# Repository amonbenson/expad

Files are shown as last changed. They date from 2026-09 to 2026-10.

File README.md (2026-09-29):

# expad - Expression Adapter

A four-jack USB MIDI adapter for expression and sustain pedals, built on a Raspberry Pi Pico 2 W.
It works out what is plugged into each jack - whichever contact a pedal's wiper is on, and whether
it is a potentiometer, a switch or a two-wire rheostat - and sends every pedal's position as a MIDI
control change, ~190 times per second. A WiFi access point serves a web interface for watching the
jacks and changing the settings live.

## Hardware

The PCB is the KiCad project in [hardware/](hardware/). Each jack's tip, ring and sleeve (plus the
tip's switch contact, for plug detection) can be switched to a shared 1 kΩ pull-up to the 2.5 V
reference or a 1 kΩ pull-down, and is read back by one of two AD7718 24-bit ADCs. The four
WS2812B LEDs below the jacks glow a dim white while a plug is in but no known pedal is behind it.
A recognised pedal is announced for a second in its own color - purple for an expression pedal,
lime for a footswitch, yellow for a rheostat - after which the LED shows the value it sends, from
dark red at 0 through red, orange and yellow to white at 127. They run off a linear regulator, so
the firmware caps them at ~4% brightness.

## Supported pedals

| Pedal | Cable | Shown as | Value |
|---|---|---|---|
| Expression pedal (potentiometer), wiper on tip or ring | stereo (TRS) | Tracking | wiper position, counting up away from the sleeve |
| Sustain pedal / footswitch | mono (TS) or stereo | Switch | 100% closed, 0% open |
| Two-wire (rheostat) expression pedal | mono or stereo | Rheostat | resistance against the nearest standard value (10k, 25k, 50k ...) |
| Anything else (dual footswitches, other wirings) | | Other pedal | none |

Pedals are recognised within ~0.1 s of being plugged in, and unplugging is noticed just as fast.

- A normally-closed sustain pedal, or an expression pedal wired the other way round, needs
  **Invert**.
- A rheostat pedal on a mono cable first reads as a potentiometer at rest, until its resistance has
  changed by a fifth.
- A potentiometer pedal needs a stereo cable: with a mono one, most pedals short their ring to the
  sleeve, which leaves a resistance that rises and falls again over the travel.
- A mono cable with nothing at the other end reads as a released switch.

## Using it

1. Plug the Pico into a computer over USB. It shows up as a USB MIDI device; by default the
   first two jacks send CC 11 (Expression) and the last two CC 1 (Modulation), all on MIDI
   channel 1.
2. Join the WiFi network **Expression Adapter** (password: the one it was built with, see below).
   Phones, tablets and computers open the interface by themselves as the network's sign-in page;
   otherwise open http://192.168.4.1.
3. Per jack, set the MIDI channel and controller, **Invert**, and the **Range**: move the pedal to
   one end and press **Min**, to the other and press **Max**, so its travel covers the full MIDI
   range. **Drive** bends the response against a pedal's nonlinear track: centered is linear,
   turning it right makes the value rise early in the travel, left late (double-click resets it).
   **Wiper** only matters for pedals whose wiper is on the ring or sleeve and that rest on an
   end stop when plugged in; **Auto** handles the common wirings. The LED slider sets the
   brightness.

The topology panel on the right draws the selected jack's measured network.

## Setup

Needs Rust, Node.js (see `engines` in [web/package.json](web/package.json)) for the web interface,
and a debug probe (e.g. a Raspberry Pi Debug Probe) on the Pico's SWD pins.

```bash
rustup target add thumbv8m.main-none-eabihf
cargo install probe-rs-tools --locked
cp .env.example .env   # then set EXPAD_WIFI_PASSWORD (8-63 characters)
```

## Building and flashing

```bash
cargo run --bin expression_controller   # build, flash and show the log
cargo run --bin expression_controller --features no-wifi   # the same with the radio off
cargo build --no-default-features       # without the web interface (no Node.js needed)
```

The other programs in [src/bin/](src/bin/) test parts of the board:

| Program | What it does |
|---|---|
| `detect_pin_mapping` | checks every contact's switches and ADC input against the wiring table (unplug all jacks) |
| `capture` | holds every contact in one state and logs every ADC input, for noise measurements |
| `adc_characterization` | compares ADC filter rates and SPI settings on a pedal in jack 1 |
| `potentiometer` | reads a pedal in jack 1 and shows its position on the LEDs |
| `rainbow` | LED strip test |
| `midi_loopback` | echoes every USB MIDI message back to the host |
| `web_interface` | the web interface with made-up data |

## Development

```bash
cargo test -p expad-topology --target x86_64-pc-windows-msvc   # solver tests, on your host triple
cargo fmt
cargo clippy --all-features
cd web && npm run dev:mock   # web interface against a simulated device, no hardware needed
```

[AGENTS.md](AGENTS.md) describes the repository in detail, and
[docs/fast-tracking.md](docs/fast-tracking.md) the measurements and design behind the pedal
detection.

## General TODOs
- missing standard trait implementations for all types (Debug, Default, Clone, Copy, PartialEq, Eq, etc.)
- missing with_field builder methods for all config structs
- thiserror (nostd) or similar better error handling

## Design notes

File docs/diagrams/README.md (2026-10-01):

# Diagrams

| File | What it is |
|---|---|
| `jack-monitor-states.tex` | Source: TikZ state diagram of `JackMonitor` (topology/src/monitor.rs) and the output stage of expression_controller.rs |
| `jack-monitor-states.pdf` | Vector export for LaTeX documents |
| `jack-monitor-states.svg` | Vector export for PowerPoint and the web (text converted to outlines) |
| `jack-monitor-states.png` | 600 dpi raster fallback |
| `jack-monitor-overview.tex` | Source: the same as four stages in large type, for slides (`.pdf`, `.svg`, `.png` exports alike) |

## Tools

Everything comes with a standard TeX Live installation; the exports were made with:

- **pdflatex**: pdfTeX 3.141592653-2.6-1.40.29 (TeX Live 2026), turning the `.tex` into the PDF
- **pdftocairo** 26.09.0 (Poppler, bundled with TeX Live on Windows, `brew install poppler` on macOS), turning the PDF into the SVG and PNG
- LaTeX packages: `standalone`, TikZ/PGF 3.1.11a (libraries `arrows.meta`, `positioning`, `calc`,
  `shapes.geometric`), `helvet` (Helvetica), `mathastext`, `lmodern`, `amssymb`

## Rebuilding

From this directory, for each diagram (`jack-monitor-states` or `jack-monitor-overview`):

```bash
name=jack-monitor-states
pdflatex $name.tex
pdftocairo -svg $name.pdf $name.svg
pdftocairo -png -r 600 -singlefile $name.pdf $name
```

`pdflatex` also leaves `.aux` and `.log` files behind; delete them, or pass
`-output-directory=<somewhere else>` and copy the PDF back.

## Using the exports

- **LaTeX**: `\includegraphics[width=\linewidth]{jack-monitor-states.pdf}` (it suits a landscape
  page or the full text width).
- **PowerPoint**: *Insert > Pictures* with the SVG. It stays sharp at any size; *Convert to Shape*
  makes its parts editable, but the text stays outlines - edit the `.tex` source for wording.
- **Slides**: the overview is 32 cm wide, about a 16:9 slide, so at that width its type keeps its
  size (18 pt names, 15 pt text). To reveal it step by step, cover each part with a rectangle in
  the slide's background color: every stage is a column that owns the gap to its left with the
  arrows into it, and the two ways back run in their own strips above and below the columns.

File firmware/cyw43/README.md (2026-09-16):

# CYW43439 firmware blobs

WiFi firmware, country locale matrix (CLM), and NVRAM for the Pico 2 W's CYW43439 chip, embedded by
[src/hal/wifi/access_point.rs](../../src/hal/wifi/access_point.rs).

Copied unmodified from [embassy `cyw43-firmware`](https://github.com/embassy-rs/embassy/tree/embassy-rp-v0.10.0/cyw43-firmware)
(tag `embassy-rp-v0.10.0`), which in turn sources them from
[georgerobotics/cyw43-driver](https://github.com/georgerobotics/cyw43-driver/tree/main/firmware).

Licensed under the [Infineon Permissive Binary License](./LICENSE-permissive-binary-license-1.0.txt).

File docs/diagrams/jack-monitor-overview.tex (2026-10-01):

% Overview of one jack's JackMonitor (topology/src/monitor.rs) and the output stage of
% expression_controller.rs for slides: few words, large type. jack-monitor-states.tex has the
% details.
%
% Build (TeX Live):  pdflatex jack-monitor-overview.tex
%   SVG for PowerPoint:  pdftocairo -svg jack-monitor-overview.pdf jack-monitor-overview.svg
%   PNG fallback:        pdftocairo -png -r 600 -singlefile jack-monitor-overview.pdf jack-monitor-overview
%
% Layout for revealing one part after another: the four stages are columns, read left to right,
% and each one owns the gap to its left with the arrows into it. The two ways back run in their
% own strips, above and below the columns, from border to border. So every part can be covered
% by one rectangle. The canvas is 32 cm wide, so at the width of a 16:9 slide the type keeps its
% size in pt.

\documentclass[tikz, border=10pt]{standalone}
\usepackage[scaled]{helvet}
\renewcommand{\familydefault}{\sfdefault}
\usepackage[T1]{fontenc}
\usetikzlibrary{arrows.meta}

% The palette of jack-monitor-states.tex.
\definecolor{detect}{HTML}{0284C7}      \definecolor{detectFill}{HTML}{F0F9FF}
\definecolor{ident}{HTML}{7C3AED}       \definecolor{identFill}{HTML}{F5F3FF}
\definecolor{follow}{HTML}{059669}      \definecolor{followFill}{HTML}{ECFDF5}
\definecolor{output}{HTML}{D97706}      \definecolor{outputFill}{HTML}{FFFBEB}
\definecolor{unplug}{HTML}{E11D48}
\definecolor{ink}{HTML}{1E293B}
\definecolor{muted}{HTML}{475569}
\definecolor{wire}{HTML}{334155}

% A state's name and its description.
\newcommand{\st}[1]{{\bfseries\fontsize{18}{22}\selectfont\color{ink}#1}}

\tikzset{
  >={Stealth[length=10pt, width=8pt]},
  every node/.style={text=ink},
  group/.style={draw=#1, line width=1.6pt, rounded corners=10pt},
  groupTitle/.style={anchor=north west, font=\bfseries\fontsize{22}{26}\selectfont, text=#1},
  question/.style={anchor=north west, font=\fontsize{16}{19}\selectfont, text=muted},
  state/.style={draw=#1, fill=white, line width=1.6pt, rounded corners=5pt, align=center,
    inner xsep=6pt, inner ysep=7pt, font=\fontsize{15}{18}\selectfont, text=muted},
  trans/.style={->, line width=1.6pt, draw=wire, rounded corners=6pt},
  bus/.style={line width=1.6pt, draw=wire, rounded corners=6pt},
  corridor/.style={->, line width=1.8pt, draw=#1, dash pattern=on 9pt off 5pt, rounded corners=6pt},
  lbl/.style={font=\fontsize{15}{18}\selectfont, text=muted, align=center, inner sep=6pt},
  junction/.style={circle, fill=wire, inner sep=0pt, minimum size=8pt},
}

\begin{document}
\hyphenpenalty=10000
\exhyphenpenalty=10000
\begin{tikzpicture}

  % ---------------------------------------------------------------- plug detection
  \fill[detectFill] (0, 2.4) rectangle (6.2, 13.2);
  \draw[group=detect] (0, 2.4) rectangle (6.2, 13.2);
  \node[groupTitle=detect] at (0.3, 12.9) {Plug detection};
  \node[question] at (0.3, 12.1) {Is a plug in?};

  \node[circle, fill=ink, minimum size=11pt, inner sep=0pt] (start) at (0.5, 10.4) {};
  \node[state=detect, text width=4.0cm] (rails) at (3.74, 10.4)
    {\st{Measure rails}\\ reference levels};
  \draw[trans] (start) -- (rails);

  \node[state=detect, text width=4.0cm] (empty) at (3.74, 7.6)
    {\st{Empty}\\ tip switch polled\\ every 50\,ms};
  \draw[trans] (rails) -- (empty);

  % ---------------------------------------------------------------- identification
  \fill[identFill] (8.4, 2.4) rectangle (15.4, 13.2);
  \draw[group=ident] (8.4, 2.4) rectangle (15.4, 13.2);
  \node[groupTitle=ident] at (8.7, 12.9) {Identification};
  \node[question] at (8.7, 12.1) {What is plugged in?};

  \node[state=ident, text width=4.6cm] (solve) at (11.6, 7.6)
    {\st{Solve}\\ arm pairs driven,\\ every tap read};
  \draw[trans] (empty) -- (solve);
  \node[lbl, anchor=south] at (7.3, 7.6) {plug in};

  \node[state=ident, text width=4.6cm] (classify) at (11.6, 3.9)
    {\st{Classify}\\ which network?};
  \draw[trans] (10.9, 0 |- solve.south) -- (10.9, 0 |- classify.north);
  \draw[trans] (12.3, 0 |- classify.north) -- (12.3, 0 |- solve.south)
    node[lbl, midway, right] {unknown:\\solve again};

  % ---------------------------------------------------------------- following
  \fill[followFill] (17.6, 2.4) rectangle (23.8, 13.2);
  \draw[group=follow] (17.6, 2.4) rectangle (23.8, 13.2);
  \node[groupTitle=follow] at (17.9, 12.9) {Following};
  \node[question] at (17.9, 12.1) {Where is the pedal?};

  \node[state=follow, text width=4.9cm] (potentiometer) at (20.7, 9.9)
    {\st{Potentiometer}\\ wiper read between\\ driven track ends};
  \node[state=follow, text width=4.9cm] (element) at (20.7, 6.9)
    {\st{Switch / rheostat}\\ tip against sleeve};
  \node[state=follow, text width=4.9cm] (open) at (20.7, 3.9)
    {\st{Open plug}\\ waiting for contact};

  \node[junction] (split) at (16.5, 3.9) {};
  \draw[bus] (classify.east) -- (split);
  \draw[bus] (split) -- (16.5, 9.9);
  \draw[trans] (16.5, 9.9) -- (potentiometer.west);
  \draw[trans] (16.5, 6.9) -- (element.west);
  \draw[trans] (split) -- (open.west);

  % ---------------------------------------------------------------- output
  \fill[outputFill] (26.0, 2.4) rectangle (32.0, 13.2);
  \draw[group=output] (26.0, 2.4) rectangle (32.0, 13.2);
  \node[groupTitle=output] at (26.3, 12.9) {Output};
  \node[question] at (26.3, 12.1) {What is sent?};

  \node[state=output, text width=4.6cm] (map) at (29.0, 9.9)
    {\st{Map to value}\\ range, invert, curve};
  \draw[trans] (23.8, 9.9) -- (map.west);
  \node[lbl, anchor=south] at (24.9, 9.9) {position};

  \foreach \name/\title/\y in {midi/USB MIDI/7.6, led/LED/5.8, web/Web interface/4.0} {
    \node[state=output, text width=4.0cm, anchor=west] (\name) at (27.1, \y) {\st{\title}};
    \draw[trans] (26.65, \y) -- (\name.west);
  }
  \draw[bus] (26.65, 0 |- map.south) -- (26.65, 4.0);

  % ---------------------------------------------------------------- ways back
  \draw[corridor=ident] (22.9, 13.2) -- (22.9, 14.1) -- (14.6, 14.1) -- (14.6, 13.2);
  \node[lbl, anchor=south, text=ident] at (18.75, 14.1) {no longer matches: identify again};

  \draw[corridor=unplug] (22.9, 2.4) -- (22.9, 1.3) -- (2.9, 1.3) -- (2.9, 2.4);
  \node[lbl, anchor=north, text=unplug] at (12.9, 1.3) {plug pulled: back to plug detection};

\end{tikzpicture}
\end{document}

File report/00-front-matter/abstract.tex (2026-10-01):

% !TEX root = ../main.tex

\chapter*{Abstract}

\scaffold{
  One paragraph of about ten sentences, no citations, no abbreviation without its full form (writing guide, section 3.2). Write it last. Sentence order and content:
  \begin{enumerate}
    \item Context: expression pedals are passive potentiometers operated by foot that musicians use to change a sound parameter continuously while both hands stay on the instrument.
    \item Problem: no wiring standard exists; the wiper sits on the tip or on the ring, some pedals have two wires only, and a pedal on a mismatched input reads reversed, nonlinear or not at all.
    \item What the project presents: a four-jack interface that identifies what is plugged in electrically and sends its position as a MIDI control change over USB.
    \item Parts, as one sentence with a dash-enclosed enumeration: analog switches that pull every jack contact up or down through \qty{1}{\kilo\ohm} resistors, two 24-bit sigma-delta analog-to-digital converters (written out, since the abstract defines no abbreviations) referenced to the same \qty{2.5}{\volt} rail, and a Raspberry Pi Pico~2~W running firmware in Rust.
    \item Central method: each pedal is modelled as a three-terminal star network, whose arm resistances follow from voltages measured while one contact is driven high, one low and the third left floating.
    \item How it follows the pedal: once identified, a potentiometer is read with a single conversion of its wiper between its driven track ends; switches and two-wire rheostats are followed through the tip.
    \item Development and verification: the solver and the per-jack state machine run and are tested on the host against a simulated network; the hardware was verified with a self-test and oscilloscope measurements.
    \item Results, with numbers: about 188 position updates per second for a single pedal (2.6 for repeated full identification), recognition within 65 to \qty{95}{\milli\second} (about \qty{300}{\milli\second} when the reference levels are re-measured first), and a position noise of \num{274} parts per million, about 1/29 of a MIDI step.
    \item Concluding sentence: what the results show, i.e. that an unknown passive pedal can be identified in place with switchable pull resistors and a slow high-resolution ADC, and followed fast enough for live use.
  \end{enumerate}
}

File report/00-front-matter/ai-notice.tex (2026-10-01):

% !TEX root = ../main.tex

\chapter*{Notice on the Use of AI Tools}

\scaffold{
  One paragraph, one sentence per tool: product name, manufacturer, version, purpose, citation (writing guide, section 3.1). Name the concrete work products each tool contributed to and cite the repository \cite{benson2026expad} where they live. The facts below are taken from the Claude Code session logs of the project.

  \begin{itemize}
    \item Anthropic Claude Code \cite{anthropic2026claudecode}, versions 2.1.227 to 2.1.284, with the models Claude Opus~5.5 \cite{anthropic2026opus55}, Claude Opus~5 \cite{anthropic2026opus5} and Claude Sonnet~5 \cite{anthropic2026sonnet5}. Purposes: implementation of the firmware (drivers for the AD7718, the pull switches, the LEDs, USB MIDI and WiFi; the port of the solver from the simulator \cite{benson2026topologysim}; the jack state machine and its host tests), the web interface, parsing the KiCad netlist into the board table, the evaluation scripts for the oscilloscope data (\code{measurements/create\_plots.py}, OCR extraction of scope statistics), the TikZ state diagram, the project documentation, the measurement guide, and the scaffold of this report.
    \item Anthropic Claude (claude.ai chat): early concept research on the measurement circuit, the network identification and component selection.
  \end{itemize}

  Final sentence: all AI-generated content was reviewed and verified by the author, who takes full responsibility for the final content of this work.
}

\openquestion{AI tools in the chats and in the text}{
  The model and version used in the claude.ai chats are not recorded in the repository. Name them. State also whether an AI tool is used for grammar and spell checking of the final text, as in the reference report.
}

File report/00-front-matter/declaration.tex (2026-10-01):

% !TEX root = ../main.tex
% Fixed text of the institution; only place, date and signature change.

\chapter*{Eidesstattliche Erklärung}
\thispagestyle{empty}

\begin{german}
Hiermit versichere ich, dass ich die vorliegende Arbeit eigenständig ohne Hilfe Dritter und ausschließlich unter Verwendung der aufgeführten Quellen und Hilfsmittel angefertigt habe. Alle Stellen die den benutzten Quellen und Hilfsmitteln unverändert oder sinngemäß entnommen sind, habe ich als solche kenntlich gemacht.

Sofern generische KI-Tools verwendet wurden, habe ich Produktnamen, Hersteller, die jeweils verwendete Softwareversion und die jeweiligen Einsatzzwecke (z.\,B. sprachliche Überprüfung und Verbesserung der Texte, systematische Recherche) benannt. Ich verantworte die Auswahl, die Übernahme und sämtliche Ergebnisse des von mir verwendeten KI-generierten Outputs vollumfänglich selbst.

Die Satzung zur Sicherung guter wissenschaftlicher Praxis an der TU Berlin vom 8. März 2017 habe ich zur Kenntnis genommen.

\vspace{5mm}
Berlin, \today

\vspace{20mm}
\rule{80mm}{0.4pt}\\
(\authorname)
\end{german}

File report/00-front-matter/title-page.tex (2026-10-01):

% !TEX root = ../main.tex

\begin{titlepage}
  \centering
  

  \vspace{10mm}
  {\large\bfseries
    Technische Universität Berlin\\
    Faculty IV Electrical Engineering and Computer Science\\
    Institute of Energy and Automation Technology\\
    Chair of Sensor and Actuator Systems\par}

  \vspace{10mm}
  {\Huge\bfseries \documenttype\par}

  \vspace{10mm}
  {\LARGE\bfseries \reporttitle\par}

  \vspace{10mm}
  In the course\\
  \coursename\\
  \submissiondate

  \vspace{20mm}
  \authorname\ (\matriculationnumber)

  \vspace{20mm}
  Supervisor: \supervisor\\
  Assisted by \assistant

  \vfill
\end{titlepage}

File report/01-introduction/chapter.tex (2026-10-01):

% !TEX root = ../main.tex

\chapter{Introduction}
\label{ch:introduction}

\scaffold{
  Purpose of the chapter (writing guide, section 3.3): background, the niche of the project, motivation and the minimum of fundamentals; no figures, no results, no chapter roadmap. Five paragraphs. The reader is electronics-literate but does not know what an expression pedal is.
}

\scaffold{
  \textbf{Paragraph 1, the field.} Musicians who play an instrument with both hands, a keyboard or a guitar, change sound parameters such as volume, filter cutoff or effect intensity with their feet. An expression pedal is the continuous variant of these foot controllers, in contrast to a sustain pedal, which is a switch \cite{mission2014expression}. Expression pedals are connected to keyboards, amplifiers, effect units and MIDI controllers \cite{mission2014expression}; to control software on a computer, the pedal position has to reach the computer as MIDI data. By the end of the paragraph the reader knows what an expression pedal is used for and why it is connected to a computer at all.
}

\scaffold{
  \textbf{Paragraph 2, the underlying structure.} Inside, an expression pedal is passive: a potentiometer whose wiper is moved by the treadle, connected to a \qty{6.35}{\milli\metre} jack. The connected device supplies a voltage across the track and reads the wiper voltage back as the position \cite{mission2014expression, nonlinearlabs2026pedals}. Give the typical track resistance of \qtyrange{5}{50}{\kilo\ohm}, with some devices expecting \qty{100}{\kilo\ohm} to \qty{500}{\kilo\ohm} \cite{mission2014expression}. Introduce the terms tip, ring and sleeve here, once, because the rest of the report uses them; the term \emph{contact} denotes one of them.
}

\scaffold{
  \textbf{Paragraph 3, the difficulty.} No standard defines which contact carries the wiper \cite{mission2014expression}. Two TRS wirings dominate: the wiper on the tip (Boss/Roland, \enquote{tip-active}) and the wiper on the ring (Yamaha, \enquote{ring-active}) \cite{nonlinearlabs2026pedals}; further pedals connect only tip and sleeve, as a variable resistor (rheostat) \cite{nonlinearlabs2026pedals, mission2014expression}. A pedal on an input that expects another wiring reads reversed, with a limited range, or not at all \cite{mission2014expression}. Manufacturers mitigate this with polarity switches on the pedal \cite{maudio2026exp, nonlinearlabs2026pedals}, which the user has to know about and set. State in one sentence that the pedal itself cannot tell which convention it follows; only a measurement of its network can.
}

\scaffold{
  \textbf{Paragraph 4, \enquote{Concretely, \ldots}.} Concretely, this project builds an interface with four jacks that identifies the network behind every jack electrically, without user input, and then follows the pedal position and sends it as a MIDI control change over USB \cite{benson2026proposal}. Name the four kinds of pedal it supports: potentiometer pedals of either wiring, sustain switches and two-wire rheostats, on mono or stereo cables. Mention in half a sentence that a WiFi web interface shows the identified network and holds the per-jack settings.
}

\scaffold{
  \textbf{Paragraph 5, method and tools.} The identification applies the principle of automatic component testers, which drive the pins of an unknown part through known resistors and read their voltages with an analog-to-digital converter (ADC) \cite{frejek2011avr, kuebbeler2023transistortester}. The solver and the per-jack state machine were first developed in an interactive simulator \cite{benson2026topologysim} and are tested on the host computer against a simulated network before they run on the device \cite{benson2026expad}; the device itself was verified with a self-test and with oscilloscope measurements.
}

\openquestion{Report title}{
  The proposal is titled \enquote{Self-Configuring Interface for Expression Pedals}, all three presentations \enquote{Adapter for Expression Pedals}. Choose one title for the report and use it for the title page and the PDF metadata (\code{00-front-matter/metadata.tex}). Also add submission date, supervisor and assistant there.
}

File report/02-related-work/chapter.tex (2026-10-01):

% !TEX root = ../main.tex

\chapter{Related Work}
\label{ch:related-work}

\scaffold{
  Writing guide, section 3.4: one section per group of existing work; the group name in italics at its definition; two or more examples with manufacturer and citation; each section ends with one sentence placing the project against the group. Two to five sentences per section, no figures.
}

\section{Pinout Workarounds}
\label{sec:related-pinout-workarounds}

\scaffold{
  Two groups. \emph{Switchable pedals} carry a polarity or pinout selector that swaps tip and ring, for example the M-Audio EX-P \cite{maudio2026exp} and some Moog pedals \cite{nonlinearlabs2026pedals}. \emph{Configurable inputs} move the choice to the receiving device: the Nonlinear Labs C15 offers presets per pedal type and wiring and learns the range of a pedal by auto-ranging, which only completes after the pedal has been moved across part of its travel \cite{nonlinearlabs2026pedals}; MIDI devices with a calibration routine map the measured minimum and maximum of a pedal to the full MIDI range \cite{mission2014expression}. Closing sentence: both groups rely on the user to know or select the wiring, while this project measures it.
}

\section{Pedal-to-MIDI Interfaces}
\label{sec:related-pedal-interfaces}

\scaffold{
  Two groups. \emph{Fixed-wiring interfaces}, mostly do-it-yourself projects on a microcontroller, read one wiring and send its position as USB MIDI \cite{gaspar2026diyexpression}. \emph{Pedal-sensing interfaces} detect the type of pedal: the Audiofront MIDI Expression loads a preset for the kind of pedal that is plugged in and offers polarity-reversing inputs \cite{audiofront2026midiexpression}, and the DOREMiDi MPC-10 detects expression pedals of both polarities, sustain pedals and dual switches \cite{doremidi2026mpc10}. Neither documents how its detection works or which networks it distinguishes. Closing sentence: this project identifies the arm resistances of any three-terminal network and derives the pedal type and wiring from them, so that the classification and its limits are documented and testable.
}

\section{Automatic Component Identification}
\label{sec:related-component-identification}

\scaffold{
  The \emph{AVR transistor tester} by Frejek identifies the type and pinout of an unknown part on three test pins: every pin is connected to microcontroller port pins through a \qty{680}{\ohm} and a \qty{470}{\kilo\ohm} resistor and read by the ADC, and the firmware tries the drive combinations \cite{frejek2011avr}; Kübbeler extended it to further part types \cite{kuebbeler2023transistortester}. The underlying question, which network lies between accessible terminals, is the discrete inverse problem for resistor networks \cite{curtis1990determining, curtis2000inverse}: a three-terminal resistive network is externally equivalent to a star (wye) or triangle (delta) of three resistors \cite{kennelly1899equivalence}, and only such an equivalent, not the internal topology, can be recovered from terminal measurements \cite{borcea2012resistor}. Closing sentence: this project applies the component-tester principle to a pedal at run time, repeatedly, and adds a second mode that follows an identified pedal with a single conversion.
}

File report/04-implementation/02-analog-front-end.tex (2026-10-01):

% !TEX root = ../main.tex

\section{Analog Front End}
\label{sec:analog-front-end}

\scaffold{
  \textbf{Paragraph 1, the circuit.} Link: \cref{sec:design-history} explained why switches replaced the buffers. Walk through \cref{fig:frontend-final} for one jack, in the order the control signal passes: the 74HC595 \cite{ti2026sn74hc595} (U6) receives the drive pattern over SPI and latches it; its outputs select the switches of U15, which connect a contact to R50 (\qty{1}{\kilo\ohm}, \qty{0.1}{\percent}) and the \qty{2.5}{\volt} rail, and of U19, which connect it to R54 and ground. Each contact reaches its ADC input through R15--R18 (\qty{10}{\kilo\ohm}) with C23--C26 (\qty{10}{\nano\farad}) to ground. The four shift registers form one chain from the microcontroller to the fourth jack; their output enable is pulled high, so all switches stay open until the firmware writes the first pattern. Mention that the drive enum in the firmware makes it impossible to close the pull-up and pull-down switch of one contact at the same time.
}

\begin{figure}[htbp]
  \centering
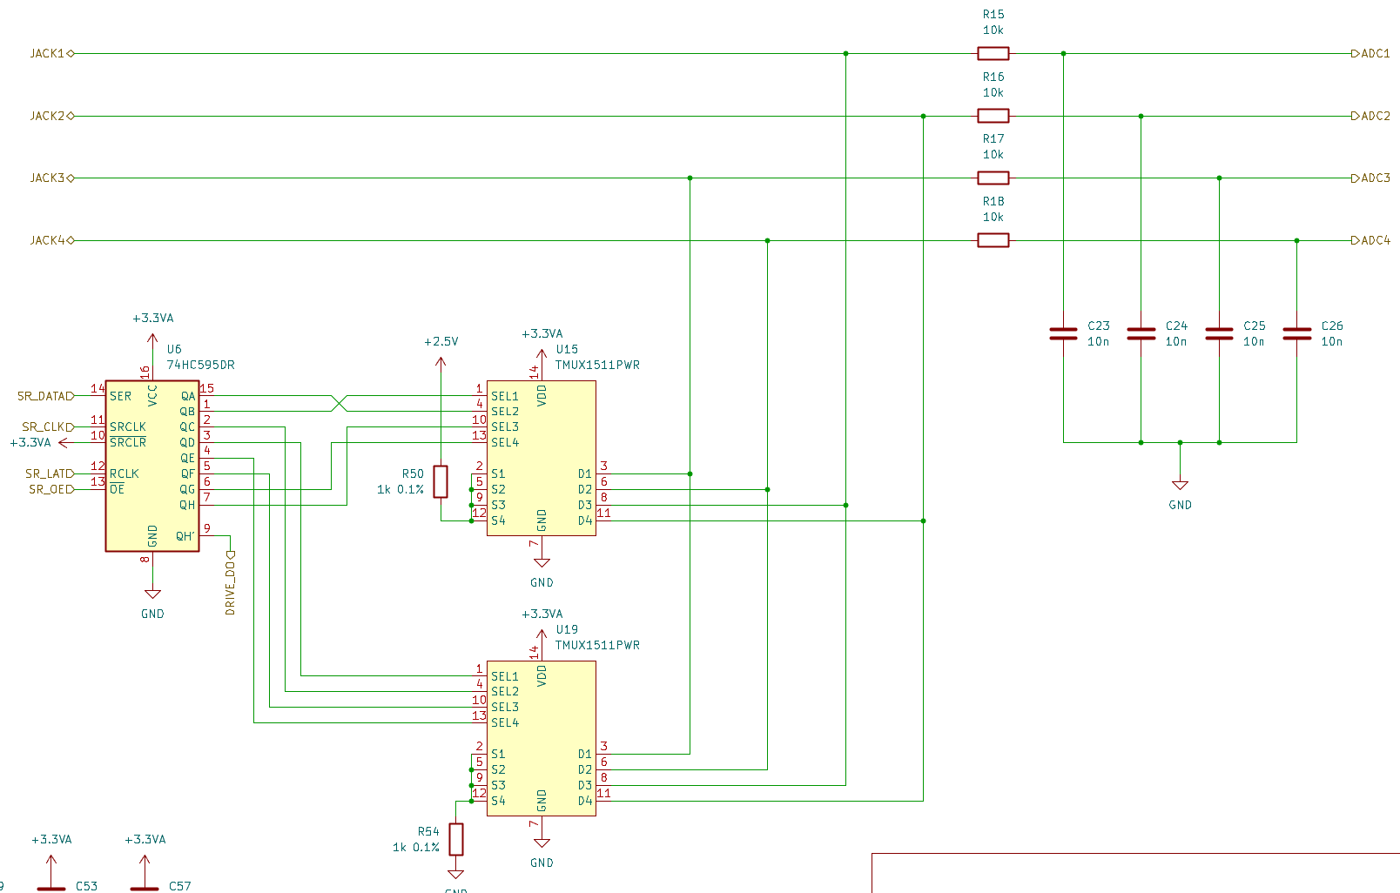
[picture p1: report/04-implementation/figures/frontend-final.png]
  
  \titledcaption{Analog Front End of One Jack}{\scaffoldinline{Name U6, U15, U19, R50, R54, R15--R18 and C23--C26 and their role; explain that JACK1--JACK4 are the four contacts of one jack (tip, ring, sleeve, tip switch, check the order against \code{src/board.rs}) and ADC1--ADC4 their ADC inputs. Source: KiCad sheet \code{hardware/AnalogQuadChannel.kicad\_sch}.}}
  \label{fig:frontend-final}
\end{figure}

\scaffold{
  \textbf{Paragraph 2, settling.} When the drive pattern changes, a floating contact charges the filter capacitor through the pedal and the filter resistor. Present \cref{eq:settling}: the firmware waits two time constants, between \qty{1}{\milli\second} and \qty{400}{\milli\second}, with $R_\mathrm{net}$ the resistance of the network through which the floating contact charges, known from the previous solve (an unknown network is assumed to be \qty{100}{\kilo\ohm}). Compute $\tau$ for a \qty{10}{\kilo\ohm} pedal (about \qty{0.2}{\milli\second}) and a \qty{500}{\kilo\ohm} pedal (about \qty{5}{\milli\second}). Refer to \cref{sec:results-settling} for the measured time constant.
}

\begin{equation}
  t_\mathrm{settle} = 2\,\tau,
  \qquad
  \tau = \bigl(R_\mathrm{net} + R_\mathrm{f}\bigr)\,C_\mathrm{f},
  \qquad
  \qty{1}{\milli\second} \leq t_\mathrm{settle} \leq \qty{400}{\milli\second}
  \label{eq:settling}
\end{equation}

\scaffold{
  \textbf{Paragraph 3, choice of the pull resistance.} The pull resistance trades position resolution against current resolution: across a pedal of resistance $R$ lies $U\,R/(R + 2R_\mathrm{p})$, across each pull resistor $U\,R_\mathrm{p}/(R + 2R_\mathrm{p})$. Present \cref{tab:pull-resistance} and draw the conclusion: the position uses the span and is fine with any value; only the total resistance of high-value pedals depends on the drop. With \qty{1}{\kilo\ohm} and \qty{0.4}{\milli\volt} noise every pedal up to about \qty{500}{\kilo\ohm} still resolves; \qty{4.7}{\kilo\ohm} would be the value to fit if accurate totals of 250 to \qty{500}{\kilo\ohm} pedals mattered (\cref{ch:conclusion}).
}

\begin{table}[htbp]
  \centering
  \titledcaption{Voltage Span and Pull Drop}{\scaffoldinline{Explain that each cell gives the voltage across the pedal and the drop across one pull resistor for a \qty{2.5}{\volt} rail; the fitted value is \qty{1}{\kilo\ohm}. Source: \code{docs/fast-tracking.md}.}}
  \label{tab:pull-resistance}
  \begin{tabular}{@{}l *{3}{c}@{}}
    \toprule
    \textbf{Pull resistance} & \textbf{\qty{10}{\kilo\ohm} pedal} & \textbf{\qty{100}{\kilo\ohm} pedal} & \textbf{\qty{500}{\kilo\ohm} pedal} \\
    \midrule
    \qty{1}{\kilo\ohm} (fitted) & \qty{2.08}{\volt} / \qty{208}{\milli\volt} & \qty{2.45}{\volt} / \qty{24}{\milli\volt} & \qty{2.49}{\volt} / \qty{5}{\milli\volt} \\
    \qty{2.2}{\kilo\ohm} & \qty{1.74}{\volt} / \qty{382}{\milli\volt} & \qty{2.40}{\volt} / \qty{53}{\milli\volt} & \qty{2.48}{\volt} / \qty{11}{\milli\volt} \\
    \qty{4.7}{\kilo\ohm} & \qty{1.29}{\volt} / \qty{606}{\milli\volt} & \qty{2.29}{\volt} / \qty{107}{\milli\volt} & \qty{2.45}{\volt} / \qty{23}{\milli\volt} \\
    \qty{10}{\kilo\ohm} & \qty{0.83}{\volt} / \qty{833}{\milli\volt} & \qty{2.08}{\volt} / \qty{208}{\milli\volt} & \qty{2.45}{\volt} / \qty{49}{\milli\volt} \\
    \bottomrule
  \end{tabular}
\end{table}

\openquestion{Choice of 1 kOhm}{
  Was \qty{1}{\kilo\ohm} chosen with the analysis of \cref{tab:pull-resistance} in mind, or was the analysis done afterwards on the finished board? The answer decides whether paragraph~3 describes a design decision or a later evaluation.
}

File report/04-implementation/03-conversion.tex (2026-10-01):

% !TEX root = ../main.tex

\section{Analog-to-Digital Conversion}
\label{sec:conversion}

\scaffold{
  \textbf{Paragraph 1, the ADCs.} Two AD7718 \cite{adi2001ad7718} read the 16 contacts (\cref{fig:adc}): U4 the two jacks on the left of the PCB, U5 the two on the right; the case order of the firmware numbers the jacks from J5 to J2 because the PCB is mounted upside down. Each ADC runs in ten-channel pseudo-differential mode against AINCOM at ground, since the second jack on each chip uses AIN9, which doubles as a reference input in the eight-channel mode. AIN6 is tied to ground and AIN10 to the \qty{2.5}{\volt} rail on both chips, which gives a self-test of the whole conversion path (\cref{sec:results-self-test}). Each chip has its own \qty{32.768}{\kilo\hertz} crystal (Y1, Y2) with \qty{18}{\pico\farad} load capacitors. Both share SPI0 at \qty{4}{\mega\hertz} with separate chip-select and ready lines.
}

\begin{figure}[htbp]
  \centering
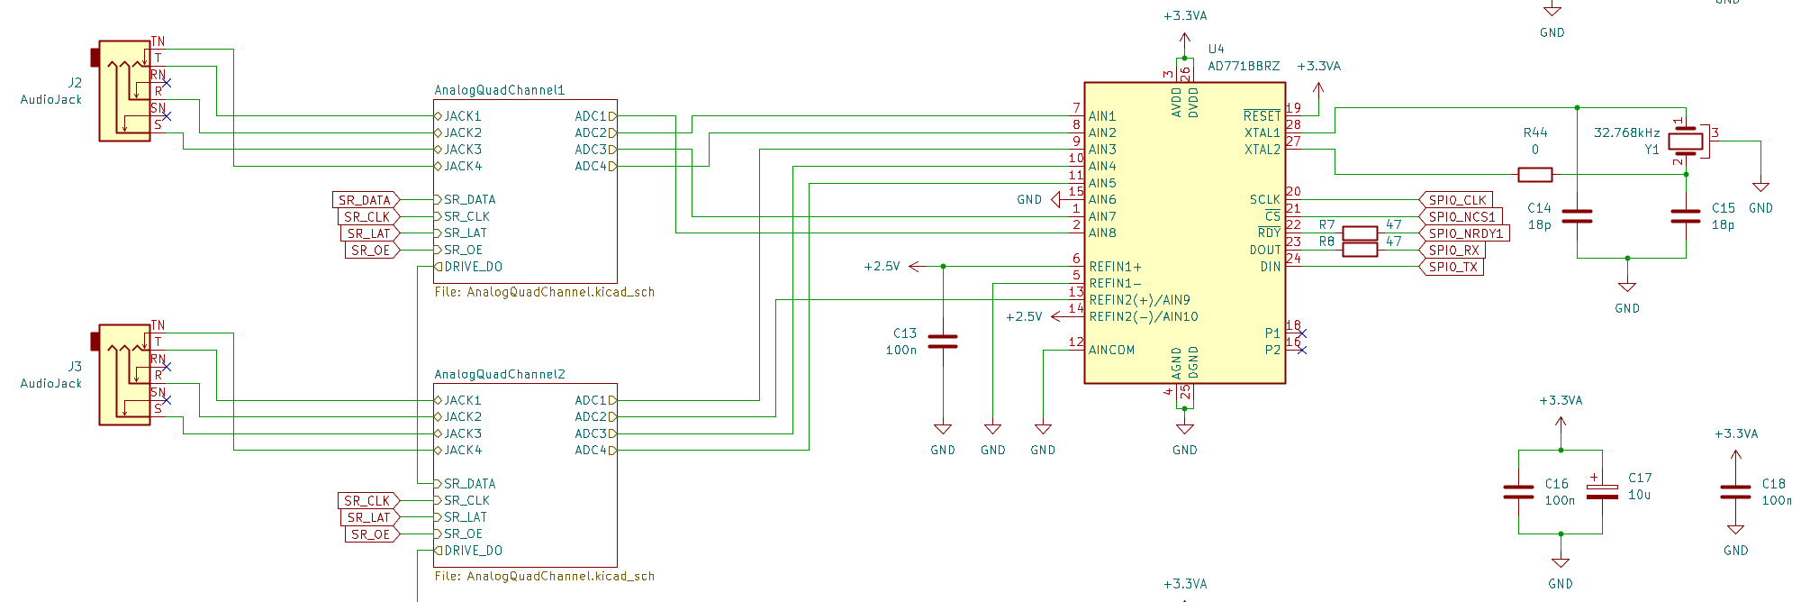
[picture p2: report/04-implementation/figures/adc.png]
  
  \titledcaption{ADCs}{\scaffoldinline{Name U4 and U5, the crystals, the reference connection to the \qty{2.5}{\volt} rail, the self-test inputs AIN6 and AIN10, and the SPI and ready signals to the microcontroller. Source: KiCad sheet \code{hardware/AnalogFrontend.kicad\_sch}; enlarge or split if the labels are not readable at text width.}}
  \label{fig:adc}
\end{figure}

\scaffold{
  \textbf{Paragraph 2, the filter and its settling.} The AD7718 is a sigma-delta ADC with a sinc\textsuperscript{3} decimation filter \cite{adi2001ad7718}. With chopping disabled, which the firmware uses for channel throughput, the output rate is programmable from \qty{16.06}{\hertz} to \qty{1365.33}{\hertz}; a channel change counts as a synchronized step and needs three conversion periods to settle \cite{adi2001ad7718}. Explain the consequence that shapes the whole firmware: every reading that changes the channel costs three conversion periods, independent of how fast the analog input settles. Mention that the datasheet requires recalibration after gain or temperature changes in this mode, and that the firmware calibrates once at start-up and measures its own rails (\cref{sec:pair-measurement}).
}

\scaffold{
  \textbf{Paragraph 3, the SPI interface.} Every SPI and shift-register line has a \qty{47}{\ohm} series resistor at its driver to slow the edges and damp reflections on the two-layer board. A chip-select guard of \qty{10}{\micro\second} before and after every transfer was found sufficient on the PCB, where the breadboard needed \qty{50}{\micro\second} and showed outlying codes otherwise; the firmware skips the control-register write when the channel does not change. Two driver bugs found on the breadboard are worth one sentence each: the ready line was polled before the chip had registered the conversion command, which corrupted the calibration, and toggling chip select too quickly made the chip lose synchronization.
}

\openquestion{Choice of 47 Ohm}{
  A design session recommended \qtyrange{22}{33}{\ohm}; the board has \qty{47}{\ohm}. Give the reason for the value.
}

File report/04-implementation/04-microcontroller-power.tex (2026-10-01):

% !TEX root = ../main.tex

\section{Microcontroller and Power Supply}
\label{sec:microcontroller-power}

\scaffold{
  \textbf{Paragraph 1, microcontroller.} The Raspberry Pi Pico~2~W module \cite{rpi2026pico2w} carries the RP2350 \cite{rpi2026rp2350} and a CYW43439 WiFi chip. Walk through \cref{fig:microcontroller}: SPI0 to the ADCs (clock GPIO18, TX GPIO19, RX GPIO16, chip selects GPIO17 and GPIO20, ready GPIO21 and GPIO22), SPI1 to the shift-register chain (clock GPIO14, data GPIO15, latch GPIO13, output enable GPIO11), and the LED data line on GPIO6 through a 74AHCT1G125 level shifter, since the WS2812B \cite{worldsemi2026ws2812b} expects a \qty{5}{\volt} logic level. The module's own \qty{3.3}{\volt} regulator is not connected to the board rail, and VBUS is unconnected.
}

\begin{figure}[htbp]
  \centering
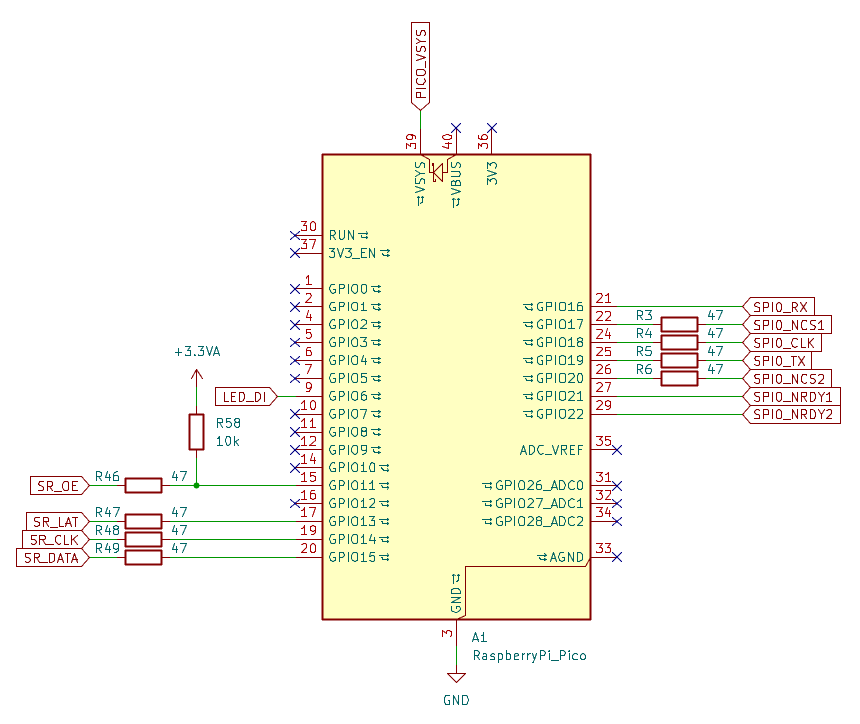
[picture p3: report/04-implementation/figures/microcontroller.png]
  
  \titledcaption{Microcontroller}{\scaffoldinline{Name the two SPI buses, the \qty{47}{\ohm} series resistors R3--R6 and R46--R49, the LED data line and the unconnected supply pins. Source: KiCad sheet \code{hardware/Microcontroller.kicad\_sch}.}}
  \label{fig:microcontroller}
\end{figure}

\scaffold{
  \textbf{Paragraph 2, power input.} Walk through the left part of \cref{fig:power-supply}: barrel jack, resettable fuse MF-MSMF050-2 against overcurrent, bidirectional TVS diode SMBJ15CA against voltage spikes, and the P-channel MOSFET DMP3099L as reverse-polarity protection, its gate pulled to ground through \qty{100}{\kilo\ohm} and clamped by a \qty{15}{\volt} Zener diode. Give the reason for each part in a subordinate clause.
}

\scaffold{
  \textbf{Paragraph 3, rails.} Three ADP7142 LDOs \cite{adi2025adp7142} supply \qty{5}{\volt} (LEDs, level shifter and the Pico's VSYS through a Schottky diode that prevents back-feeding when the Pico's USB is connected), \qty{3.3}{\volt} (ADCs, shift registers, switches) and \qty{2.5}{\volt}. The \qty{2.5}{\volt} rail is cascaded from the \qty{3.3}{\volt} rail rather than from the input, so the reference sits behind two regulators. Solder jumpers JP1--JP3 between each LDO and its rail allow the current of every rail to be measured separately. One consequence for operation: the measurement rails derive only from the barrel jack, so USB alone powers only the microcontroller.
}

\scaffold{
  \textbf{Paragraph 4, LED power budget.} The \qty{5}{\volt} LDO delivers at most \qty{200}{\milli\ampere} \cite{adi2025adp7142} and is shared by the four LEDs and the Pico; four LEDs at full white would draw about \qty{240}{\milli\ampere}. The LED driver therefore scales every frame to at most 10 of 255 per color channel, about \qty{4}{\percent}, at the lowest driver level, so that no setting can exceed it.
}

\openquestion{LED limit}{
  The final presentation states a limit of about \qty{20}{\percent} (51 of 255); the firmware was later reduced to 10 of 255. Was the reduction made for the power budget, for visual brightness, or because of the WiFi tests? State the final value in the text.
}

\begin{figure}[htbp]
  \centering
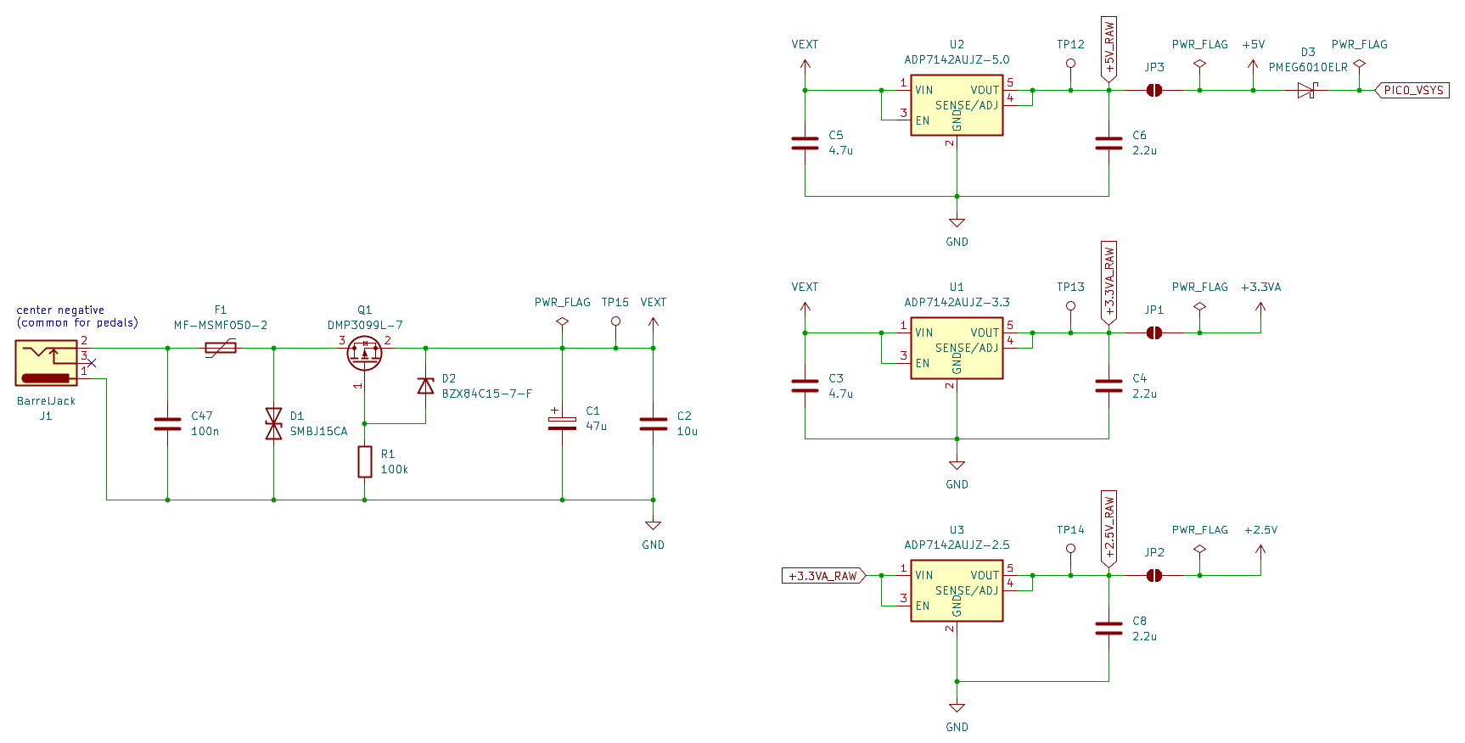
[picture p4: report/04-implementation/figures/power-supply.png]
  
  \titledcaption{Power Supply}{\scaffoldinline{Name the protection chain (F1, D1, Q1 with R1 and D2), the three LDOs U1--U3 with their output voltages, the cascade of U3 from the \qty{3.3}{\volt} rail, the solder jumpers JP1--JP3 and the Schottky diode D3. Source: KiCad sheet \code{hardware/Power.kicad\_sch}.}}
  \label{fig:power-supply}
\end{figure}

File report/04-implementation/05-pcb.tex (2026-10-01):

% !TEX root = ../main.tex

\section{PCB Layout and Assembly}
\label{sec:pcb}

\scaffold{
  \textbf{Paragraph 1, layout.} Describe \cref{fig:pcb-layout}: a two-layer board with 149 footprints, the four jacks along one edge, the jack blocks repeated four times, the power section with one copper fill per rail and the regulators between them. Ground is poured on both layers; the power input section has its own pour on the same net. 15 test points sit on the signals the measurements of \cref{ch:results} need: the shift-register lines (TP1--TP4), SPI0 with both chip selects and ready lines (TP5--TP11) and the four rails (TP12--TP15).
}

\begin{figure}[htbp]
  \centering
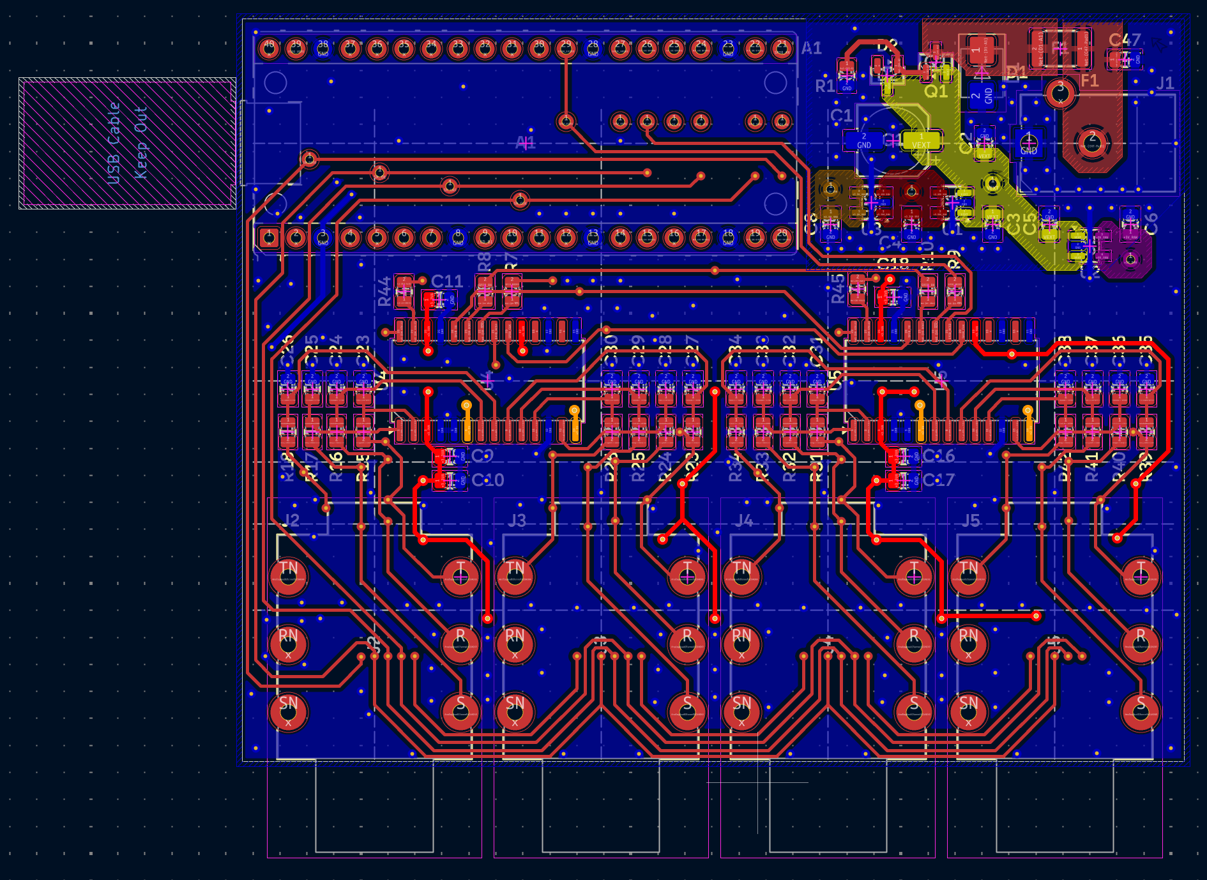
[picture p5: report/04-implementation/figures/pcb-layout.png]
  
  \titledcaption{PCB Layout}{\scaffoldinline{Name the regions (jacks, four channel blocks, ADCs, microcontroller, power section) and the two copper layers shown. Source: KiCad \code{hardware/ExpressionController.kicad\_pcb}.}}
  \label{fig:pcb-layout}
\end{figure}

\scaffold{
  \textbf{Paragraph 2, assembly.} The top side was soldered by hand in separate blocks, the power supply first, and every rail was checked before the next block was populated; the bottom side was assembled with a stencil (first use for the author). The TMUX1511 in TSSOP-14 were the most difficult parts. Show \cref{fig:assembly}. The board-level self-test passed on its first run (\cref{sec:results-self-test}).
}

\begin{figure}[htbp]
  \centering
  \begin{subfigure}[t]{0.32\linewidth}
    \centering
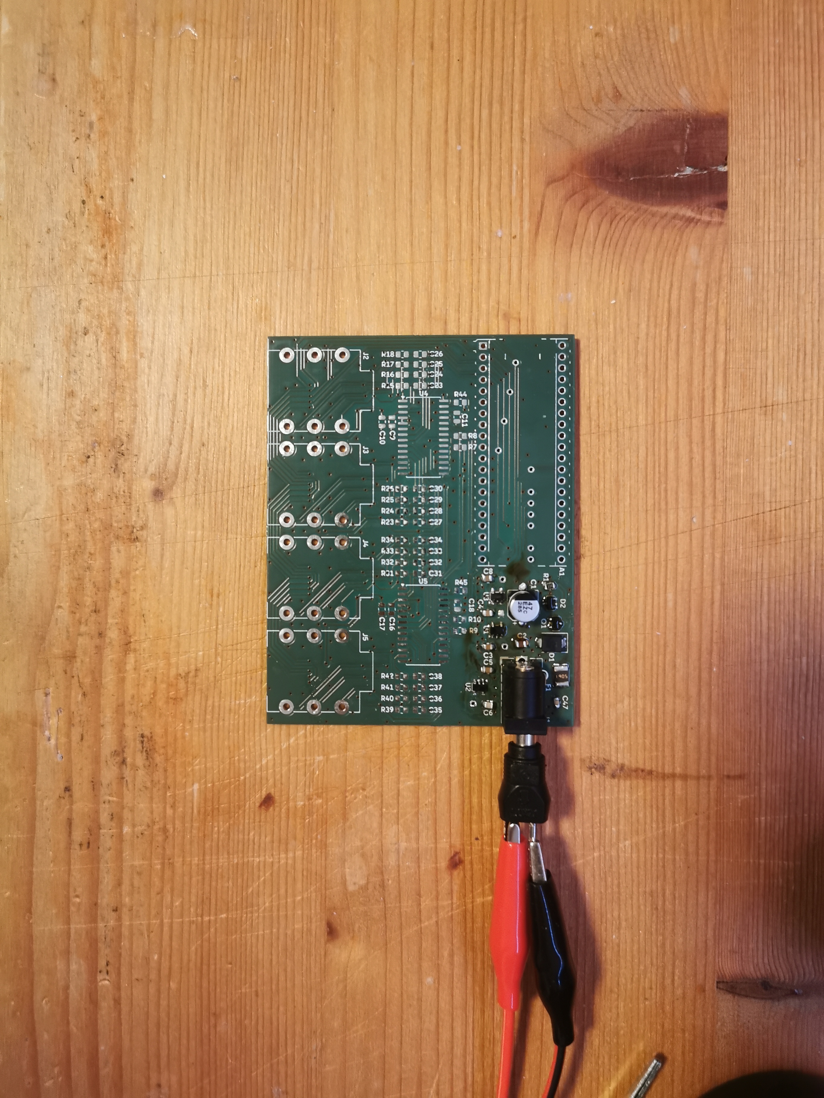
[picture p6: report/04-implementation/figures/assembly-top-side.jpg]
    
    \caption{Power Supply Populated}
    \label{fig:assembly-top-side}
  \end{subfigure}%
  \hfill%
  \begin{subfigure}[t]{0.64\linewidth}
    \centering
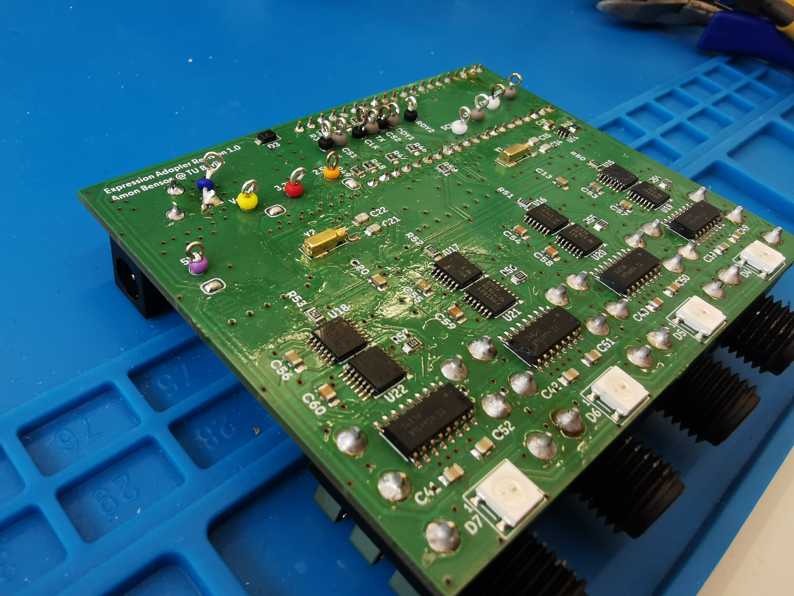
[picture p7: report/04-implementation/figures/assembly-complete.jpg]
    
    \caption{Assembled Board}
    \label{fig:assembly-complete}
  \end{subfigure}
  \titledcaption{PCB Assembly}{\scaffoldinline{(a) first assembly stage, check what is populated; (b) the assembled board with the switches, shift registers, ADCs and color-coded test points. Photos of the author; further photos in the folder \enquote{Final Images}.}}
  \label{fig:assembly}
\end{figure}

\openquestion{Board facts}{
  Give the board outline (about \qtyproduct{89 x 70}{\milli\metre} from the ground pour, not measured), the manufacturer of PCB and stencil, and the date the boards were ordered and arrived (git history: final assembly files 6~September, \enquote{after final fab order} 16~September, first firmware on the board 25~September~2026).
}

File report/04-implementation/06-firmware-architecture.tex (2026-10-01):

% !TEX root = ../main.tex

\section{Firmware Architecture}
\label{sec:firmware-architecture}

\scaffold{
  \textbf{Paragraph 1, language and framework.} The firmware is written in Rust \cite{rust2026} without the standard library and uses the asynchronous Embassy framework \cite{embassy2026} for the RP2350: drivers wait for interrupts as futures, so USB, WiFi, the LEDs and the measurement run as concurrent tasks on one core. The source is in the project repository \cite{benson2026expad}. One sentence on why this matters for the report: a stalled task cannot block the measurement, which became relevant for USB (\cref{sec:output}).
}

\scaffold{
  \textbf{Paragraph 2, two crates and their layers.} Walk through the layers: \code{board} is the only module that knows the PCB (pins, chips, which ADC channel reads which contact); the hardware abstraction layer drives chips (AD7718, shift registers and switches, LEDs, USB, WiFi) without knowing jacks; the scanner runs the measurement on the hardware; the separate library \code{expad-topology} holds the solver arithmetic of \cref{ch:measurement-principle} and the per-jack state machine and knows neither board nor chips. Present \cref{fig:firmware-overview} as the overview of the state machine's four stages and the output.
}

\begin{figure}[htbp]
  \centering
  
  \titledcaption{Firmware Overview}{\scaffoldinline{Name the four stages per jack (plug detection, identification, following, output) and the two ways back (re-identification when the pedal no longer matches, plug detection when the plug is pulled). Source: \code{docs/diagrams/jack-monitor-overview.tex}.}}
  \label{fig:firmware-overview}
\end{figure}

\scaffold{
  \textbf{Paragraph 3, development on the host.} The solver was first developed in an interactive simulator in TypeScript, shown at milestone~2 \cite{benson2026topologysim}, and then ported to Rust. Because \code{expad-topology} has no hardware dependency, it compiles for the host, where its tests drive the solver against a simulated star network and the state machine against a simulated jack in simulated time (52 tests at the final state, covering plugging, unplugging, end stops, mono and stereo plugs, switches, rheostats, resistive wipers and noise). Give the example that justified this effort: the tests ported from the simulator showed that the first port drove the pairs with high and low swapped, which half of the tests detected before the code ever ran on hardware. Every later solver fix in this report came with a test that fails without it.
}

\scaffold{
  \textbf{Paragraph 4, board-level tools.} Besides the controller firmware, the repository contains small programs that each run on the board alone, the most important being the pin-mapping self-test (\cref{sec:results-self-test}), a capture tool that holds a drive pattern and records every ADC input, and the ADC characterization of \cref{sec:update-rate}. Refer to \cref{tab:binaries} in the appendix for the full list.
}

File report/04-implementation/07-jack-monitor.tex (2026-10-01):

% !TEX root = ../main.tex

\section{Jack Monitor}
\label{sec:jack-monitor}

\scaffold{
  \textbf{Paragraph 1, interface of the monitor.} One \emph{jack monitor} per jack implements \cref{sec:plug-detection,sec:following} as a state machine. It never touches hardware: it hands out one reading at a time (the drive of each of the four contacts, the contact to read, and whether the drive change needs settling) and takes the measured voltage back, together with the time in milliseconds. This lets a scheduler interleave jacks on two ADCs and lets the host tests drive it from a model. It reports a \emph{mode} per jack: empty, identifying, tracking (a potentiometer), switch, rheostat, open (a plug with nothing conducting), or other.
}

\scaffold{
  \textbf{Paragraph 2, states.} Walk through \cref{fig:jack-monitor-states} along the main flow: rails at start-up, empty with a plug check every \qty{50}{\milli\second}, solve (rails re-measured first if older than \qty{30}{\second}), classification, then one of the following states. Then the two ways back: following a potentiometer returns to identification when a track-end check or the wiper range fails, switch, rheostat and open return to empty when the plug check fails. Name the confirm-plug state, which tells an empty jack from an open plug after a solve found no current. Do not describe every edge; the figure does.
}

\begin{figure}[htbp]
  \centering
  
  \titledcaption{Jack Monitor State Machine}{\scaffoldinline{Explain the three groups (plug detection, identification, following), the mode tag on each state, the drive symbols (red up, blue down), the two return corridors (re-identify above, unplugged below) and the output strip. Source: \code{docs/diagrams/jack-monitor-states.tex}. Consider a landscape page if the labels are too small at text width.}}
  \label{fig:jack-monitor-states}
\end{figure}

\scaffold{
  \textbf{Paragraph 3, constants.} Present \cref{tab:monitor-config} and point out that every interval and fraction was set or changed by an observation on the board; give two examples from the table with their reason (the \qty{25}{\percent} wiper limit from a pedal with resistance in its wiper lead, \cref{sec:pedal-types}; the \qty{25}{\percent} tolerance of the first track-end reading because solves of a pedal on an end stop were \qty{10}{\percent} off). The remaining reasons are in the appendix (\cref{tab:monitor-config-full}).
}

\begin{table}[htbp]
  \centering
  \titledcaption{Main Constants of the Jack Monitor}{\scaffoldinline{Explain that relative values refer to the total resistance of the network and that $\sigma$ is the noise of the checked quantity. Source: \code{MonitorConfig::new} in \code{topology/src/monitor.rs}.}}
  \label{tab:monitor-config}
  \begin{tabular}{@{}ll@{}}
    \toprule
    \textbf{Constant} & \textbf{Value} \\
    \midrule
    Plug check interval & \qty{50}{\milli\second} \\
    Track-end check interval (potentiometer) & \qty{25}{\milli\second} \\
    Ring check interval (switch, rheostat) & \qty{100}{\milli\second} \\
    Full solve of an open plug & every \qty{1}{\second} \\
    Rail refresh before a solve & after \qty{30}{\second} \\
    Readings averaged per rail & 8 \\
    Plug threshold & \num{0.75} of the rail span \\
    Largest wiper arm & \qty{25}{\percent} \\
    Largest arm at an end stop & \qty{2}{\percent} \\
    End-drop tolerance, first reading / later & \qty{25}{\percent} / \qty{3}{\percent} or $6\sigma$ \\
    Wiper range margin & $6\sigma$ + \qty{0.5}{\percent} of the span \\
    Closed switch & $\leq \qty{0.2}{\kilo\ohm}$ \\
    Readings between open and closed for a rheostat & 3 \\
    Assumed total before the first solve & \qty{100}{\kilo\ohm} \\
    \bottomrule
  \end{tabular}
\end{table}

\scaffold{
  \textbf{Paragraph 4, memory per plug.} What the monitor learns about a plug (that it is a rheostat, the total at its first end stop, the full scale) is forgotten when the plug comes out or turns out open, because a cable left in the jack may get the next pedal at its other end. The wiper of the last potentiometer is kept beyond that, for the next ambiguous end stop in the same jack. Mention the bug that motivated forgetting on an open plug: a stereo cable plugged into the jack first and into a potentiometer pedal afterwards connected tip and sleeve before the ring, was taken for a switch turning into a rheostat, and stayed one, until a ring check for stereo plugs was added.
}

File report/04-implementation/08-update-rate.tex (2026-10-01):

% !TEX root = ../main.tex

\section{Scheduling and Update Rate}
\label{sec:update-rate}

\scaffold{
  \textbf{Paragraph 1, the starting point.} The first firmware on the PCB solved every jack in turn and needed \qty{382}{\milli\second} per sweep, so a pedal was updated 2.6 times per second; the user-facing target set during development was at least \qty{50}{\hertz}. Break the time down, which is the diagnosis: every reading changed the ADC channel and therefore paid three conversion periods (\cref{sec:conversion}), \qty{9.5}{\milli\second} at the initial \qty{315}{\hertz} plus about \qty{0.7}{\milli\second} of SPI traffic; every jack took nine readings (three pairs of three contacts), the empty ones included; four jacks $\times$ nine readings $\times$ \qty{10.3}{\milli\second} plus twelve settling waits of \qty{1}{\milli\second} gives the \qty{382}{\milli\second}. At \qty{50}{\hertz}, \qty{20}{\milli\second} buy about two readings, so no full solve can fit: speed had to come from reading faster and reading less.
}

\openquestion{Update-rate target}{
  Is the \qty{50}{\hertz} target a requirement of the project or a value chosen during development? The proposal only asks for \enquote{real time without perceptible latency}.
}

\scaffold{
  \textbf{Paragraph 2, reading faster: the ADC operating point.} A characterization program measured, on a \qty{10.85}{\kilo\ohm} potentiometer pedal held still in jack~1, the time per reading and the noise at five filter rates (\cref{tab:adc-characterization}). Draw the three conclusions: the output resolution scales with the cube of the filter word, as sinc\textsuperscript{3} decimation predicts ($(13/3)^3 \approx 81$ between the fastest and the slowest word), which rules out the fastest rate; continuous conversion on one channel is 2.5 to 3 times noisier at the fast rates and was not worth a separate code path; calibration does not carry over between filter words (the ground reading moved between \qty{-2.9}{\milli\volt} and \qty{+1.75}{\milli\volt}), so the firmware uses one rate for rails, solves and following. \qty{819}{\hertz} reads 2.3 times faster than \qty{315}{\hertz} at a noise of \qty{0.39}{\milli\volt}, which is the $\sigma_V = \qty{0.5}{\milli\volt}$ of \cref{sec:tolerances}. Mains hum of 100 to \qty{140}{\micro\volt} was present at every rate but amounts to about 60 parts per million of travel.
}

\begin{table}[htbp]
  \centering
  \small
  \titledcaption{ADC Characterization}{\scaffoldinline{State the conditions: \qty{10.85}{\kilo\ohm} pedal in jack~1, tip as wiper, ring high, sleeve low, bipolar coding, calibrated at every rate; \enquote{reading} includes the channel switch; position noise refers to the full travel. One MIDI step is \num{7874} parts per million. Source: \code{docs/fast-tracking.md}, program \code{adc\_characterization}.}}
  \label{tab:adc-characterization}
  \setlength{\tabcolsep}{4pt}
  \begin{tabular}{@{}rrrrrr@{}}
    \toprule
    \textbf{Rate} & \textbf{Filter word} & \textbf{Reading} & \textbf{Noise} & \textbf{Output step} & \textbf{Position noise} \\
    \textbf{(\unit{\hertz})} & & \textbf{(\unit{\milli\second})} & \textbf{(\unit{\milli\volt})} & \textbf{(\unit{\milli\volt})} & \textbf{(ppm)} \\
    \midrule
    1365 & 3 & 2.89 & 1.93 & 3.88 & 887 \\
    1024 & 4 & 3.63 & 0.80 & 0.41 & 374 \\
    819 & 5 & 4.36 & 0.39 & 0.21 & 203 \\
    682 & 6 & 5.09 & 0.40 & 0.12 & 184 \\
    315 & 13 & 10.22 & 0.11 & 0.012 & 62 \\
    \bottomrule
  \end{tabular}
\end{table}

\scaffold{
  \textbf{Paragraph 3, a solver weakness exposed.} At \qty{819}{\hertz} the sweep dropped to \qty{156}{\milli\second}, but the position noise rose instead of staying put. Cause: the test pedal has its wiper on the tip, which is the arm shared by the first two pairs, and with a contact resistance of \qty{1.5}{\percent} the conditioning (\cref{eq:conditioning}) was 0.083, just above the old minimum of 0.05; the solver then split the track through a few millivolts across the wiper and amplified the noise about 25-fold. Raising the minimum to 0.5 forces the third pair for such pedals. Present \cref{tab:conditioning-fix} and state that the flaw had already cost accuracy at \qty{315}{\hertz}; going faster only made it visible.
}

\begin{table}[htbp]
  \centering
  \titledcaption{Effect of the Minimum Conditioning}{\scaffoldinline{State the condition: pedal held still at position 0.21; sweep of all four jacks with full solves. Source: \code{docs/fast-tracking.md}.}}
  \label{tab:conditioning-fix}
  \begin{tabularx}{\linewidth}{@{}Xrrr@{}}
    \toprule
    \textbf{Configuration} & \textbf{Position (ppm)} & \textbf{Total} & \textbf{Sweep} \\
    \midrule
    \qty{315}{\hertz}, minimum 0.05 & 2588 & \qty{0.91}{\percent} & \qty{382}{\milli\second} \\
    \qty{819}{\hertz}, minimum 0.05 & 4880 & \qty{1.75}{\percent} & \qty{156}{\milli\second} \\
    \qty{819}{\hertz}, minimum 0.5 & 274 & \qty{0.11}{\percent} & \qty{171}{\milli\second} \\
    \bottomrule
  \end{tabularx}
\end{table}

\scaffold{
  \textbf{Paragraph 4, reading less.} The second and larger step was to stop re-solving an identified pedal: the jack monitor of \cref{sec:jack-monitor} follows it with one reading per update, which is the reason the state machine exists. Empty jacks cost one plug check every \qty{50}{\milli\second} instead of nine readings per sweep.
}

\scaffold{
  \textbf{Paragraph 5, scheduling on two ADCs.} The scanner gives each ADC to whichever of its two jacks is most overdue, applies the drives of both chosen jacks in one shift-register write, starts a conversion on both chips and waits for both. A followed jack keeps its drives while the other jack on the same ADC is read, so alternating between them costs no settling of the contacts, only the ADC's own three periods. Settling waits (\cref{eq:settling}) are only inserted when a drive actually changes. Finally, the SPI clock was raised from \qty{1}{\mega\hertz} to \qty{4}{\mega\hertz} and the chip-select guard cut from \qty{50}{\micro\second} to \qty{10}{\micro\second}, which shortened a reading from \qty{4.36}{\milli\second} to \qty{4.02}{\milli\second} without additional noise or outliers; three conversion periods alone take \qty{3.66}{\milli\second}. The resulting rates are evaluated in \cref{sec:results-update-rate}.
}

\scaffold{
  \textbf{Paragraph 6, two development bugs.} One sentence each, as examples of observations on the board that changed the design: a rejected solve made the firmware forget the pedal's resistance and fall back to the longest settling time, so a moving pedal was tracked in one direction only; and the first tracking check allowed only \qty{3}{\percent} deviation, which dropped pedals replugged on an end stop. Both are now covered by host tests.
}

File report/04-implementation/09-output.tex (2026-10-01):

% !TEX root = ../main.tex

\section{Output Stage}
\label{sec:output}

\scaffold{
  \textbf{Paragraph 1, from position to value.} The monitor reports a raw position $p$ (\cref{eq:position}); the per-jack settings turn it into the sent value in three steps, presented as \cref{eq:value-range,eq:drive-curve}: the range $[p_\mathrm{min}, p_\mathrm{max}]$, which the web interface sets from the current pedal position with two buttons, is stretched to $[0, 1]$ and clamped; the result is inverted if the jack is set to invert; then the drive curve bends it. Mention why the range exists: the test pedal only reached 0.909 of its track at the end of its travel, a mechanical stop common to pedals \cite{mission2014expression}.
}

\begin{align}
  u &= \operatorname{clamp}\!\left(\frac{p - p_\mathrm{min}}{p_\mathrm{max} - p_\mathrm{min}},\, 0,\, 1\right),
  \qquad u' = \begin{cases} 1 - u & \text{if inverted} \\ u & \text{otherwise} \end{cases}
  \label{eq:value-range} \\
  y &= \frac{(1 + b)\,u'}{1 - b + 2b\,u'},
  \qquad b = 0.9\,d, \qquad d \in [-1, 1]
  \label{eq:drive-curve}
\end{align}

\scaffold{
  \textbf{Paragraph 2, the drive curve.} \Cref{eq:drive-curve} is Schlick's bias function \cite{schlick1994bias} with the parameter $a = (1 + b)/2$; show this substitution in one line. Explain its three properties that made it the choice for a single knob $d$: both ends of the travel stay in place, half travel maps to $(1 + b)/2$, so the knob reads as where the pedal's midpoint lands, and $-d$ gives the exact inverse of $+d$, so one knob can straighten a pedal with a logarithmic potentiometer as well as one with an antilogarithmic one \cite{mission2014expression}. It needs no power function, which matters on a microcontroller without a math library. Example from the development: a logarithmic potentiometer that reads \qty{10}{\percent} at half travel is linearized at $d \approx 0.89$.
}

\begin{figure}[htbp]
  \centering
  \placeholderfigure[0.6\linewidth]{
    \textbf{Content.} $y$ over $u'$ from \cref{eq:drive-curve} for $d = -1, -0.5, 0, 0.5, 1$, square plot, equal axes from 0 to 1.
    \textbf{Focus.} Mark the point at $u' = 0.5$ on each curve with its value $(1 + 0.9d)/2$, and draw the curves for $\pm d$ in the same color with solid and dashed line to show that they are mirror images.
    \textbf{How to obtain.} Add a function to \code{measurements/create\_plots.py} (matplotlib, same style as the other plots); the formula is \code{drive\_curve} in \code{src/web/interface.rs}.
  }
  \titledcaption{Drive Curve}{\scaffoldinline{Name the parameter values and the meaning of the marked midpoints and of the mirror pairs.}}
  \label{fig:drive-curve}
\end{figure}

\scaffold{
  \textbf{Paragraph 3, MIDI.} The device enumerates as a class-compliant USB MIDI device \cite{usbif1999midi}, so no driver is needed. Each jack sends its value as a 7-bit control change, by default on MIDI channel 1 with controller 11 (expression) for jacks 1 and 2 and controller 1 (modulation wheel) for jacks 3 and 4 \cite{midi2026controlchange}. A new value is sent only when the rounded value changes and the value has moved by more than 0.6 of a step since the last sent one, which suppresses toggling between two neighbouring values. If the host is not reading, a newer value replaces the one still waiting, so no queue builds up and a host that connects receives every pedal's current position.
}

\scaffold{
  \textbf{Paragraph 4, USB robustness.} Two problems surfaced on a macOS host, and both are worth a sentence because they explain design choices of the driver. The device froze completely on connection: macOS reads the manufacturer string during enumeration, which was longer than the 64-byte control buffer of the USB stack allows, and the resulting panic halted the core (Windows never asked for it). Fix: a \qty{256}{\byte} control buffer and a check of the strings at start-up. In addition, embassy-rp~0.10 reported a suspend from before the bus reset, which can stall enumeration \cite{embassy2026pr6693}, and its writes do not end when the host disconnects \cite{embassy2024issue3426}; the firmware wraps the driver to clear the stale suspend, pace event floods, and end transfers on disconnection, and runs USB in its own tasks so that it can never stall the measurement.
}

\scaffold{
  \textbf{Paragraph 5, LEDs.} Each jack has an RGB LED below it, colored from the jack's mode and sent value: off when empty, dim white for a plug that is not (yet) a known pedal, a pedal-specific color for \qty{1}{\second} once per plug-in (purple for an expression pedal, lime for a switch, yellow for a rheostat), then the value as a gradient from dark red through red, orange and yellow to white. One sentence on the purpose: the user sees without a computer that a pedal was recognized and what it sends.
}

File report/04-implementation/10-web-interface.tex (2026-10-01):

% !TEX root = ../main.tex

\section{Web Interface}
\label{sec:web-interface}

\scaffold{
  \textbf{Paragraph 1, access point and protocol.} The Pico~2~W opens a WPA2-protected WiFi access point and runs a DHCP server, a DNS server that answers every name with the device's address, and an HTTP server. Every path other than the interface itself is redirected to it, so phones and laptops open the interface as the sign-in page of the network (captive portal). The page holds a WebSocket connection: the device sends the status of every jack (mode, raw position, value, arm resistances, voltage and drive of every contact) about 30 times per second and the settings on every change; every settings message from a browser is applied and forwarded to all other open pages. Settings are not stored in flash yet, so they reset with every power cycle.
}

\scaffold{
  \textbf{Paragraph 2, the interface.} Describe \cref{fig:web-interface}: the jacks laid out as channel strips of a mixing desk, each with MIDI channel, controller, invert, range with minimum and maximum buttons, wiper setting and drive knob; and the side panel that draws the identified network of the selected jack with every pull switch, the measured contact voltages and a three-line explanation of what the jack is doing now, why, and what it waits for. State its role in the project in one sentence: it was the main debugging tool during development and made the classification visible during the demonstration.
}

\begin{figure}[htbp]
  \centering
  \placeholderfigure{
    \textbf{Content.} Screenshot of the web interface with four channel strips and the topology panel open on a jack that follows a potentiometer pedal.
    \textbf{Focus.} Crop to the strips and the panel; mark (numbered callouts) the range slider with its minimum and maximum buttons, the drive knob, the wiper setting, the drawn network with the identified wiper, and the explanation text.
    \textbf{How to obtain.} Either connect to the device (\code{npm run dev} in \code{web/}) with a pedal plugged in, or run \code{npm run dev:mock}, which simulates a potentiometer, a switch and a scripted plug-in sequence; take the screenshot in the browser at a window width of about 1600 pixels.
  }
  \titledcaption{Web Interface}{\scaffoldinline{Explain each numbered callout and which jack and pedal the screenshot shows.}}
  \label{fig:web-interface}
\end{figure}

\scaffold{
  \textbf{Paragraph 3, implementation in one sentence each.} The front end is a Vue single-page application built with Vite, Tailwind CSS and PrimeVue; the build step of the firmware compiles it into one gzipped HTML file that is embedded in the firmware image. A mock device that speaks the same protocol allows developing the interface without hardware. Do not go further into the web stack; it is not the subject of the report.
}

\openquestion{Android tablet drops}{
  WebSocket connections to one Android tablet dropped repeatedly (unacknowledged frames at the radio level) while other devices stayed connected; the captive portal was added in the hope of reducing the tablet's background scanning. Did it help? If the issue remains, mention it as a limitation in \cref{ch:discussion}.
}

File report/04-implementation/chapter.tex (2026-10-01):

% !TEX root = ../main.tex

\chapter{Implementation}
\label{ch:implementation}

\scaffold{
  \textbf{Overview paragraph} (writing guide, section 3.5). The reader knows the measurement principle from \cref{ch:measurement-principle}. Introduce the blocks of \cref{fig:block-diagram} with one sentence each, in signal-flow order: four jacks with four switched contacts each (tip, ring, sleeve, tip switch); per jack a shift register driving two analog switches that connect each contact to a shared pull-up or pull-down resistor; an RC filter per contact; two 24-bit ADCs, each reading two jacks; the Raspberry Pi Pico~2~W running the firmware; and the three outputs, USB MIDI to the host, an LED per jack and a WiFi access point serving the web interface. Then one sentence on the development method: the solver and the per-jack state machine live in a library without hardware dependencies that is tested on the host; the hardware drivers and the scheduling live in the firmware crate.
}

\begin{figure}[htbp]
  \centering
  \placeholderfigure{
    \textbf{Content.} Block diagram of the system, left to right: 4 jacks (J2--J5, contacts T, R, S, TS) $\rightarrow$ per jack: 74HC595 + 2$\times$TMUX1511 + shared \qty{1}{\kilo\ohm} pull-up to \qty{2.5}{\volt} and pull-down to GND $\rightarrow$ 16$\times$ RC filter (\qty{10}{\kilo\ohm}, \qty{10}{\nano\farad}) $\rightarrow$ 2$\times$ AD7718 (jacks 1--2 / 3--4, SPI0) $\rightarrow$ Raspberry Pi Pico~2~W (shift registers on SPI1) $\rightarrow$ USB MIDI, 4$\times$ WS2812B LED (GPIO6, level shifter), WiFi access point with web interface. Power block below: barrel jack $\rightarrow$ protection $\rightarrow$ LDOs \qty{5}{\volt}, \qty{3.3}{\volt}, \qty{2.5}{\volt} (from \qty{3.3}{\volt}); mark the \qty{2.5}{\volt} rail as both pull-up rail and ADC reference.

    \textbf{Focus.} Highlight (color) the analog measurement path of one jack; draw the other three jacks collapsed. Use the counts from \code{src/board.rs}.

    \textbf{How to obtain.} Draw in TikZ or a vector tool; style consistent with \code{docs/diagrams/}.
  }
  \titledcaption{System Block Diagram}{\scaffoldinline{One sentence per block group and the meaning of the highlighted path.}}
  \label{fig:block-diagram}
\end{figure}

\input{04-implementation/01-design-history}
\input{04-implementation/02-analog-front-end}
\input{04-implementation/03-conversion}
\input{04-implementation/04-microcontroller-power}
\input{04-implementation/05-pcb}
\input{04-implementation/06-firmware-architecture}
\input{04-implementation/07-jack-monitor}
\input{04-implementation/08-update-rate}
\input{04-implementation/09-output}
\input{04-implementation/10-web-interface}

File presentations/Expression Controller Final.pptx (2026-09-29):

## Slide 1

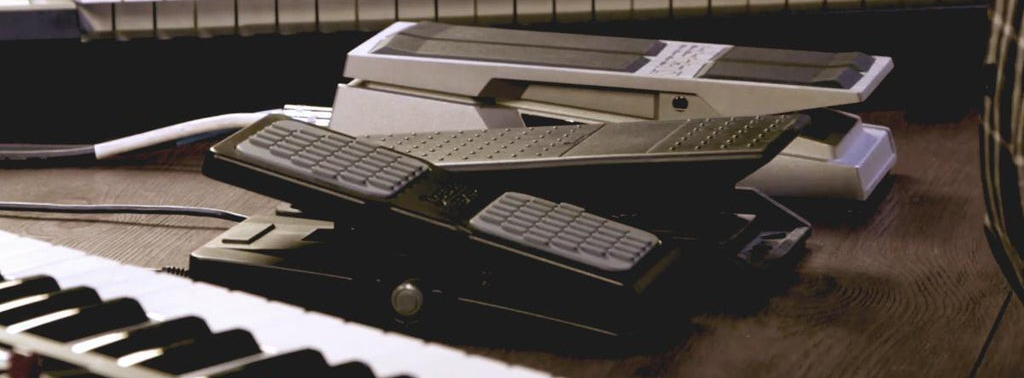
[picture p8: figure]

https://media.sweetwater.com/m/insync/2018/08/keyboardexpression.jpg

Adapter For Expression Pedals

Amon Benson | Sensor and Actuator Systems | Final Presentation | 28. September 2026

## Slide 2

- Recap

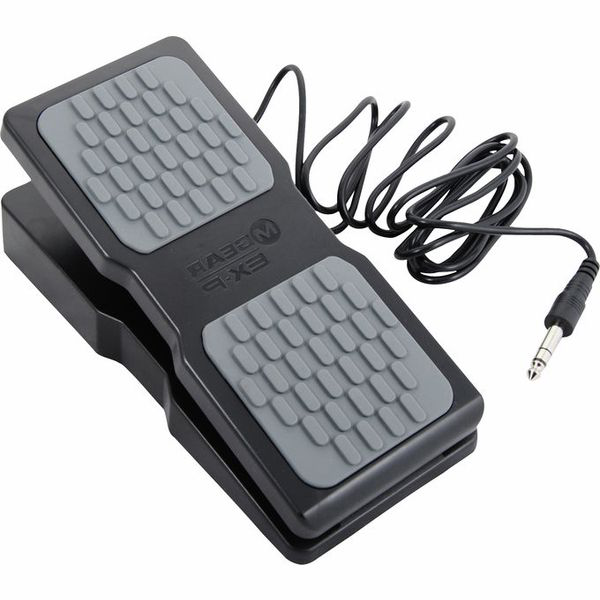
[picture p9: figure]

https://thumbs.static-thomann.de/thumb/padthumb600x600/pics/bdb/_19/195660/7223134_800.jpg

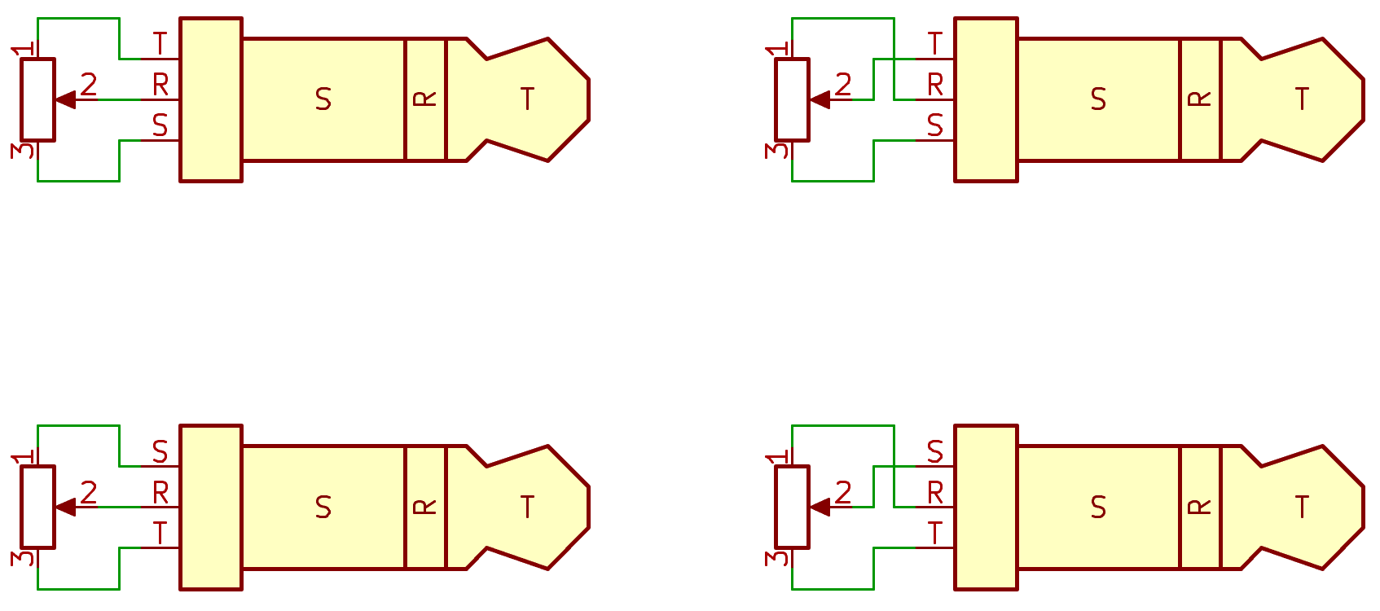
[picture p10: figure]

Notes: Expression Pedal = Potentiometer that can be controlled by a footpedal
Used mainly in live audio
Complexity comes from the fact that no standard pinout exists
Device to detect and support all possible pinouts and resistance values
→ The device needs to
detect the specific configuration of an attached pedal
continously read its position and send that to the host PC via the MIDI-USB protocol

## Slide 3

- Detection Process

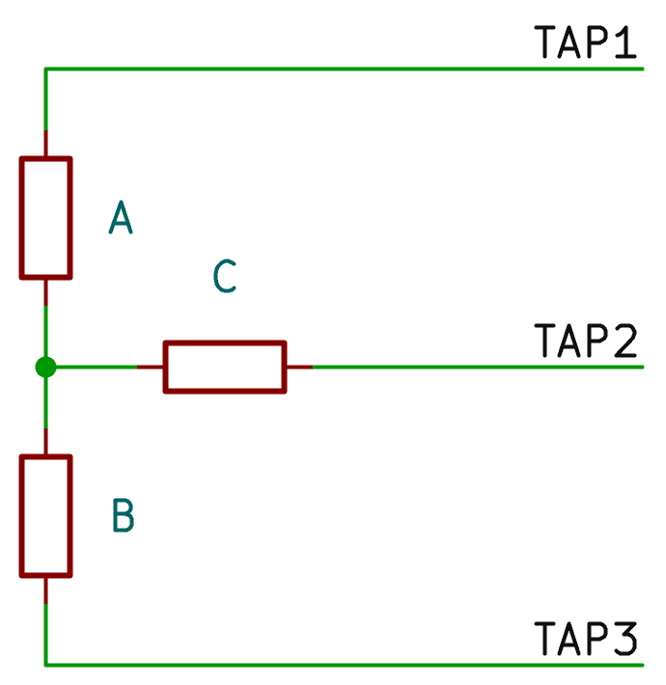
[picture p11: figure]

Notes: If this general model of 3 resistors is a potentiometer, one of the resistors must be 0 Ohm, while the others form the voltage divider
By measuring which resistor is 0 Ohm, we know which pin is the wiper

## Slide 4

- Detection Process

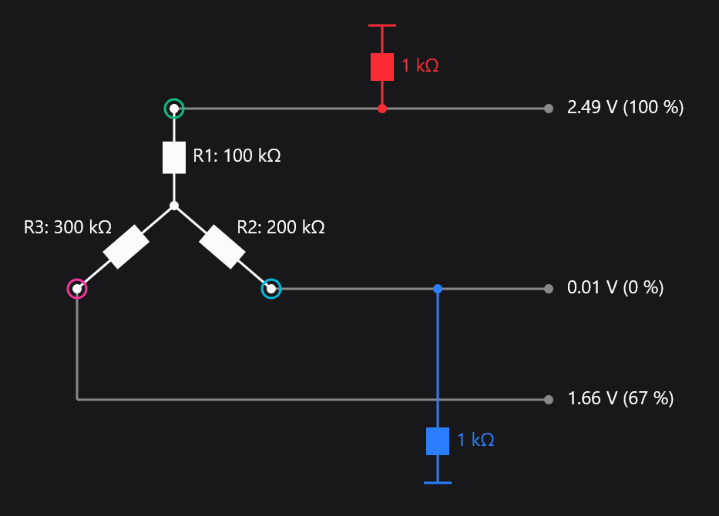
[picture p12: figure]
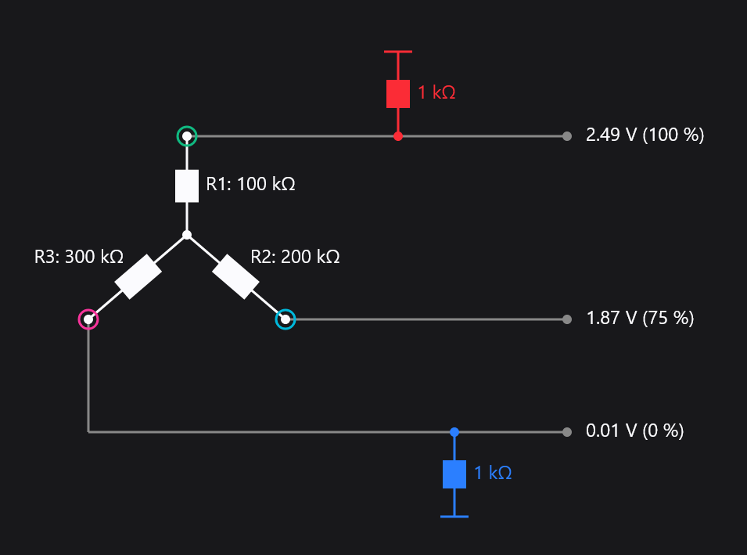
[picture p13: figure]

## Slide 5

- Detection Process

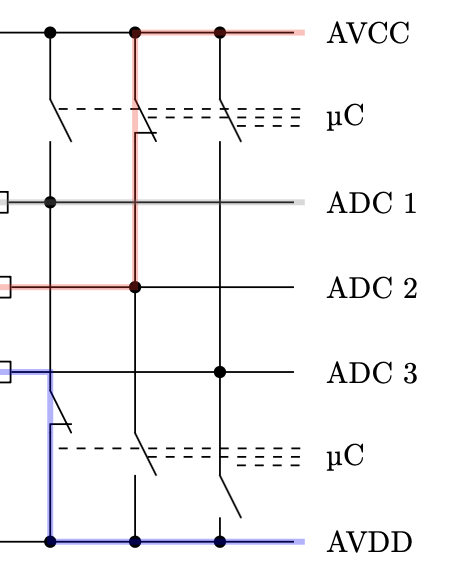
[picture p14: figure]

+3.3V

Tap 1

Tap 2

Tap 3

GND

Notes: Each Tap can be pulled High, Low, or left floating
Each Tap is connected to a separate ADC channel
Live Demo

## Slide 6

- Differences to Milestone 1 Schematics

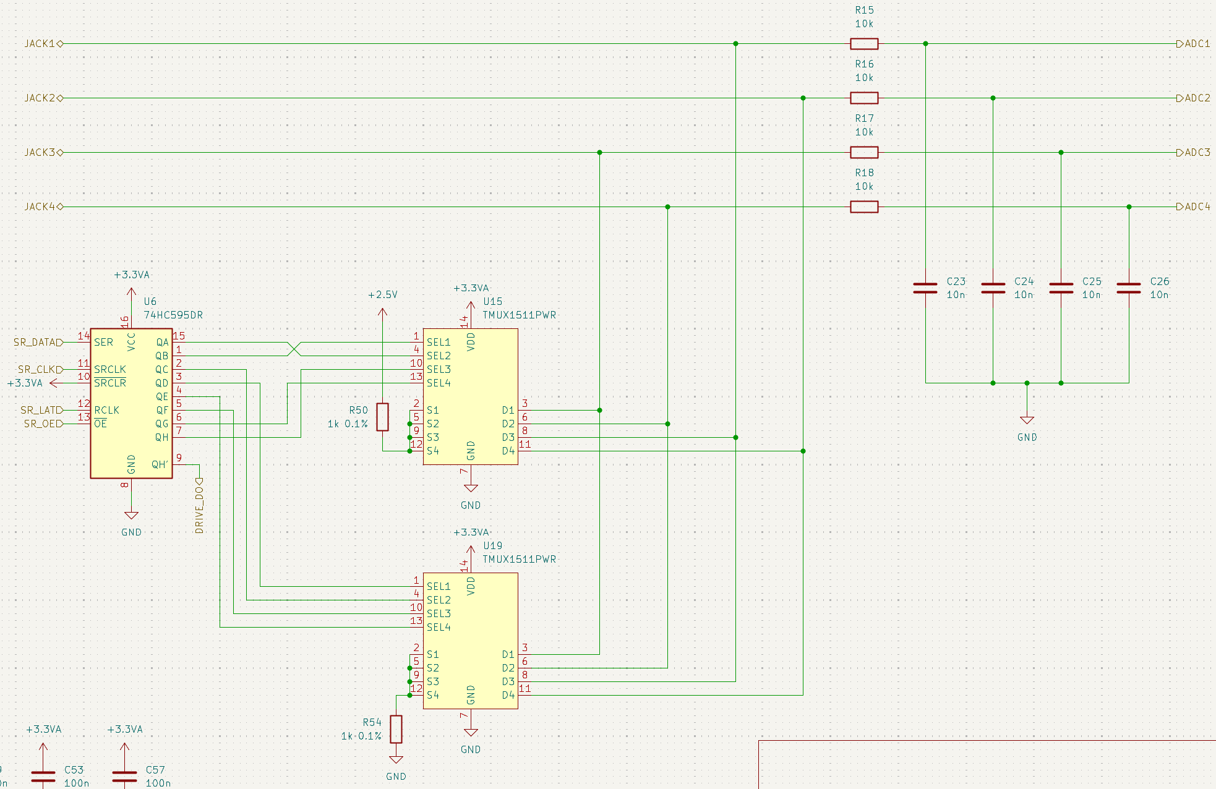
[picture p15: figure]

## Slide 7

- Sources

- [1] M. Frejek, "AVR-Transistortester," Embedded Projects Journal, no. 11, 2011. Online documentation: K.-H. Kübbeler. [Online]. Available: https://www.mikrocontroller.net/articles/AVR-Transistortester
- [2] Mission Engineering, "Understanding expression pedals." [Online]. Available: https://missionengineering.com/understanding-expression-pedals/
- [3] Analog Devices, AD7124-8: 8-Channel, Low Noise, Low Power, 24-Bit, Sigma-Delta ADC with PGA and Reference, Data Sheet, Rev. F, 2023. [Online]. Available: https://www.analog.com/media/en/technical-documentation/data-sheets/ad7124-8.pdf
- [4] Texas Instruments, ADS8688: 16-Bit, 8-Channel, Integrated Analog Front-End SAR ADC, Data Sheet. [Online]. Available: https://www.ti.com/product/ADS8688
- [5] Raspberry Pi Ltd., Raspberry Pi Pico 2 Datasheet (RP2350), 2024. [Online]. Available: https://pip-assets.raspberrypi.com/categories/1005-raspberry-pi-pico-2/documents/RP-008299-DS-2-pico-2-datasheet.pdf
- [6] Texas Instruments, SN74LVC126A: Quadruple Bus Buffer Gate With 3-State Outputs, Data Sheet. [Online]. Available: https://www.ti.com/lit/ds/symlink/sn74lvc126a.pdf
- [7] Analog Devices, ADP7142: 40 V, 200 mA, Low Noise, CMOS LDO Linear Regulator, Data Sheet, Rev. K. [Online]. Available: https://www.analog.com/media/en/technical-documentation/data-sheets/adp7142.pdf
- [8] P. Horowitz and W. Hill, The Art of Electronics, 3rd ed. Cambridge, U.K.: Cambridge University Press, 2015.
- [9] W. Kester, J. Bryant, and M. Byrne, "MT-031 Tutorial: Grounding Data Converters and Solving the Mystery of 'AGND' and 'DGND'," Analog Devices, Rev. A, 2008.

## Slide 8

- Testing and Evaluation Plan

- power supply quality
- SPI signal quality
- functional self-test
  - SPI device inquiry (ADC)
  - tristate buffer
- detection algorithm for known static networks
- accuracy and linearity
- end-to-end latency

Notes: Measure voltage and SNR on the supply rails
Measure signal integrity of the SPI bus
Self-tests: SPI device id inquiry, tristate buffer pullup/pulldown using ADC
Detection algorithm for known networks
Apply a resistor configuration and validate the detected topology
Also apply edge cases where R=0 Ohm (short or open circuit)
Sweep a precision resistor and compare the measured resistor ratio to the actual one
Measure end-to-end latency from input resistance change to the value arriving at the USB host

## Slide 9

- “AVR-Transistortester”

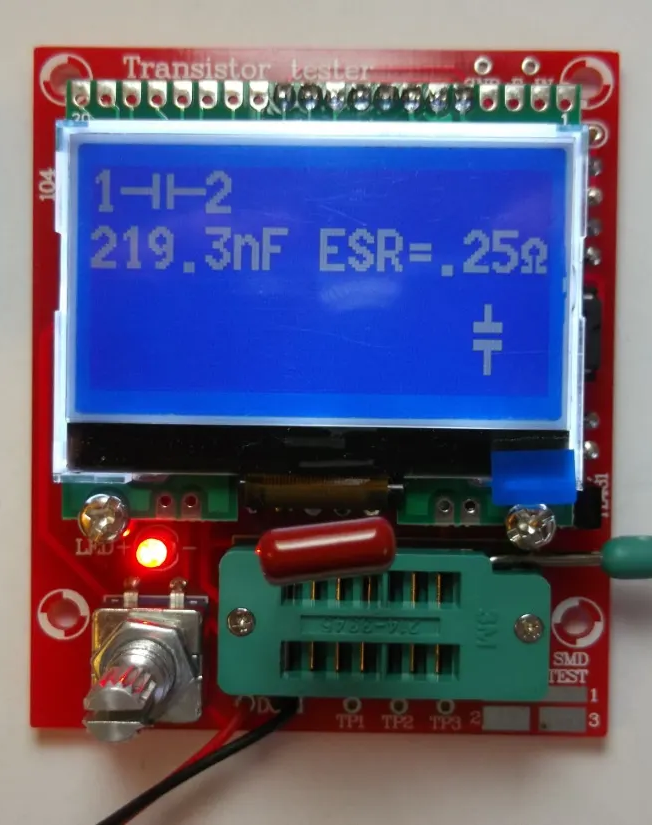
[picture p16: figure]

https://content.instructables.com/F4V/9O1Y/IFCDEPNY/F4V9O1YIFCDEPNY.jpg

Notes: Similar principle: “Transistor tester”

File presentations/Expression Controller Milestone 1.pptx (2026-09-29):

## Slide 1


https://media.sweetwater.com/m/insync/2018/08/keyboardexpression.jpg

Adapter For Expression Pedals

Amon Benson | Sensor and Actuator Systems | Milestone Meeting 1 | 28. September 2026

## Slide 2

- Motivation

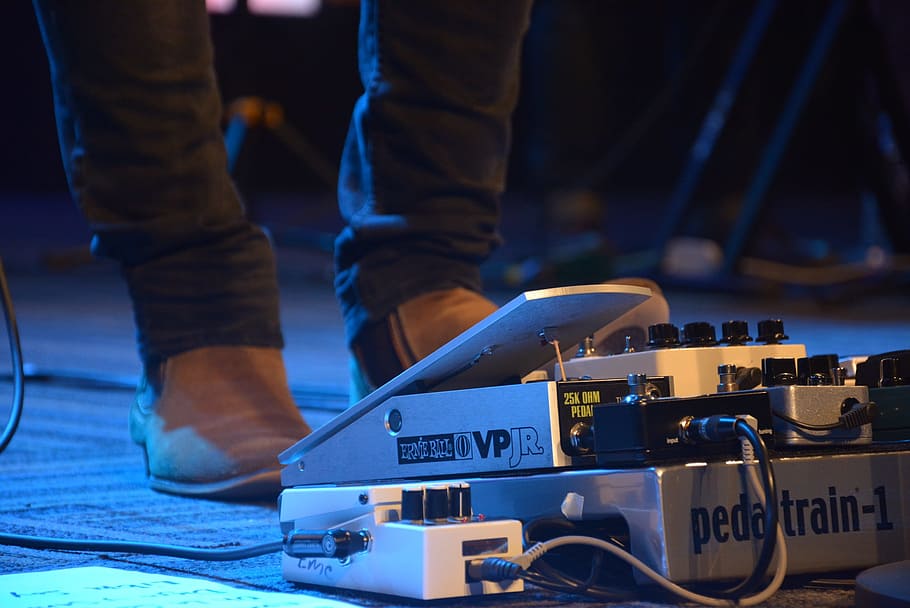
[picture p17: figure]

https://media.sweetwater.com/m/insync/2018/08/keyboardexpression.jpg

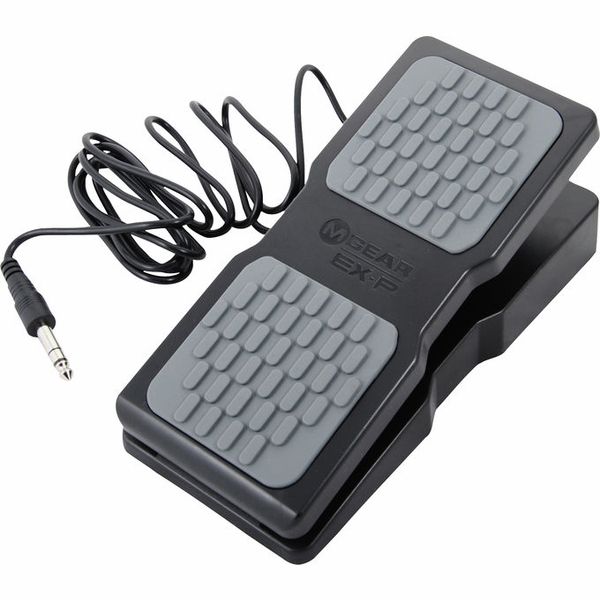
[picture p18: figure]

https://thumbs.static-thomann.de/thumb/padthumb600x600/pics/bdb/_19/195660/7223134_800.jpg

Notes: Expression (sometime Volume) Pedals are used during live performances to alter the sound of an audio signal
Example image: guitarist, can apply audio filter/modify frequence with both hands free
Compared to a switch pedal: Set a specific position and drive continuous values
Goal of this project: Create a hardware adapter to connect these pedals to a PC

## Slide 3

- Motivation


https://thumbs.static-thomann.de/thumb/padthumb600x600/pics/bdb/_19/195660/7223134_800.jpg


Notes: Simple passive device consisting of a single potentiometer
Complexity comes from the fact that no standard pinout exists
Nearly all pedals use a 6.35 mm TRS jack, two common pinouts
Some only use Tip-Ring plug
Sometimes pedals themselves have a switch to toggle between two common configuration
→ Build a device that can:
detect the specific configuration of an attached pedal
continously read its position and send that to the host PC via the MIDI-USB protocol

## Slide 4

- Detection Process

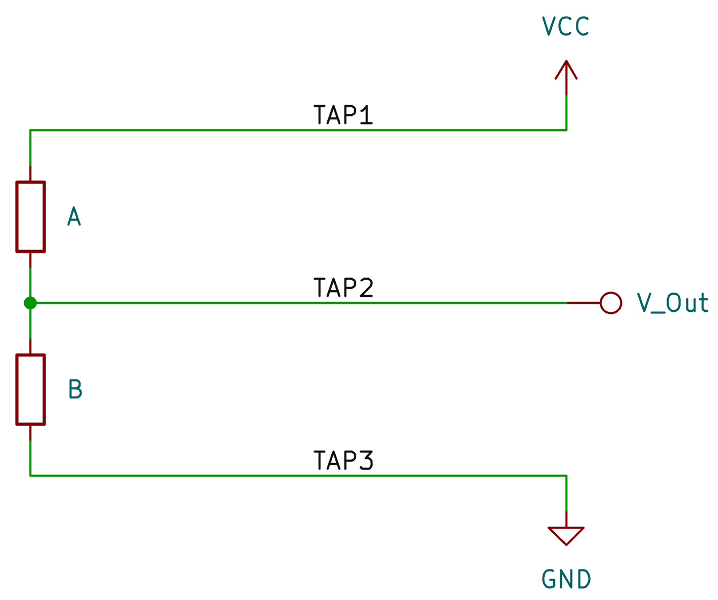
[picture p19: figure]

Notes: Model: Two resistors A and B
If we apply our positive and negative supply, we can read the voltage in the middle
→ Detect the resistor ratio and therefore the pedal position
Order of taps unknown: Test all possible permutations → Solve for the exact resistor values
To do this electrically

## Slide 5

- Detection Process

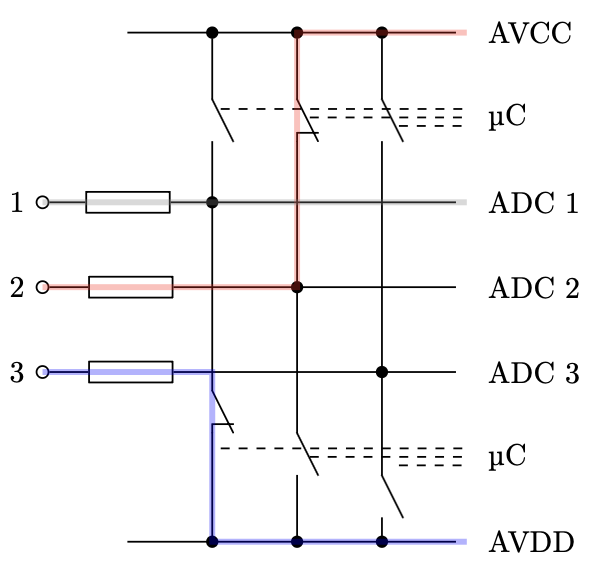
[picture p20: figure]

+3.3V

Tap 1

Tap 2

Tap 3

GND

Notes: Each Tap can be pulled High, Low, or left floating
Each Tap is connected to a separate ADC channel

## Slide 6

- Circuit Design – Analog Frontend

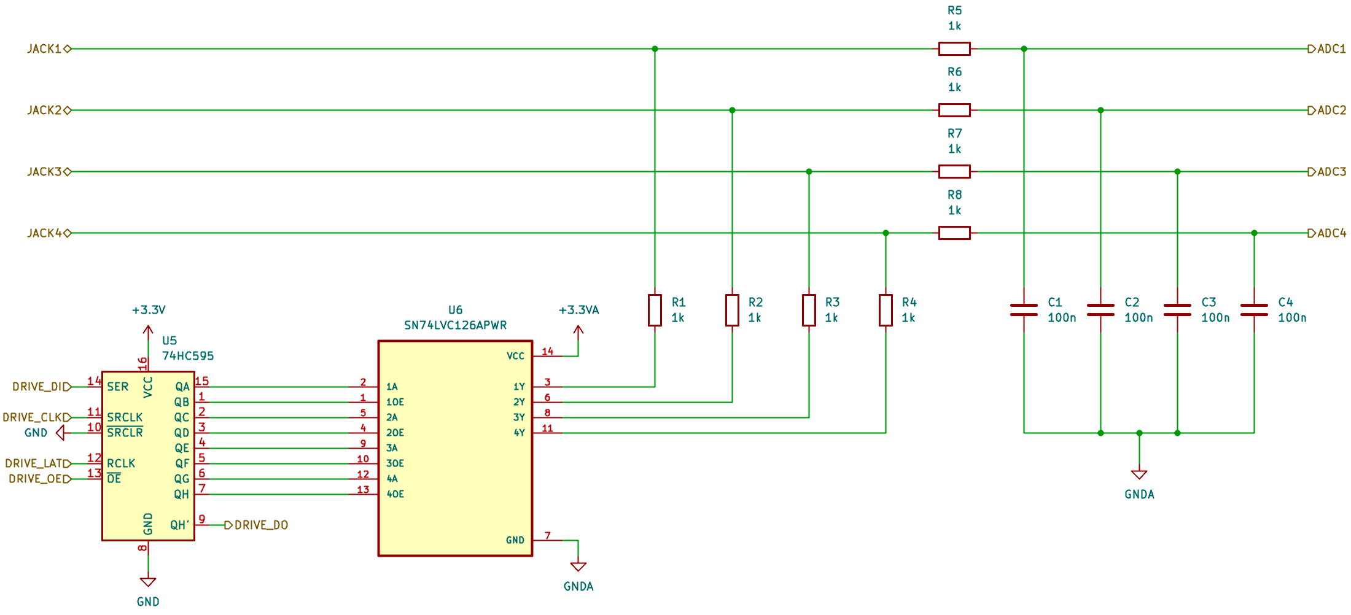
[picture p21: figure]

Tap 1

Tap 2

Tap 3

(unused)

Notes: Simple passive Anti-Aliasing-Filter: ~1.6 kHz
Pullup/down: Tristate Buffer IC (SN74)
Two control signals per output → 74HC shift register (Microcontroller GPIO expansion)

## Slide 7

- Circuit Design – ADC

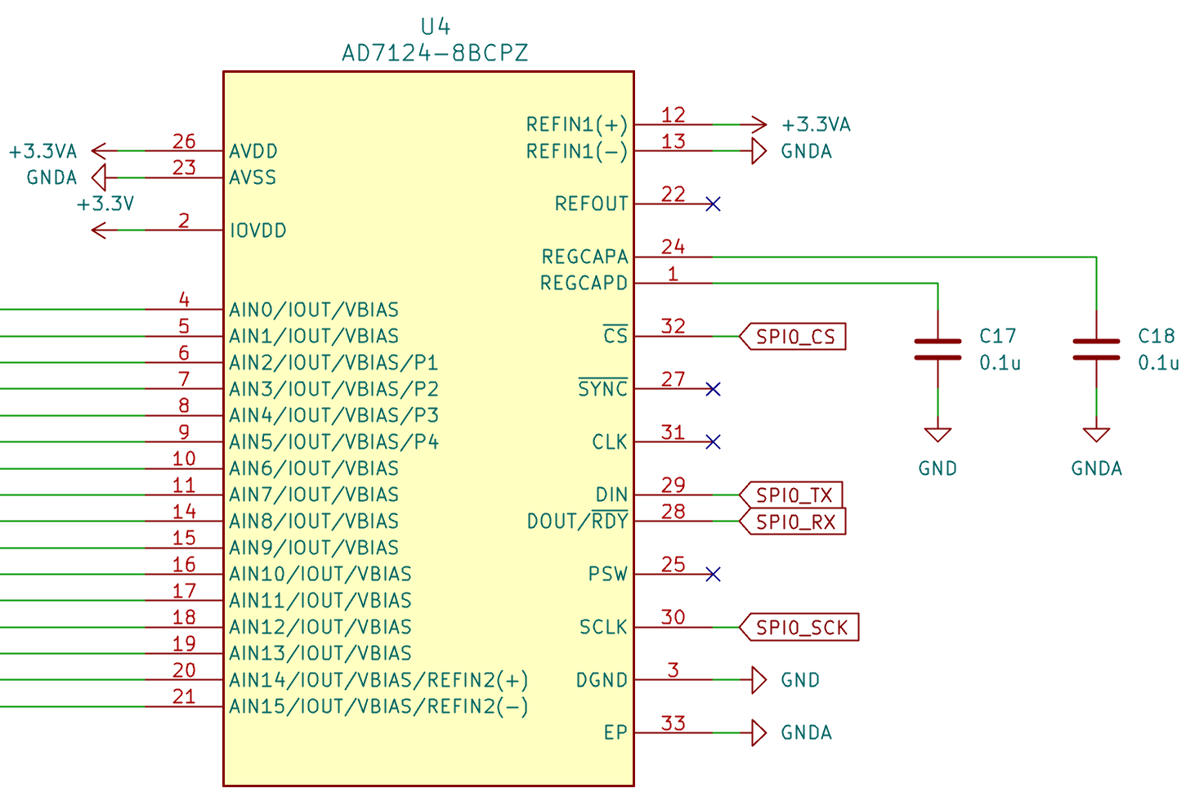
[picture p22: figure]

ADC 1.1
ADC 1.2
ADC 1.3
ADC 1.4
ADC 2.1
ADC 2.2
…

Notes: ADC: AD7124
Low speed (< 1kHz) → Sigma Delta
Works with 3.3V supply (Microcontroller logic level)
Interface via SPI
Minimal external circuitry required

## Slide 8

- Circuit Design – Microcontroller

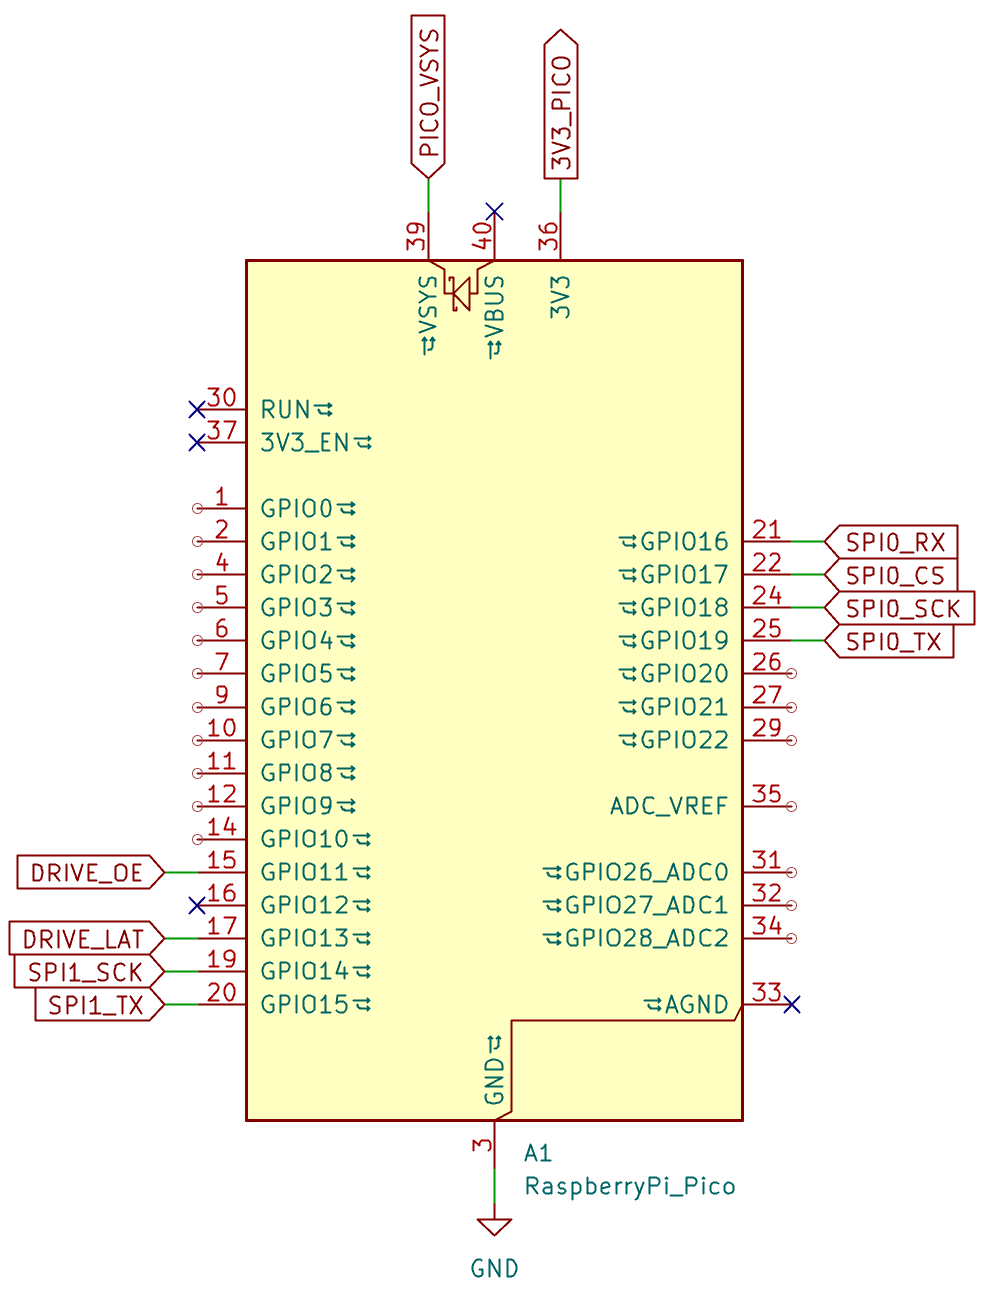
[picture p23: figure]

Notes: uC: Raspberry Pi Pico 2 Module
Bare RP2040 chip → USB, crystal, flash, etc. would all need to be added manually. Pico 2 Module is the official (well tested hardware)
STM32 (F4/G4/L4) → Faster CPU, but more external hardware required + proprietary USB stack

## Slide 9

- Circuit Design – Power Supply

Digital Supply (3.3V)

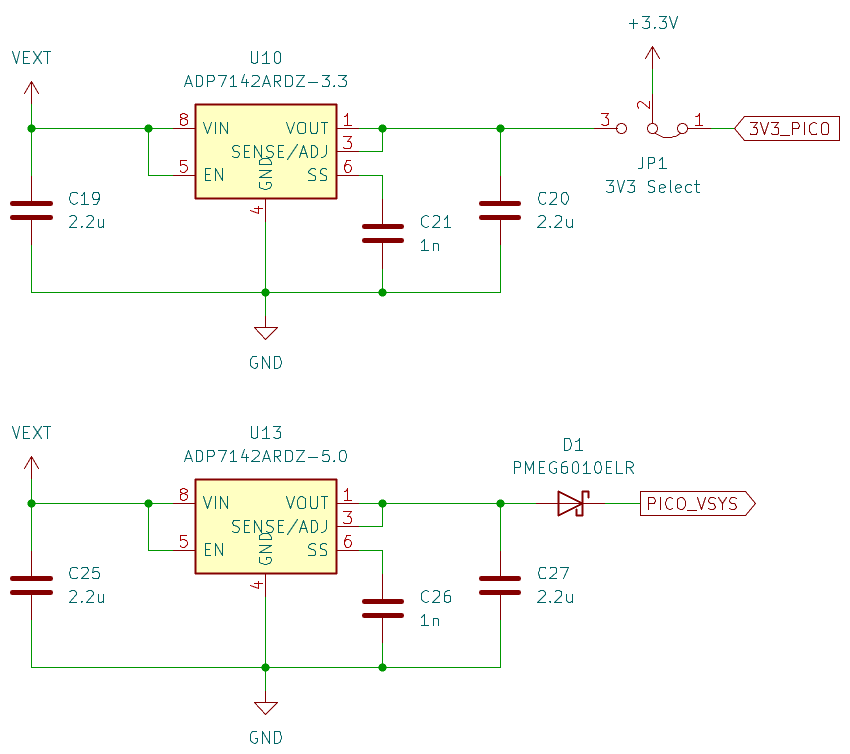
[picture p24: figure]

Analog Supply (3.3V)


Digital Supply (5V)

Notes: Digital supplies (5V and 3.3V)
3.3V can be toggled between this LDO and the Pico Module’s onboard voltage regulator
Analog supply
GND connected via single star point

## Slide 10

- Circuit Design – DC Input Protection


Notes: Reverse polarity protection circuit via an ideal diode
TVS protection diode for voltage spikes

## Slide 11

- Outlook

- Hardware
  - ~~circuit design~~
  - PCB layout and routing
  - manufacturing
- Firmware
  - ~~planning of the detection algorithm~~
  - implementation using the microcontroller toolchain
  - simulation of ADC measurements for offline (functional) testing

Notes: Hardware
Finish during the next week
Pick exact parts
Decoupling of the ADC
Hardware buttons and LEDs for indication purposes
Routing
Firmware
Start software implementation simultaneously next week
Offline simulation of the detection algorithm using ideal ADC measurements

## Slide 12

- Testing and Evaluation Plan

- power supply quality
- SPI signal quality
- functional self-test
  - SPI device inquiry (ADC)
  - tristate buffer
- detection algorithm for known static networks
- accuracy and linearity
- end-to-end latency

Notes: Measure voltage and SNR on the supply rails
Measure signal integrity of the SPI bus
Self-tests: SPI device id inquiry, tristate buffer pullup/pulldown using ADC
Detection algorithm for known networks
Apply a resistor configuration and validate the detected topology
Also apply edge cases where R=0 Ohm (short or open circuit)
Sweep a precision resistor and compare the measured resistor ratio to the actual one
Measure end-to-end latency from input resistance change to the value arriving at the USB host

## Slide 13

- Sources

- [1] M. Frejek, "AVR-Transistortester," Embedded Projects Journal, no. 11, 2011. Online documentation: K.-H. Kübbeler. [Online]. Available: https://www.mikrocontroller.net/articles/AVR-Transistortester
- [2] Mission Engineering, "Understanding expression pedals." [Online]. Available: https://missionengineering.com/understanding-expression-pedals/
- [3] Analog Devices, AD7124-8: 8-Channel, Low Noise, Low Power, 24-Bit, Sigma-Delta ADC with PGA and Reference, Data Sheet, Rev. F, 2023. [Online]. Available: https://www.analog.com/media/en/technical-documentation/data-sheets/ad7124-8.pdf
- [4] Texas Instruments, ADS8688: 16-Bit, 8-Channel, Integrated Analog Front-End SAR ADC, Data Sheet. [Online]. Available: https://www.ti.com/product/ADS8688
- [5] Raspberry Pi Ltd., Raspberry Pi Pico 2 Datasheet (RP2350), 2024. [Online]. Available: https://pip-assets.raspberrypi.com/categories/1005-raspberry-pi-pico-2/documents/RP-008299-DS-2-pico-2-datasheet.pdf
- [6] Texas Instruments, SN74LVC126A: Quadruple Bus Buffer Gate With 3-State Outputs, Data Sheet. [Online]. Available: https://www.ti.com/lit/ds/symlink/sn74lvc126a.pdf
- [7] Analog Devices, ADP7142: 40 V, 200 mA, Low Noise, CMOS LDO Linear Regulator, Data Sheet, Rev. K. [Online]. Available: https://www.analog.com/media/en/technical-documentation/data-sheets/adp7142.pdf
- [8] P. Horowitz and W. Hill, The Art of Electronics, 3rd ed. Cambridge, U.K.: Cambridge University Press, 2015.
- [9] W. Kester, J. Bryant, and M. Byrne, "MT-031 Tutorial: Grounding Data Converters and Solving the Mystery of 'AGND' and 'DGND'," Analog Devices, Rev. A, 2008.

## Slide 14

- “AVR-Transistortester”


https://content.instructables.com/F4V/9O1Y/IFCDEPNY/F4V9O1YIFCDEPNY.jpg

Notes: Similar principle: “Transistor tester”

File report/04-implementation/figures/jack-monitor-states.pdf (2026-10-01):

# Jack monitor: detection and following

One monitor per jack (topology/src/monitor.rs). T tip, R ring, S sleeve, TN tip switch; ▲ pulled up, ▼ pulled down through 1 kΩ; “read” is an ADC reading.

transition | re-identify | unplugged | position out
Plug detection | Identification | mode: identifying | Following

3-wire potentiometer
track ends driven: start ▼, end ▲; only the wiper is read

mode: tracking

2-wire: tip–sleeve element T▲ S▼, stereo R▼ too; only T read

power-up

### Measure rails

all taps ▲, then all ▼

### Empty

every 50 ms:
T▼ TN▲, read TN
no plug: TN rests on T
and the pulls halve the rail

mode: empty

no plug
TN ≤ ¾

### Confirm plug

T▼ TN▲, read TN
is a plug in at all?

TN ≤ ¾ rail:
unplugged

plug in

TN > ¾

rails
< 30 s?

### Refresh rails

all taps ▲, then all ▼

no

### Solve

pairs T▲R▼, T▲S▼, (R▲S▼)
read all three taps per pair → arm ratios and total

yes

rejected:
retry

classify
the star

solved

### Other

no known pedal,
no MIDI

mode: other

neither

solve again

no current anywhere: all arms open

### Read track ends

each end once, then
one every 25 ms
its pull drop must
stay the same

### Read wiper

position = where Vwiper lies between the two
ends’ voltages

wiper at the
star point | both read

25 ms passed

### Switch

closed (≤ 0.2 kΩ)
→ 1, open → 0
closed: pulls split the rail

mode: switch

### Rheostat

resistance from T’s pull drop, over a standard full scale

mode: rheostat

### Open

plug in, nothing conducts: T stays at the rail

mode: open

only tip and
sleeve conduct

end stop, total changed > 20 % since the pedal’s first (mono rheostat)

3 readings
in a row

between
closed, open

TN > ¾ rail: a plug, but nothing behind it; forget the pedal (it may be swapped at the cable’s end) lost track: an end’s drop vanished or shifted, or the wiper left the ends

tip or ring conducts, or 1 s passed: solve ring changed (every 100 ms): mono ring left the sleeve, stereo ring (▼) carries current re-identify: start a new solve

plug check (every 50 ms): TN ≤ ¾ rail, unplugged

Output

Every new position of a followed pedal becomes the jack’s expression value (JackSettings::value) and a MIDI control change. The LED is off while empty and dim white for an unknown plug; a recognised pedal shows its color for 1 s (purple expression, lime footswitch, yellow rheostat), then its value from dark red through orange and yellow to white.

range
stretch min..max

invert
if set

drive curve
bend −1..1

CC 0..127
with hysteresis

USB MIDI
and LED

position

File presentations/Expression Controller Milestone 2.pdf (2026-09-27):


# Adapter For Expression Pedals

## Amon Benson | Sensor and Actuator Systems | Milestone Meeting 2 | 27. September 2026

https://media.sweetwater.com/m/insync/2018/08/keyboardexpression.jpg

# Recap


Page 2 / 7 Amon Benson | Sensor and Actuator Systems | Adapter for Expression Pedals | Milestone Meeting 2 | 27. September 2026 https://thumbs.static-thomann.de/thumb/padthumb600x600/pics/bdb/_19/195660/7223134_800.jpg


Page 3 / 7 Amon Benson | Sensor and Actuator Systems | Adapter for Expression Pedals | Milestone Meeting 2 | 27. September 2026

# Detection Process


Page 4 / 7 Amon Benson | Sensor and Actuator Systems | Adapter for Expression Pedals | Milestone Meeting 2 | 27. September 2026

# Detection Process

Detection Process | +3.3V


Page 5 / 7 Amon Benson | Sensor and Actuator Systems | Adapter for Expression Pedals | Milestone Meeting 2 | 27. September 2026

# GND

## Tap 1

## Tap 2

## Tap 3

## Live Demo: https://amonbenson.github.io/topology-sim

Page 6 / 7 Amon Benson | Sensor and Actuator Systems | Adapter for Expression Pedals | Milestone Meeting 2 | 27. September 2026

## − Hardware

## − schematic design

## − build a working prototype (single channel)

## − PCB layout and routing

## − manufacturing

## − Firmware

## − simulation of ADC measurements for (functional) testing

## − implementation and refinement of the detection algorithm

## − implementation of the detection algorithm using the microcontroller toolchain

# Outlook

Page 7 / 7 Amon Benson | Sensor and Actuator Systems | Adapter for Expression Pedals | Milestone Meeting 2 | 27. September 2026
[1] M. Frejek, "AVR-Transistortester," Embedded Projects Journal, no. 11, 2011. Online documentation: K.-H. Kübbeler. [Online]. Available:

https://www.mikrocontroller.net/articles/AVR-Transistortester

[2] Mission Engineering, "Understanding expression pedals." [Online]. Available: https://missionengineering.com/understanding-expression-pedals/
[3] Analog Devices, AD7124-8: 8-Channel, Low Noise, Low Power, 24-Bit, Sigma-Delta ADC with PGA and Reference, Data Sheet, Rev. F, 2023. [Online]. Available:

https://www.analog.com/media/en/technical-documentation/data-sheets/ad7124-8.pdf

[4] Texas Instruments, ADS8688: 16-Bit, 8-Channel, Integrated Analog Front-End SAR ADC, Data Sheet. [Online]. Available: https://www.ti.com/product/ADS8688
[5] Raspberry Pi Ltd., Raspberry Pi Pico 2 Datasheet (RP2350), 2024. [Online]. Available: https://pip-assets.raspberrypi.com/categories/1005-raspberry-pi-pico-

2/documents/RP (https://pip-assets.raspberrypi.com/categories/1005-raspberry-pi-pico-2/documents/RP-008299-DS-2-pico-2-datasheet.pdf)- (https://pip-assets.raspberrypi.com/categories/1005-raspberry-pi-pico-2/documents/RP-008299-DS-2-pico-2-datasheet.pdf)008299 (https://pip-assets.raspberrypi.com/categories/1005-raspberry-pi-pico-2/documents/RP-008299-DS-2-pico-2-datasheet.pdf)- (https://pip-assets.raspberrypi.com/categories/1005-raspberry-pi-pico-2/documents/RP-008299-DS-2-pico-2-datasheet.pdf)DS (https://pip-assets.raspberrypi.com/categories/1005-raspberry-pi-pico-2/documents/RP-008299-DS-2-pico-2-datasheet.pdf)- (https://pip-assets.raspberrypi.com/categories/1005-raspberry-pi-pico-2/documents/RP-008299-DS-2-pico-2-datasheet.pdf)2 (https://pip-assets.raspberrypi.com/categories/1005-raspberry-pi-pico-2/documents/RP-008299-DS-2-pico-2-datasheet.pdf)- (https://pip-assets.raspberrypi.com/categories/1005-raspberry-pi-pico-2/documents/RP-008299-DS-2-pico-2-datasheet.pdf)pico (https://pip-assets.raspberrypi.com/categories/1005-raspberry-pi-pico-2/documents/RP-008299-DS-2-pico-2-datasheet.pdf)- (https://pip-assets.raspberrypi.com/categories/1005-raspberry-pi-pico-2/documents/RP-008299-DS-2-pico-2-datasheet.pdf)2 (https://pip-assets.raspberrypi.com/categories/1005-raspberry-pi-pico-2/documents/RP-008299-DS-2-pico-2-datasheet.pdf)- (https://pip-assets.raspberrypi.com/categories/1005-raspberry-pi-pico-2/documents/RP-008299-DS-2-pico-2-datasheet.pdf)datasheet.pdf (https://pip-assets.raspberrypi.com/categories/1005-raspberry-pi-pico-2/documents/RP-008299-DS-2-pico-2-datasheet.pdf)

[6] Texas Instruments, SN74LVC126A: Quadruple Bus Buffer Gate With 3-State Outputs, Data Sheet. [Online]. Available:

https://www.ti.com/lit/ds/symlink/sn74lvc126a.pdf

[7] Analog Devices, ADP7142: 40 V, 200 mA, Low Noise, CMOS LDO Linear Regulator, Data Sheet, Rev. K. [Online]. Available:

https://www.analog.com/media/en/technical-documentation/data-sheets/adp7142.pdf

[8] P. Horowitz and W. Hill, The Art of Electronics, 3rd ed. Cambridge, U.K.: Cambridge University Press, 2015.
[9] W. Kester, J. Bryant, and M. Byrne, "MT-031 Tutorial: Grounding Data Converters and Solving the Mystery of 'AGND' and 'DGND'," Analog Devices, Rev. A,

2008.

# Sources

Page 8 / 7 Amon Benson | Sensor and Actuator Systems | Adapter for Expression Pedals | Milestone Meeting 2 | 27. September 2026

## − power supply quality

## − SPI signal quality

## − functional self-test

## − SPI device inquiry (ADC)

## − tristate buffer

## − detection algorithm for known static networks

## − accuracy and linearity

## − end-to-end latency

# Testing and Evaluation Plan


Page 9 / 7 Amon Benson | Sensor and Actuator Systems | Adapter for Expression Pedals | Milestone Meeting 2 | 27. September 2026

# “AVR-Transistortester”

https://content.instructables.com/F4V/9O1Y/IFCDEPNY/F4V9O1YIFCDEPNY.jpg

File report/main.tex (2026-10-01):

% !TEX program = lualatex
% Report: Self-Configuring Interface for Expression Pedals. Build: latexmk (see latexmkrc).

\input{preamble}

\begin{document}

\pagenumbering{roman}
\include{00-front-matter/chapter}

\tableofcontents
\listofloqs % scaffold only: remove with the last open question

\cleardoublepage
\pagenumbering{arabic}
\include{01-introduction/chapter}
\include{02-related-work/chapter}
\include{03-measurement-principle/chapter}
\include{04-implementation/chapter}
\include{05-results/chapter}
\include{06-discussion/chapter}
\include{07-conclusion/chapter}

\appendix
\include{08-appendix/chapter}

\printbibliography[heading=bibintoc]
\listoffigures
\listoftables

\end{document}

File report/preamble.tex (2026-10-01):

% !TEX root = main.tex
% !TEX program = lualatex
%
% Preamble of the report. Build with latexmk (see latexmkrc), which runs LuaLaTeX and Biber.

% The standard class, not KOMA-Script: the caption package of TeX Live 2025 does not recognize
% the current scrreprt and then attaches no number to \label (every figure reference broke).
\documentclass[a4paper, 11pt, oneside]{report}

% --- Page layout and headings --------------------------------------------------------------
\usepackage[a4paper, top=30mm, bottom=30mm, inner=30mm, outer=25mm]{geometry}
\usepackage[skip=0.5\baselineskip plus 2pt]{parskip}
\usepackage{titlesec}
\titleformat{\chapter}[hang]{\normalfont\huge\bfseries}{\thechapter\quad}{0pt}{}
\titlespacing*{\chapter}{0pt}{0pt}{30pt}
\usepackage[nottoc]{tocbibind} % lists of figures and tables in the table of contents
\usepackage{tocbasic}           % list of open questions

% --- Language and fonts --------------------------------------------------------------------
\usepackage{polyglossia}
\setdefaultlanguage[variant=american]{english}
\setotherlanguage{german} % statutory declaration

\usepackage{amsmath}
\usepackage{fontspec}
\usepackage{unicode-math}
\setmathfont{Latin Modern Math}
\usepackage{microtype}
\usepackage{csquotes}

% --- Floats, tables, units -----------------------------------------------------------------
\usepackage{graphicx}
\usepackage[labelfont=bf, font=small]{caption}
\usepackage{subcaption}
\usepackage{booktabs}
\usepackage{tabularx}
\usepackage{longtable}
\usepackage{pdfpages}
\usepackage{siunitx}
\sisetup{
  range-units = single,
  range-phrase = { to },
  per-mode = symbol,
}
\usepackage{xcolor}
\usepackage[most]{tcolorbox}

% --- Page style ----------------------------------------------------------------------------
\usepackage{fancyhdr}
\setlength{\headheight}{15pt}
\pagestyle{fancy}
\fancyhf{}
\fancyhead[L]{\nouppercase{\leftmark}}
\fancyhead[R]{\thepage}
\renewcommand{\headrulewidth}{0.4pt}
\renewcommand{\chaptermark}[1]{\markboth{\thechapter\quad #1}{}}

% --- Bibliography --------------------------------------------------------------------------
\usepackage[backend=biber, style=ieee, sorting=nyt]{biblatex}
\addbibresource{bibliography.bib}

% --- Cross references (load last) ----------------------------------------------------------
\usepackage[hidelinks]{hyperref}
\usepackage[capitalise, noabbrev]{cleveref}

% --- Semantic commands for content ---------------------------------------------------------
% Caption in the form "Title - description", with the title alone in the list of figures.
\newcommand\titledcaption[2]{\caption[#1]{\textbf{#1}~-- #2}}

% Vectors and matrices.
\NewDocumentCommand\vecsym{m}{\symbf{#1}}
\NewDocumentCommand\matsym{m}{\symbf{#1}}

% Identifiers from the firmware (types, constants, binaries) and named signals or nets.
\NewDocumentCommand\code{m}{\texttt{#1}}
\NewDocumentCommand\net{m}{\texttt{#1}}

% --- Scaffold commands (remove together with every use once the report is written) ----------
\definecolor{scaffold}{HTML}{1F4E79}
\definecolor{openquestion}{HTML}{9C1C1C}

% What a paragraph has to convey.
\newtcolorbox{scaffoldbox}{
  breakable, enhanced,
  colback=scaffold!5, colframe=scaffold!70, boxrule=0.4pt, arc=1pt,
  left=4pt, right=4pt, top=3pt, bottom=3pt,
  fontupper=\small\sffamily\color{scaffold!90!black},
}
\NewDocumentCommand\scaffold{+m}{\begin{scaffoldbox}#1\end{scaffoldbox}}

% Scaffold text inside captions, table cells and other places where a box does not fit.
\NewDocumentCommand\scaffoldinline{m}{{\sffamily\color{scaffold}[#1]}}

% A figure that does not exist yet: what it shows and how to obtain it.
\NewDocumentCommand\placeholderfigure{O{0.9\linewidth} +m}{%
  \begin{tcolorbox}[
    width=#1, enhanced, center,
    colback=black!4, colframe=black!45, boxrule=0.4pt, sharp corners,
    borderline={0.4pt}{2pt}{black!45, dashed},
    title={Figure to be created}, coltitle=black, colbacktitle=black!12,
    fonttitle=\small\sffamily\bfseries, fontupper=\small\sffamily,
  ]#2\end{tcolorbox}%
}

% Information or a reason that is missing and has to come from the author. The first argument
% is the short form for the list of open questions.
\newcounter{openquestion}
\crefname{openquestion}{open question}{open questions}
\DeclareNewTOC[listname={List of Open Questions}]{loq}
\NewDocumentCommand\openquestion{m +m}{%
  \refstepcounter{openquestion}%
  \addcontentsline{loq}{figure}{\protect\numberline{\theopenquestion}#1}%
  \begin{tcolorbox}[
    breakable, enhanced,
    colback=openquestion!5, colframe=openquestion!75, boxrule=0.6pt, arc=1pt,
    left=4pt, right=4pt, top=3pt, bottom=3pt,
    title={Open question \theopenquestion: #1}, fonttitle=\small\sffamily\bfseries,
    fontupper=\small\sffamily,
  ]#2\end{tcolorbox}%
}

% --- Document data -------------------------------------------------------------------------
\input{00-front-matter/metadata}

\hypersetup{
  pdftitle={\reporttitle},
  pdfauthor={\authorname},
}

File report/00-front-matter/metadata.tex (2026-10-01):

% !TEX root = ../main.tex
% Document data, used by the title page, the declaration and the PDF metadata. Plain \newcommand,
% so that hyperref can expand the title and author into the PDF metadata.

\newcommand\documenttype{Report}
\newcommand\reporttitle{Self-Configuring Interface for Expression Pedals}
\newcommand\coursename{Control of Smart Sensor Systems}
\newcommand\submissiondate{\scaffoldinline{submission date}}
\newcommand\authorname{Amon Benson}
\newcommand\matriculationnumber{400233}
\newcommand\supervisor{\scaffoldinline{professor}}
\newcommand\assistant{\scaffoldinline{assistant}}

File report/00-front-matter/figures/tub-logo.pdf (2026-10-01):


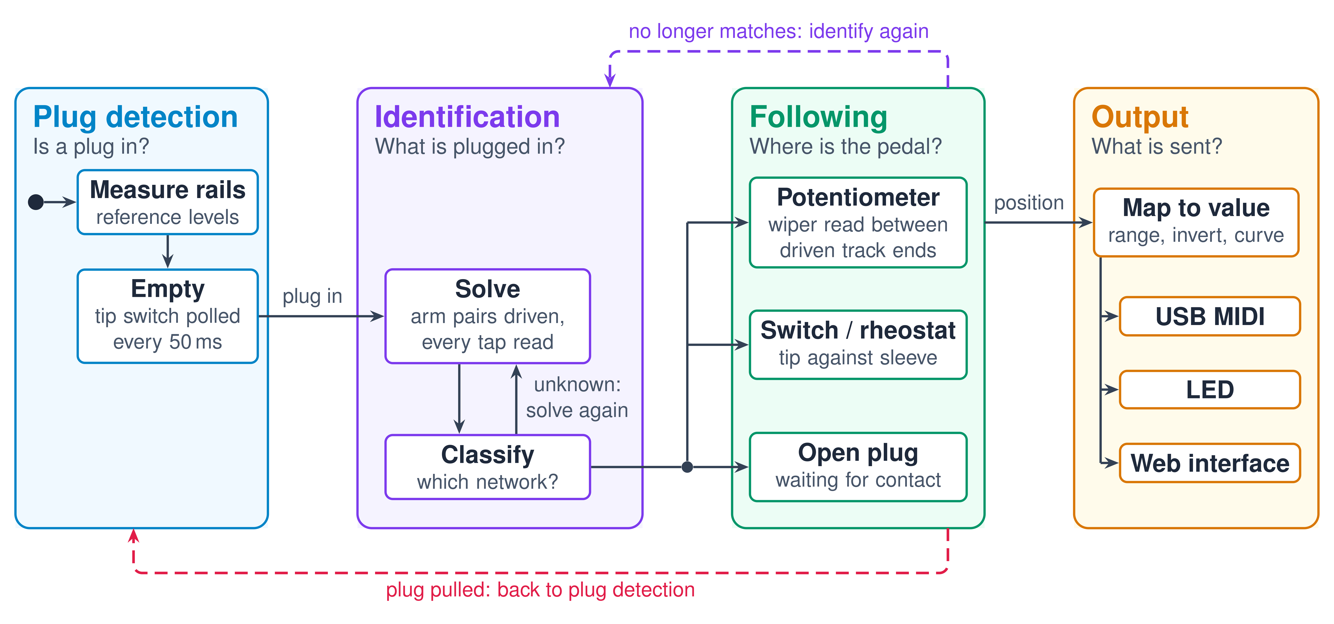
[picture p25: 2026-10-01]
docs/diagrams/jack-monitor-overview.png

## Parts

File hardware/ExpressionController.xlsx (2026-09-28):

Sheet: BOM
Reference | Qty | Value | Footprint | Datasheet | Part Source | Mouser No | Notes
A1 | 1 | RaspberryPi_Pico | Pico_2W_with_Header:Pico_2W_with_Header | https://datasheets.raspberrypi.com/pico/pico-datasheet.pdf | Uni
C1 | 1 | 47u | Capacitor_SMD:CP_Elec_6.3x5.8 |  | Mouser | 667-EEH-ZC1E470P
C2,C10,C17 | 3 | 10u | Capacitor_SMD:C_0805_2012Metric |  | Uni |  | im Uni-Sortiment?
C3,C5 | 2 | 4.7u | Capacitor_SMD:C_0805_2012Metric |  | Uni
C4,C6,C8 | 3 | 2.2u | Capacitor_SMD:C_0805_2012Metric |  | Uni
C9,C11,C13,C16,C18,C20,C39,C40,C41,C42,C47,C48,C49,C50,C51,C52,C53,C54,C55,C56,C57,C58,C59,C60 | 24 | 100n | Capacitor_SMD:C_0805_2012Metric |  | Uni
C14,C15,C21,C22 | 4 | 18p | Capacitor_SMD:C_0805_2012Metric |  | Uni
C23,C24,C25,C26,C27,C28,C29,C30,C31,C32,C33,C34,C35,C36,C37,C38 | 16 | 10n | Capacitor_SMD:C_0805_2012Metric |  | Uni
D1 | 1 | SMBJ15CA | Diode_SMD:D_SMB |  | Mouser | 947-SMBJ15CA
D2 | 1 | BZX84C15-7-F | Package_TO_SOT_SMD:SOT-23 | https://diotec.com/tl_files/diotec/files/pdf/datasheets/bzx84c2v4.pdf | Mouser | 621-BZX84C15-F
D3 | 1 | PMEG6010ELR | Diode_SMD:Nexperia_CFP3_SOD-123W | https://assets.nexperia.com/documents/data-sheet/PMEG6010ELR.pdf | Mouser | 771-PMEG6010ELRX
D4,D5,D6,D7 | 4 | WS2812B | LED_SMD:LED_WS2812B_PLCC4_5.0x5.0mm_P3.2mm | https://cdn-shop.adafruit.com/datasheets/WS2812B.pdf | Mouser | 485-1655 | ! 10er Pack
F1 | 1 | MF-MSMF050-2 | Fuse:Fuse_1812_4532Metric |  | Mouser | 652-MF-MSMF050-2
J1 | 1 | BarrelJack | Connector_BarrelJack:BarrelJack_CUI_PJ-102AH_Horizontal |  | Mouser | 490-PJ-102AH
J2,J3,J4,J5 | 4 | AudioJack | Jack_6.35mm_Neutrik_NMJ6HFD4_Horizontal:Jack_6.35mm_Neutrik_NMJ6HFD4_Horizontal |  | Mouser | 568-NMJ6HFD2-AU
Q1 | 1 | DMP3099L-7 | Package_TO_SOT_SMD:SOT-23 | https://www.diodes.com/assets/Datasheets/DMP3099L.pdf | Mouser | 621-DMP3099L-7
R1 | 1 | 100k | Resistor_SMD:R_0805_2012Metric |  | Uni
R3,R4,R5,R6,R7,R8,R9,R10,R46,R47,R48,R49 | 12 | 47 | Resistor_SMD:R_0805_2012Metric |  | Uni
R15,R16,R17,R18,R23,R24,R25,R26,R31,R32,R33,R34,R39,R40,R41,R42,R58 | 17 | 10k | Resistor_SMD:R_0805_2012Metric |  | Uni
R43 | 1 | 220 | Resistor_SMD:R_0805_2012Metric |  | Uni
R44,R45 | 2 | 0 | Resistor_SMD:R_0805_2012Metric |  | Uni
R50,R51,R52,R53,R54,R55,R56,R57 | 8 | 1k 0.1% | Resistor_SMD:R_0805_2012Metric |  | Mouser | ERA-6AEB102V
TP1,TP2,TP3,TP4,TP5,TP6,TP7,TP8,TP9,TP10,TP11,TP12,TP13,TP14,TP15 | 15 | TestPoint | TestPoint:TestPoint_THTPad_D1.5mm_Drill0.7mm |  | -
U1 | 1 | ADP7142AUJZ-3.3 | Package_TO_SOT_SMD:TSOT-23-5 | https://www.analog.com/media/en/technical-documentation/data-sheets/ADP7142.pdf | Mouser | 584-ADP7142AUJZ3.3R7
U2 | 1 | ADP7142AUJZ-5.0 | Package_TO_SOT_SMD:TSOT-23-5 | https://www.analog.com/media/en/technical-documentation/data-sheets/ADP7142.pdf | Mouser | 584-ADP7142WAUJZ-50R
U3 | 1 | ADP7142AUJZ-2.5 | Package_TO_SOT_SMD:TSOT-23-5 | https://www.analog.com/media/en/technical-documentation/data-sheets/ADP7142.pdf | Mouser | 584-ADP7142AUJZ2.5R7
U4,U5 | 2 | AD7718BRZ | Package_SO:SOIC-28W_7.5x17.9mm_P1.27mm | https://www.analog.com/media/en/technical-documentation/data-sheets/AD7708_7718.pdf | Mouser | 584-AD7718BRZ
U6,U8,U10,U12 | 4 | 74HC595DR | Package_SO:SOIC-16_3.9x9.9mm_P1.27mm | http://www.ti.com/lit/ds/symlink/sn74hc595.pdf | Mouser | 595-SN74HC595DR
U14 | 1 | 74AHCT1G125 | Package_TO_SOT_SMD:SOT-353_SC-70-5 | http://www.ti.com/lit/sg/scyt129e/scyt129e.pdf | Mouser | 595-74AHCT1G125DCKRG
U15,U16,U17,U18,U19,U20,U21,U22 | 8 | TMUX1511PWR | Package_SO:TSSOP-14_4.4x5mm_P0.65mm |  | Mouser | 595-TMUX1511PWR
Y1,Y2 | 2 | 32.768kHz | MS1V-T1K:MS1V-T1K | https://cdn-reichelt.de/documents/datenblatt/B400/MS1V-7.pdf | Mouser | 428-200120-ML02

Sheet: Power Consumption
Measured Power Consumption
Rail | 2.5V | 3.3V | 5V
Peak | 0.8 | 0.4 | 250 | (all LEDs max brightness)
Average | 0.8 | 0.4 | 30
Measured with one chip each (4 channels), 8 LEDs

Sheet: Testpoint Colors
Ref | Net
TP3 | SCLK
TP2 | LAT
TP1 | OE
TP4 | DATA
TP5 | RX
TP6 | CS1
TP7 | CLK
TP8 | TX
TP9 | CS2
TP10 | RDY1
TP11 | RDY2
TP12 | 5V
TP13 | 3.3V
TP14 | 2.5V
TP15 | VEXT
 | GND

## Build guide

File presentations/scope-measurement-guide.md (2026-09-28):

# Oscilloscope Measurement Guide

Practical companion to the measurement program in
[final-presentation-scaffold.md](final-presentation-scaffold.md). Written for someone who has
never used an oscilloscope. It covers the five measurements that need one: M4 (recognition time),
M5 (latency), M7 (rails and SPI), and M8 (tap settling).

Every board location in here was taken from `hardware/ExpressionController.kicad_pcb` and the
exported netlist, so the pin names and positions are checked rather than remembered. Coordinates
are KiCad page coordinates: use them to find a part in the PCB editor (View > Show > Cursor
coordinates), not with a ruler on the board. **Physically, find everything by its silkscreen
label** (`TP7`, `J2`, `C4`), which is what those labels are for.

---

# Part 1: Read this before you touch anything

## The one mistake that matters on this board

**A jack's sleeve contact is not ground.** On every other piece of audio equipment you have ever
seen, the sleeve of a 6.35 mm jack is ground, and clipping a scope's ground lead to it is the
normal thing to do. On this board it is wrong.

Verified from the netlist: jack 1's sleeve pad (`J2.S`) is on net
`/AnalogFrontend/AnalogQuadChannel1/JACK3`, which runs to a 10 kOhm resistor into the ADC and to
two analog switches. It is a measured, switched, high-impedance node. So are tip, ring and the tip
switch. None of the four is ground.

If you clip the scope's ground lead to a jack contact, you connect that measurement node to mains
earth through the scope. Nothing will catch fire (it goes through 1 kOhm pull resistors), but every
reading from that jack becomes meaningless and you may confuse yourself for an hour. Use a real
ground pad from the table in Part 4.

## Why the ground lead is dangerous in general

The black clip on a scope probe is not a neutral "reference". On a bench scope it is wired to the
chassis and through the mains cable to earth. Clipping it to a node that is not at ground potential
shorts that node to earth through a thin wire. On this board the nodes that would actually hurt are
`VEXT` (the barrel jack input, 12 V class), `+5V`, `+3.3VA` and `+2.5V`.

Rule: **the black clip only ever goes on GND.** If you want to look at the voltage between two
non-ground points, that is a differential measurement, and you do it with two channels both
referenced to GND plus the scope's `Ch1 - Ch2` math function. Never by moving a ground clip.

A second consequence: if you use two probes at once, both black clips are connected to each other
inside the scope. Putting one on GND and the other on a different node quietly shorts them.

## Search terms for this section

`oscilloscope probe ground lead safety`, `oscilloscope ground loop`, `differential measurement with
single-ended probes`, `floating an oscilloscope` (and why you should not).

---

# Part 2: Your scope and your probe

## The probe

A passive probe has four parts worth knowing:

- **Tip.** Usually a sprung hook that clips onto a wire or a component leg. Most probes have a
  removable hook revealing a rigid needle underneath, which is what you want for poking into a
  through-hole pad.
- **Ground lead.** A short black wire ending in a crocodile clip, coming off the probe body near
  the tip.
- **Attenuation switch.** A small slider marked `1X` and `10X`. In 10X the probe divides the
  signal by ten before it reaches the scope. This is the normal position: it raises the probe's
  input resistance to about 10 MOhm, lowers its capacitance, and preserves the probe's full
  bandwidth. **In 1X you get ten times more sensitivity but far less bandwidth (often about 6 MHz)
  and much heavier loading.** For the millivolt-level rail measurements that trade is worth it; for
  everything else use 10X.
- **Compensation trimmer.** A small screw, usually in the probe body or the BNC end, adjusted with
  a plastic tool. See Part 3.

**The scope must be told which attenuation you selected.** Many scopes do not detect it. If the
probe is on 10X and the scope thinks 1X, every voltage you read will be ten times too small, and
you will not notice because the waveform shape is right. Find the channel menu, `Probe` or
`Attenuation`, and set it to match. **Check this every time you move the slider.** More
measurements have been ruined by this than by anything else.

## The controls you will actually use

- **Vertical (Volts/div).** How many volts one vertical grid square represents. Turn it down until
  the waveform fills most of the screen; a waveform occupying one square wastes most of the scope's
  resolution.
- **Vertical position / offset.** Moves the trace up and down. Also find the "ground marker", a
  small arrow at the screen edge showing where 0 V is for that channel.
- **Coupling: DC or AC.** DC shows the real voltage. AC subtracts the average, so a 2.5 V rail with
  1 mV of ripple becomes a 1 mV wiggle around zero that you can then magnify. Use DC unless you are
  hunting for ripple.
- **Horizontal (Time/div).** How much time one horizontal square represents. Total screen width is
  usually 10 or 12 squares.
- **Trigger.** The scope needs to be told when to start drawing, or the trace smears. You set a
  **source** (which channel), a **type** (usually `Edge`), a **slope** (rising or falling) and a
  **level** (a voltage). The scope draws one screenful each time that channel crosses that voltage
  in that direction.
- **Trigger mode: Auto, Normal, Single.**
  - `Auto` draws something even when the trigger condition never happens. Good for finding a signal
    you are not sure is there. Misleading once you care about timing.
  - `Normal` draws only on a real trigger. Use this for repeating signals.
  - `Single` arms once, captures one screenful on the next trigger, then freezes. **This is the mode
    for one-off events like plugging in a pedal.** It is the single most useful mode in this guide.
- **Acquisition mode.** Usually `Normal`, `Average`, `Peak Detect`, `High Resolution`.
  - `Average` overlays many captures and averages them, reducing random noise. Only valid for a
    repeating, trigger-stable signal, and it will hide single-shot glitches.
  - `High Resolution` (or `Hi-Res`) oversamples and gives you extra effective bits at slow
    timebases. Excellent for rail ripple.
  - `Peak Detect` catches narrow spikes between samples. Use it to check you are not missing a
    glitch, not for measuring amplitudes.
- **Bandwidth limit.** A per-channel option, usually `20 MHz`. It throws away everything above
  20 MHz. On a slow board like this one, high-frequency content is almost all pickup and scope
  noise, so switching it on makes low-level measurements much cleaner and more honest.
- **Measure / Cursors.** `Measure` gives automatic readouts (peak-to-peak, RMS, rise time,
  frequency). `Cursors` gives two draggable lines with a readout of the difference between them,
  which is how you time anything the automatic measurements do not cover.

## Search terms

`oscilloscope volts per division`, `oscilloscope trigger modes auto normal single`,
`oscilloscope acquisition modes averaging high resolution`, `oscilloscope bandwidth limit`,
`10x probe attenuation`.

---

# Part 3: The setup ritual, once per session

Do this every time you sit down. It takes two minutes and it prevents most bad data.

1. **Power the scope on and let it warm up** while you do the rest.
2. **Set probe attenuation.** Slider to `10X`, and set the channel's probe setting to `10X`.
3. **Compensate the probe.** Every scope has a small metal tab or loop on the front marked
   something like `Probe Comp`, `Cal`, or `1 kHz`. It puts out a square wave.
   - Clip the probe tip to it and the ground lead to the adjacent ground tab.
   - Set the timebase and vertical so you see two or three square-wave cycles filling the screen.
   - Look at the top edge of the square wave. It should be **flat**. If it slopes up into a corner
     (overshoot) or sags (undershoot), turn the compensation trimmer with a plastic tool until it
     is flat.
   - **Why this matters:** an uncompensated probe distorts exactly the thing you are measuring in
     M8 (an RC settling curve) and M7 (edge shapes). An uncompensated probe can make a clean edge
     look like it overshoots by 20%.
   - Repeat for the second probe. Probes are not interchangeable once compensated; keep each one on
     its channel.
4. **Measure your own noise floor.** Clip the probe tip directly onto its own ground clip so the
   probe is measuring zero volts. Set AC coupling, bandwidth limit on, and the most sensitive
   Volts/div you plan to use. Read the peak-to-peak and RMS. **Write this number down.** Any ripple
   measurement you later make that is close to it is not a measurement of the board, it is a
   measurement of your scope. Saying so in the presentation is a strength, not a weakness.
5. **Check the board's ground is where you think.** With the board powered, DC coupling, put the
   probe tip on your chosen ground pad and the clip on another ground pad. It should read
   approximately 0 V. If it does not, one of them is not ground.

## Search terms

`oscilloscope probe compensation`, `probe compensation square wave overshoot`,
`oscilloscope noise floor measurement`.

---

# Part 4: Where to connect on this board

## Test points: your main probe targets

The board has 15 test points. All of them are **through-hole pads, 1.5 mm pad with a 0.7 mm hole**,
placed on the bottom side. Because they are drilled through, you can reach them from either side,
but the silkscreen labels are on the bottom, so **you will be reading the labels with the board
upside down.**

| Test point | Signal | What it is | KiCad position |
|---|---|---|---|
| TP1 | `SR_OE` | Shift register output enable (all four) | 128.78, 139.19 |
| TP2 | `SR_LAT` | Shift register latch / RCLK (all four) | 135.38, 140.46 |
| TP3 | `SR_CLK` | Shift register clock (all four) | 141.99, 141.73 |
| TP4 | `SR_DATA` | Shift register serial data into the first chip | 122.17, 137.92 |
| TP5 | `SPI0_RX` | ADC data out to the MCU (MISO), both ADCs | 166.62, 134.37 |
| TP6 | `SPI0_NCS1` | Chip select, ADC 1 (jacks 1 and 2) | 164.08, 134.37 |
| TP7 | `SPI0_CLK` | ADC SPI clock, both ADCs | 159.00, 134.37 |
| TP8 | `SPI0_TX` | MCU data out to the ADCs (MOSI), both | 156.46, 134.37 |
| TP9 | `SPI0_NCS2` | Chip select, ADC 2 (jacks 3 and 4) | 153.92, 134.37 |
| TP10 | `SPI0_NRDY1` | Conversion-ready from ADC 1 | 151.38, 134.37 |
| TP11 | `SPI0_NRDY2` | Conversion-ready from ADC 2 | 146.30, 134.37 |
| TP12 | `+5V_RAW` | 5 V regulator output, before jumper JP3 | 199.39, 147.32 |
| TP13 | `+3.3VA_RAW` | 3.3 V regulator output, before jumper JP1 | 178.82, 140.97 |
| TP14 | `+2.5V_RAW` | 2.5 V regulator output, before jumper JP2 | 171.20, 140.72 |
| TP15 | `VEXT` | Protected barrel jack input | 186.44, 140.21 |

TP5 to TP11 sit in one straight row on a 2.54 mm (0.1 inch) grid with two positions skipped, so
they look and behave like a header row. **Soldering a 0.1 inch pin header strip into TP5-TP11 is
worth the five minutes**: probe hooks grip header pins securely, and a probe tip that slips out of
a hole mid-capture while your other hand is holding a pedal is genuinely annoying.

The four rail test points sit on the regulator side of solder jumpers JP1, JP2 and JP3, so they read
each regulator's own output.

## Ground pads for the black clip

The board has 102 GND pads, but only 8 are through-hole and therefore easy to clip onto. Seven are
on the Pico's header, and one is the barrel jack's ground pin.

| Ground point | What it is | KiCad position |
|---|---|---|
| `A1` pin 3 | Pico header GND | 123.44, 145.29 |
| `A1` pin 8 | Pico header GND | 136.14, 145.29 |
| `A1` pin 13 | Pico header GND | 148.84, 145.29 |
| `A1` pin 18 | Pico header GND | 161.54, 145.29 |
| `A1` pin 23 | Pico header GND | 161.54, 127.51 |
| `A1` pin 28 | Pico header GND | 148.84, 127.51 |
| `A1` pin 38 | Pico header GND | 123.44, 127.51 |
| `J1` pin 1 | Barrel jack ground, biggest pad on the board | 189.83, 136.40 |

**Which one to use: always the nearest.** The ground lead is a wire loop, and a big loop picks up
interference and rings. Nearest ground for each probe point, computed from the layout:

| Probing | Nearest through-hole GND | Distance |
|---|---|---|
| TP1 `SR_OE` | `A1` pin 3 | 8.1 mm |
| TP2 `SR_LAT` | `A1` pin 8 | 4.9 mm |
| TP3 `SR_CLK` | `A1` pin 8 | 6.8 mm |
| TP4 `SR_DATA` | `A1` pin 3 | 7.5 mm |
| TP5 `SPI0_RX` | `A1` pin 23 | 8.5 mm |
| TP6 `NCS1` | `A1` pin 23 | 7.3 mm |
| TP7 `SPI0_CLK` | `A1` pin 23 | 7.3 mm |
| TP8 `SPI0_TX` | `A1` pin 23 | 8.5 mm |
| TP9 `NCS2` | `A1` pin 28 | 8.5 mm |
| TP10 `NRDY1` | `A1` pin 28 | 7.3 mm |
| TP11 `NRDY2` | `A1` pin 28 | 7.3 mm |

For the rails, do not use a through-hole ground at all: probe straight across the regulator's own
output capacitor, which is the shortest loop available (see M7a).

## Jack contacts, for the settling and timing measurements

Jack 1 is `J2`. Its pins are **through-hole, 3.4 mm pads with 1.5 mm holes** on the front side, so
they are the easiest things on the whole board to probe. Tip, ring and sleeve sit in a straight
vertical line 6.35 mm apart.

| Pad | Contact | KiCad position | Nearest GND |
|---|---|---|---|
| `J2.T` | Tip | 136.40, 177.22 | `U6` pin 8, 3.7 mm (SMD) |
| `J2.R` | Ring | 136.40, 183.56 | `U6` pin 8, 6.8 mm (SMD) |
| `J2.S` | Sleeve | 136.40, 189.91 | `C39` pad 2, 7.5 mm (SMD) |
| `J2.TN` | Tip switch | 120.17, 177.22 | `R54` pad 2, 5.3 mm (SMD) |

`J2.RN` and `J2.SN` are unconnected pads; ignore them.

There is no through-hole ground near the jacks. The nearest grounds are SMD pads, which are awkward
to clip to. Two options:

- **Best:** solder a 30 to 50 mm wire from any GND pad near the jack (`U6` pin 8 is the ground pin
  of jack 1's shift register) into a loop you can clip onto, and leave it there for the session.
- **Acceptable:** use `A1` pin 8 on the Pico header, about 32 mm away. The loop is larger, but the
  signals you are watching at the jack are slow (millisecond-scale RC curves and drive pattern
  changes), so a bit of extra loop inductance costs you nothing. **Do not** use this long ground for
  the SPI edge measurement, where it would matter.

## Search terms

`oscilloscope probe ground lead length inductance`, `probe ground spring`, `PCB test point probing`.

---

# M7a: Power supply rails

**What you are measuring.** How much the four rails wobble, at idle and while the LEDs and WiFi are
active. This closes item 1 of the milestone-1 evaluation plan.

**Name of this measurement:** *power supply ripple and noise measurement*. In power supply
datasheets the specified quantity is often called **PARD** (periodic and random deviation), and the
LDO's own spec sheet calls the frequency-dependent version **PSRR** (power supply rejection ratio)
and its self-noise **output noise spectral density**. Searching any of those gets you good material.

## Connections

One probe. For each rail in turn, probe **across the regulator's own output capacitor**, which means
tip on the capacitor's rail pad and the ground clip (or better, a bare wire) on the capacitor's
ground pad, 1.9 mm away. This is the smallest possible loop and therefore the honest measurement.

| Rail | Capacitor | Rail pad | GND pad | Equivalent test point |
|---|---|---|---|---|
| `VEXT` (input) | `C5` | pad 1 at 191.77, 144.97 | pad 2 at 191.77, 143.07 | TP15 |
| `+3.3VA` | `C4` | pad 1 at 178.82, 143.07 | pad 2 at 178.82, 144.97 | TP13 |
| `+2.5V` | `C8` | pad 1 at 171.20, 143.07 | pad 2 at 171.20, 144.97 | TP14 |
| `+5V` | `C6` | pad 1 at 199.39, 144.97 | pad 2 at 199.39, 143.07 | TP12 |

These are 0805 parts, so the pads are about 1 x 1.45 mm. If that is too fiddly, fall back to the
test point with the nearest ground (TP13 to `U3` pin 2 is only 2.9 mm; TP14 to `C8` pad 2 is 4.2 mm;
TP12 to `C6` pad 2 is 4.3 mm; TP15 to `U1` pin 2 is 3.2 mm) and say in the presentation that you
measured at the test point rather than across the cap.

Also worth measuring, because they are what the ADC actually sees: `C13` (138.94, 160.85 rail /
138.94, 162.75 GND) and `C20` (181.61, 160.85 / 181.61, 162.75) are the 2.5 V decoupling caps right
next to the two ADCs, after the jumper.

## Scope settings

Written for the Rigol MSO5104 with a PVP2350 probe. Menu names are given by function; if a label
differs slightly on your firmware, the function is what to look for.

### The DC value comes first, and not from the scope

Read each rail's DC voltage with a **multimeter**, not the scope. An 8-bit scope's DC gain accuracy
is a few percent, so a scope reading of "2.493 V" really means somewhere in 2.42 to 2.57 V. The
multimeter number is the one to put on a slide.

The board cannot check this itself: `AIN10` is tied to the same +2.5 V that is the ADC reference, so
it reads full scale by construction whatever the rail is actually doing.

### Three settings decide whether this measurement works at all

1. **Probe ratio 1X**, if your probe has a 1X position on its slider. Set the channel's probe ratio
   to 1X to match.
   In 10X the probe divides by ten before the scope, so the scope's own input noise appears **ten
   times larger** referred to the probe tip, and the most sensitive setting you can reach at the tip
   is 10 x 500 uV/div = 5 mV/div. You cannot resolve LDO ripple through that. 1X costs bandwidth
   (roughly 35 MHz), which does not matter for ripple.
   *If the probe is 10X only:* you are stuck with a floor of a few mV RMS. Say so explicitly in the
   presentation and report the rails as "at or below the measurement floor", which is a legitimate
   result. Steps 2 and 3 still help.
2. **Bandwidth limit 20 MHz.** Channel menu > `BW Limit` > `20M`. Noise grows with the square root of
   bandwidth, so going from 100 MHz to 20 MHz is about a 2.2x improvement.
3. **Acquisition mode `High Res`.** `Acquire` > `Mode` > `High Res`. This oversamples and averages
   adjacent samples, buying extra effective bits. Large effect at the slow timebases used here.
   Set `Acquire` > `Mem Depth` to a fixed high value (10M) rather than `Auto`, so there is plenty of
   oversampling for High Res to work with.

After all three, re-measure the floor. It should land well under 1 mV RMS. If it does not, something
else is wrong; do not proceed to the rails.

### AC coupling is what makes "RMS" mean "ripple"

Channel menu > `Coupling` > `AC`.

This matters more than it sounds. `Vrms` on the scope is the RMS of whatever is on screen,
**including DC**. On a DC-coupled 2.5 V rail, `Vrms` reads about 2.5 V and tells you nothing. AC
coupling removes the DC in the analog front end before the ADC, so `Vrms` becomes the ripple RMS,
and it also lets you turn the vertical scale right down into the ripple without the trace flying off
screen.

### Adding the measurements

`Measure` > add from the `Vertical` category:

- **`Vpp`** (peak to peak)
- **`Vrms`** (with AC coupling on, this is the ripple RMS)

Then turn **`Statistic` on**. The scope then shows `Cur`, `Avg`, `Max`, `Min`, `Dev` and `Count` for
each measurement, accumulated over many acquisitions.

**Report the `Avg` column for `Vrms`, and the `Max` column for `Vpp`.** Press `Reset Stat` at the
start of each condition, then wait.

The `Cur` column jitters from acquisition to acquisition, because each acquisition is a finite
sample of random noise. That is expected and is exactly what the statistics are there to absorb:
`Cur` is never the number you report.

How long to wait is not a fixed time, it is a question of how many acquisitions went in. Watch two
columns:

- **`Count`** is the real progress indicator. Deep memory makes acquisitions slow, often only a
  couple per second at 10 ms/div with 10M points, so a wall-clock minute may only be a hundred
  acquisitions.
- **`Dev`** is the spread between acquisitions. The uncertainty on `Avg` falls as `Dev` divided by
  the square root of `Count`.

**Stop when `Avg` has stopped moving in the digit you intend to report**, and write down `Count`
next to the result. `Count` matters most for `Vpp`: peak to peak is a maximum over everything seen,
so it keeps creeping up the longer you watch, and a `Vpp` quoted without its acquisition count is
not comparable to anyone else's.

Why both statistics matter:

- **`Vrms` is the reproducible number.** It is stable, it converges as more acquisitions accumulate,
  and it is what regulator datasheets quote. This is your headline figure.
- **`Vpp` is the worst-case number, and it is not reproducible.** Peak to peak is max minus min over
  the record, so on a noisy trace it grows with record length and with the number of acquisitions.
  Two people measuring the same rail get different `Vpp`. Quote it as a worst case, alongside the
  record length and acquisition count, never on its own.

### Timebase: take two captures per rail

- **10 ms/div** (100 ms of screen) with `High Res`. This is the low-frequency ripple capture: 50 Hz
  and 100 Hz mains content, and the roughly 100 ms WiFi beacon period. `High Res` is right here.
- **1 us/div** with `Acquire` > `Mode` > `Normal` and the 20 MHz limit still on. This is the
  broadband capture. Use `Normal`, not `High Res`: High Res is a filter, so it would under-report
  fast noise.

Report which acquisition mode produced which number. All three regulators are linear (ADP7142), so
there is no switching converter of the board's own, but the **Pico module has its own onboard buck**
on VSYS and the WS2812B LEDs draw in bursts, so high-frequency content can still appear.

Trigger: `Auto` mode is fine, since you are looking at noise rather than a specific event. For the
10 ms/div capture you can trigger on the channel itself near 0 V to stabilise a repeating component.

### The in-situ noise floor: the control test that decides everything

The bench noise floor from Part 3 is measured with the probe on its own clip, away from the board.
That is not the floor that applies at the measurement.

**Do this at the board, with the board powered and WiFi running:** touch the probe tip to the **same
ground pad its ground clip is attached to**, without changing anything else, and record `Vpp` and
`Vrms`.

The probe is now measuring zero volts through the real loop in the real electromagnetic environment.
Whatever it reads is pickup, not rail ripple.

- If the in-situ floor is close to what you measured on a rail, **you measured the loop, not the
  board.** Shrink the loop: probe across the regulator's output capacitor (1.9 mm between the rail
  pad and the ground pad) instead of test-point-to-header-pin, or fit a ground spring.
- If the in-situ floor is small and the rails are not, the rail figures are real.

**Run this once per condition** (idle, LEDs on, WiFi active), because pickup changes with what the
board is doing. It is the single most informative measurement in M7a: without it, a rail number is
just a number with no error bar.

A cross-check that costs nothing: the four rails sit in a cascade, `VEXT` into U1 (3.3 V) into U3
(2.5 V), and `VEXT` into U2 (5 V). Every LDO has substantial power supply rejection, so a
disturbance on `VEXT` cannot reach the 3.3 V rail at full amplitude, and certainly not the 2.5 V
rail behind two regulators. **If all four rails report the same ripple, the measurement is dominated
by something common to all four, which means pickup.** Real rail ripple must shrink as you move down
the cascade.

## Conditions to capture

Repeat the set for each state, because this is the comparison that makes the slide interesting:

- Board powered, Pico removed: the quiet baseline, just the regulators and the two ADCs.
- Idle: firmware running, no pedal plugged in.
- All four LEDs on at full allowed brightness. Worth a supply-current reading too, since the 200 mA
  rating of the 5 V regulator is the actual design constraint.
- WiFi access point up with a browser connected and the interface streaming.
- A pedal plugged in and being swept.

For each condition record six numbers per rail: `Vrms` average and `Vpp` maximum for the rail, and
the same two for the in-situ floor, plus the acquisition mode and timebase. A rail figure without
its floor is not reportable.

Note that supply current below about 10 mA will read as `0.00 A` on the DP932E, which is its display
resolution, not a measurement of zero. Expect a few mA with the Pico removed (two AD7718s plus the
regulators' quiescent current); use a multimeter in series if the exact figure matters.

## What to look out for

- **Attenuation mismatch.** If the rail reads 0.25 V instead of 2.5 V, the scope thinks the probe is
  1X. Fix the channel setting.
- **You are probably measuring your scope.** This is not a failure: it means you can honestly state
  "rail noise is at or below X, which is our measurement floor". Compare every rail figure against
  the in-situ floor for the same condition.
- **A rail reading below your floor proves contamination.** If a rail measures smaller than the
  floor alone, the "measurement" is entirely noise, since a real signal on top of noise cannot come
  out smaller than the noise by itself. Treat that as a settings problem, not a quiet rail.
- **Subtracting the floor.** Noise powers add, so for RMS values the ripple is
  `sqrt(measured^2 - floor^2)`. A rail at 500 uV against a 350 uV floor is really about 357 uV of
  ripple, not 500. This only works for RMS, never for peak to peak, and it becomes unreliable when
  the two are close: **if a rail reads less than about 1.4 times the floor, report it as "at or
  below the measurement floor" rather than subtracting.** With a low-noise LDO like the ADP7142 that
  is a likely and perfectly respectable outcome for the quiet conditions.
- **Remember to put the probe back to 10X** afterwards, both the slider and the channel setting, or
  every later measurement in this guide will read ten times too small.
- **AC coupling has a low corner** (a few Hz). Very slow drift will not show. That is what M10
  (warm-up drift, measured with the board's own ADC) is for.
- **Do not touch the probe tip with your fingers** while at millivolt sensitivity; you become an
  antenna.

---

# M7b: SPI signal integrity

**What you are measuring.** Whether the digital control signals are clean enough at 4 MHz: edge
shape, overshoot, and how long the chip select stays asserted around a transfer. This closes item 2
of the milestone-1 plan.

**Name of this measurement:** *signal integrity*. The specific quantities are **rise time** and
**fall time** (conventionally 10% to 90%), **overshoot** and **undershoot** (as a percentage of the
step), **ringing**, **setup and hold time**, and **propagation delay**. For the mechanism behind
what you will see, search **transmission line reflections**, **source series termination** and
**ground bounce**.

## Connections

Two probes, both with short ground leads to `A1` pin 23 (161.54, 127.51) or pin 28 (148.84, 127.51),
whichever is nearer.

- **Channel 1: TP7, `SPI0_CLK`** (159.00, 134.37). Nearest ground `A1` pin 23, 7.3 mm.
- **Channel 2**, pick per capture:
  - **TP8, `SPI0_TX`** (MOSI, 156.46, 134.37) to see data against clock.
  - **TP5, `SPI0_RX`** (MISO, 166.62, 134.37) to see the ADC's reply, which is the interesting one
    because it comes from the far end of the bus.
  - **TP6, `SPI0_NCS1`** (164.08, 134.37) to see the chip select framing, which is what the
    firmware's chip-select guard controls.

## Something to expect, not to be alarmed by

**Every digital line on this board has a 47 Ohm series resistor at its driver.** Verified: R3 to R6
and R46 to R49 at the microcontroller, R8 and R10 on the ADCs' data outputs, R7 and R9 on the ready
lines. That is deliberate source series termination: it slows the edges on purpose, to stop
reflections from ringing on an unterminated 2-layer board.

So a clean result here looks like a **visibly sloped edge with no ringing**, not a razor-sharp one.
Your measurement is a check that the slowing was enough and not excessive, not a hunt for ringing.
Do not "fix" a slow edge.

## Scope settings

1. Both probes `10X`, both channels set to `10X`, **bandwidth limit off** for this one. You are
   looking for fast detail, so do not filter it away.
2. Vertical: 1 V/div on both. The logic swings 0 to 3.3 V, so that fills three squares. Set the two
   channels' vertical positions so the traces do not overlap.
3. Coupling: **DC**. You care about the actual logic levels.
4. Trigger: source Channel 1, type `Edge`, slope rising, level about 1.65 V (mid-supply), mode
   `Normal`.
5. Three captures at three timebases. This is the part beginners skip, and it is where the
   information is:
   - **20 us/div or slower:** the whole transfer. You see the chip select go low, a burst of clock,
     and the chip select come back up. Measure the total burst length and the time from chip select
     falling to the first clock edge, and from the last clock edge to chip select rising. That last
     one is the **chip-select guard**, which the firmware sets to 10 us and which used to need 50 us
     on the breadboard.
   - **100 ns/div:** individual clock cycles. Check the period is about 250 ns (4 MHz) and that the
     duty cycle looks even.
   - **10 ns/div, zoomed onto one rising edge:** the edge itself. Use `Measure` to read **rise
     time**. Look at the flat part after the edge for overshoot and ringing.
6. For the edge captures, switch acquisition to **Average** (say 16 captures). The edges repeat
   identically, so averaging removes scope noise and gives you a clean edge to measure. **Then take
   one capture in `Peak Detect` as a cross-check**, to confirm averaging has not hidden a glitch.

## What to look out for

- **This bus is not continuously busy.** The firmware reads at 819 Hz, so transfers come in bursts
  roughly every 1.2 ms with long silence between. In `Auto` trigger mode you will see mostly flat
  line. Use `Normal` mode so the scope waits for a real transfer.
- **A long ground lead invents ringing.** If you see 20 MHz ringing on every edge, before believing
  it, shorten the ground connection and look again. This is the classic false positive, and it is why
  the nearest-ground table exists.
- **Probe both chip selects (TP6 and TP9) at some point.** The two ADCs share clock and data, and
  the driver converts on both chips at once, so confirming the chip selects never overlap is a real
  correctness check, not just a picture.
- **TP10 and TP11 (`NRDY1`, `NRDY2`) are worth one capture each.** These go active when a conversion
  finishes. Putting one of them on Channel 2 against the chip select on Channel 1 shows you the
  actual conversion timing: how long after the ready signal the firmware starts reading. That is
  directly the 0.35 ms of overhead mentioned in `docs/fast-tracking.md`.
- **Do not probe `SR_CLK` and `SPI0_CLK` expecting them to be related.** They are separate buses,
  SPI1 and SPI0.

---

# M8: Tap settling

**What you are measuring.** When the firmware changes which contacts are pulled up and down, the
jack contact and the ADC's input filter have to charge. The firmware waits a computed time before
reading. This measurement checks that model against the real curve.

This is the most valuable scope measurement in the programme, because it is the only one where the
answer is not already known.

**Name of this measurement:** *step response* of an RC network, and **settling time**. The number
you extract is the **time constant** (tau). Search `RC step response`, `RC time constant 63%`,
`settling time to 1 percent`, `first order step response`.

## The model you are testing

The firmware waits `2 x (network_resistance + 10 kOhm) x 10 nF`, clamped to between 1 ms and 400 ms.
Verified in `src/topology/scanner.rs` (`SettleConfig`) and the override at
`src/bin/expression_controller.rs:347`.

Two time constants is the part worth checking. After two time constants an RC curve has covered
about 86.5% of the step, leaving **13.5% of the step still uncorrected** when the firmware starts
the conversion. The argument that this is nevertheless fine is that the AD7718's sinc-cubed filter
averages over three conversion periods afterwards, so the residual is averaged down rather than read
directly.

That argument is plausible and untested. If your capture shows the residual is significant, that is
a real finding and belongs in the presentation. If it shows the curve is flat well before the
firmware reads, you have validated a design decision with a measurement, which is exactly what the
advisor asked for.

## Connections

Two probes.

- **Channel 1: TP2, `SR_LAT`** (135.38, 140.46), ground clip to `A1` pin 8 (136.14, 145.29), only
  4.9 mm away. This is the shift register latch: it pulses at the exact instant new switch settings
  take effect, so it is your time zero. This is the whole trick of this measurement.
- **Channel 2: a jack 1 contact.** Use `J2.R` (ring, 136.40, 183.56) or `J2.S` (sleeve, 136.40,
  189.91), whichever the drive pattern is switching. Ground: solder a wire loop from `U6` pin 8
  (jack 1's shift register ground, 3.7 mm from `J2.T`), or accept `A1` pin 8 about 32 mm away, which
  is fine at these speeds.

**Remember Part 1: the sleeve is not ground.** Channel 2's ground clip goes on a GND pad, not on the
jack.

## Scope settings

1. Both probes `10X`, channels set to `10X`, **bandwidth limit on** (you are looking at a
   millisecond curve; 20 MHz of noise only obscures it).
2. Channel 1 (`SR_LAT`): 1 V/div, DC coupling. Position it near the top of the screen, out of the
   way.
3. Channel 2 (the contact): 500 mV/div, DC coupling. The contact swings between roughly 0 V and
   2.5 V, so that is five squares. Position the trace so the whole swing is on screen.
4. Trigger: source **Channel 1**, type `Edge`, slope rising, level about 1.65 V, mode `Normal`.
   Triggering on the latch rather than on the analog curve is what makes the timing meaningful: you
   are measuring from the command to the response.
5. Timebase: start at **500 us/div**, which gives a 5 ms window, enough to contain a 1 ms wait plus
   the curve. Then zoom to **100 us/div** once you have found the edge.
6. Acquisition: **Average** over 16 or 64 captures, since the pattern repeats. Take one `Normal`
   single capture as well to confirm averaging is not smoothing away something real.

## What to measure

Use cursors rather than automatic measurements, because the quantities you want are specific:

- **Time constant.** Put one cursor at the start of the step, read the voltage there and at the end,
  then find the time at which the curve has covered 63.2% of the difference. That time is tau.
  Compare against `(network + 10 kOhm) x 10 nF` for the resistance you have plugged in.
- **How far the curve has settled when the firmware reads.** Measure at `2 x tau` after the latch
  edge and express the remaining error as a percentage of the step. The prediction is 13.5%.
- **Whether the 1 ms floor dominates.** For a 10 kOhm pedal the computed wait is
  `2 x (10 + 10) x 10 nF = 400 us`, which the 1 ms minimum overrides. So for common pedals the real
  wait is 1 ms, which is 2.5 time constants, not 2. Check that on screen: it is a nicer result than
  the calculation suggests, and worth saying.

## Run it with known resistors

This measurement is much more informative with a decade box than with a pedal, because you can set
the resistance and predict tau in advance. Do at least 10 kOhm, 100 kOhm and 500 kOhm and plot
measured tau against predicted. At 500 kOhm the predicted wait is
`2 x (500 + 10) x 10 nF = 10.2 ms`, which is comfortably visible, and it is the case where getting
it wrong would matter most.

## What to look out for

- **The probe adds capacitance.** A 10X probe adds roughly 10 to 15 pF, against the 10 nF already
  there. That is about 0.1%, so it is genuinely negligible here. Worth knowing, because on other
  measurements it would not be.
- **The contact you probe may not be the one moving.** The firmware changes which contacts are
  driven depending on what state the jack is in. Look at the Channel 2 trace in `Auto` mode first to
  find a contact that actually steps, then set up the trigger.
- **`SR_LAT` pulses for every jack, not just jack 1.** The four shift registers share the latch, so
  you will see latch pulses that do not correspond to any change on the contact you are watching. In
  `Normal` mode with averaging this shows up as a blurred Channel 2 trace. If it does, trigger on
  Channel 2's own edge instead and accept that you lose the absolute timing reference, or use the
  scope's `Trigger Holdoff` to skip pulses.

---

# M4: Recognition time, and the state machine on screen

**What you are measuring.** How long it takes from inserting a plug to the firmware tracking the
pedal. Documented as under about 0.1 s. This one doubles as the best picture in the presentation,
because the drive pattern on a contact changes visibly as the state machine advances, so one capture
shows plug detection, identification and following as three distinct regions.

**Name of this measurement:** *single-shot capture* of a one-off event. Related searches:
`oscilloscope single shot trigger`, `oscilloscope pre-trigger`, `oscilloscope deep memory`,
`oscilloscope segmented memory`.

## Why the tip switch is your trigger

Each jack has a tip switch contact (`TN`) that touches the tip while no plug is inserted. The
firmware checks for a plug every 50 ms by pulling the tip low and `TN` high, then reading `TN`: it
reads about **1.25 V with no plug** (two 1 kOhm pulls in series) and about **2.5 V with a plug**
(the tip switch has been pushed open). Verified in `docs/fast-tracking.md` and
`topology/src/monitor.rs`.

So `TN` carries a clean, monotonic, roughly 1.25 V step at the moment of insertion. That is your
trigger, and it is far more reliable than trying to trigger on the mechanical scrape of the plug
going in.

## Connections

Two probes, on jack 1 (`J2`).

- **Channel 1: `J2.TN`** (tip switch, 120.17, 177.22). Ground: a wire from `R54` pad 2 (5.3 mm away)
  if you solder one, otherwise `A1` pin 8.
- **Channel 2: `J2.R`** (ring, 136.40, 183.56) or `J2.T` (tip, 136.40, 177.22). This is the trace
  that shows the drive pattern changing through the states.

## Scope settings

1. Both probes `10X`, channels `10X`, bandwidth limit on.
2. Both channels: 1 V/div, DC coupling, vertical positions set so the two traces are separated and
   both fit.
3. Timebase: **20 ms/div**, giving a 200 ms window. The documented recognition time is about 100 ms,
   so this fits comfortably with room either side. If your scope has deep memory, 50 ms/div with a
   500 ms window shows the whole story including a few plug-check cycles beforehand.
4. Trigger: source **Channel 1** (`TN`), type `Edge`, slope **rising**, level about **1.9 V**
   (between the 1.25 V unplugged and 2.5 V plugged levels), mode **`Single`**.
5. **Set the pre-trigger position to about 25% from the left**, so you capture some of the
   before-state as well as the after. The control is usually a horizontal position knob or a
   `Delay` setting, and the little marker at the top of the screen shows where the trigger sits.
6. Press `Single` to arm. The scope shows `Ready` or `Armed`. Then insert the plug.
7. The scope freezes on the capture. Save it as a screenshot **and as a data file if the scope
   supports it**, because you will want to annotate it later.

## What you should see, and how to read it

Because `TN` is only driven during the plug check, Channel 1 will show a **series of pulses every
50 ms** rather than a continuous level. The insertion shows up as the pulse amplitude changing from
about 1.25 V to about 2.5 V. That periodic pattern is itself worth pointing at on the slide: it is
the 50 ms plug poll, visible.

On Channel 2 you should then be able to mark out three regions and measure each with cursors:

- **Before:** quiet, with brief activity every 50 ms as each plug check happens.
- **Identification:** a dense burst of activity, as the solver drives pairs of contacts against each
  other back to back. Documented at roughly 45 ms.
- **Following:** a settled, regular pattern, since a tracked pedal is driven with the two track ends
  held and only the wiper read, with one end tap checked every 25 ms.

The interval from the first high `TN` pulse to the start of the settled pattern is your recognition
time. Compare it against the documented figure of under 0.1 s.

## Also capture the unplug

Same setup, trigger slope **falling**, level 1.9 V again. Documented as noticed within about 0.1 s.

## What to look out for

- **Press `Single` before you plug in.** Obvious, easy to forget, and you will do it wrong at least
  once.
- **You get one attempt per arming.** If the capture is bad, press `Single` again and pull the plug
  out first.
- **Mechanical insertion is not instantaneous.** A plug takes tens of milliseconds to slide in, and
  it connects contacts in sequence on the way. That is not scope error, it is the real phenomenon,
  and it is exactly what caused the plug-insertion bug described in the presentation scaffold
  (section 5.3). Capturing it is a bonus.
- **Insert the plug slowly once, deliberately,** as a separate capture. The transient sequence will
  be clearer and it is the more interesting picture.
- **Timebase too fast is the usual failure.** At 1 ms/div you capture 10 ms and see nothing
  meaningful. Start slow, then zoom into the saved capture if your scope allows it.

---

# M5: End-to-end latency

**What you are measuring.** The time from the pedal's resistance changing to the MIDI message
reaching the host. This is item 6 of the milestone-1 plan and the one measurement with no obvious
instrument, so it needs splitting into two parts measured two different ways.

**Name of this measurement:** *propagation delay* or *time interval measurement* between two
channels. For the two-part approach, the general technique is called **latency budgeting**. For the
software half, search `MIDI timestamp latency measurement`, `USB MIDI latency`.

## The split

- **Part A, sensor to packet:** measurable on the scope, as the time from a resistance step to the
  firmware handing the MIDI packet to USB.
- **Part B, packet to host:** not visible on a scope, because it happens inside the USB stack and
  the host operating system. Measure it in software.

Report both and their sum, and say which dominates. A single number with no breakdown invites the
question "where does that time go?", which you then cannot answer.

## Part A: the scope half

**You need a firmware change first:** a spare GPIO that toggles at the moment the firmware hands a
packet to USB. This is a few lines in `src/bin/expression_controller.rs`.

**Check this before planning around it.** GPIO0 to GPIO5, GPIO7 to GPIO10, GPIO12 and GPIO26 to
GPIO28 are unconnected in the netlist, so a free pin exists in the design. But the Pico module is
soldered to the board with a header (`Pico_2W_with_Header`), so whether you can reach a specific
unused pin depends on how the header is populated and which side. **Look at the actual board before
writing the firmware change.** If the header is fully populated, any unused GPIO pin is directly
clippable, which makes this easy.

**Fallback if no pin is reachable:** trigger on `SR_LAT` at TP2 or a chip select at TP6, as a proxy
for firmware activity. Less direct, since it tells you when the firmware measured rather than when
it sent, but it needs no hardware change and still bounds the sensor-side latency.

### Connections

- **Channel 1: the resistance step.** Wire a pushbutton or a switch to short out part of a resistor
  network feeding jack 1, and probe the node that steps. Simplest version: a switch that shorts one
  arm, with the probe on the jack contact that changes (`J2.T` or `J2.R`). Ground as in M8.
- **Channel 2: the spare GPIO** on the Pico header, ground clip to the nearest `A1` GND pin, which is
  at most a few pins away.

### Scope settings

1. Both probes `10X`, channels `10X`, bandwidth limit on.
2. Channel 1: 500 mV/div, DC. Channel 2: 1 V/div, DC.
3. Trigger: source **Channel 1**, `Edge`, slope matching your step direction, level in the middle of
   the step, mode **`Single`** (the event is one-off, since you press the button once).
4. Timebase: **1 ms/div** to start, giving 10 ms. The update period at 819 Hz is about 1.2 ms and
   the full path should be a handful of milliseconds, so 10 ms should contain it. Widen to 5 ms/div
   if the GPIO edge falls off the right of the screen.
5. Pre-trigger position about 10% from the left, since everything you care about happens after the
   trigger.
6. Measure the interval with **cursors**, or use the scope's automatic `Delay` measurement between
   channels if it has one (often under `Measure > Delay` or `Time > Ch1 to Ch2`).

### What to look out for

- **Take many captures, not one.** The firmware polls, so the delay depends on where in the poll
  cycle your step lands. You will see it vary by roughly one update period. **Report a minimum,
  maximum and typical, not a single number** — the spread is the interesting part, and quoting one
  number when the real answer varies by a millisecond is the kind of thing that draws an awkward
  question.
- **A mechanical switch bounces.** The contact will chatter for a few milliseconds and the scope may
  trigger on the first blip. Either accept it and note it, or use the scope's **trigger holdoff** to
  ignore edges shortly after the first, or debounce the switch with a small RC. Bounce is also why
  an analog switch or a signal generator step is cleaner if you have one.
- **The step must be big enough to cross a MIDI value boundary.** One MIDI step is 1/127 of the
  configured range, so a tiny resistance change may produce no message at all and no GPIO edge. Make
  the step large, at least 10% of travel.

## Part B: the software half

Two options, both without a scope:

- **Round trip with the existing loopback firmware.** `src/bin/midi_loopback.rs` echoes every USB
  MIDI packet back to the host. Send a packet from the host, timestamp it, catch the echo,
  timestamp that. Half the round trip is a fair estimate of one direction, and it includes the host
  stack on both sides, so it is an upper bound.
- **Timestamping MIDI monitor.** Run a MIDI monitoring tool that timestamps incoming messages, and
  compare against a host-side reference event.

State clearly on the slide which of Part A and Part B you measured how, and that the sum is a sum of
two separately measured terms rather than one end-to-end capture. That is a completely respectable
result and much stronger than a single unexplained number.

---

# Appendix A: Glossary

- **Attenuation (1X / 10X).** How much the probe divides the signal. Must match the scope's channel
  setting.
- **Coupling (AC / DC).** Whether the scope shows the true voltage (DC) or subtracts the average to
  magnify the wobble (AC).
- **Volts/div, Time/div.** The scale of one grid square, vertically and horizontally.
- **Trigger level, slope, source.** The voltage, direction and channel that tell the scope when to
  start drawing.
- **Holdoff.** A dead time after a trigger during which the scope ignores further triggers. Cures
  false triggering on bouncing or bursty signals.
- **Pre-trigger.** How much of the screen shows time *before* the trigger. Essential for one-off
  events.
- **Persistence.** How long old traces stay on screen. Infinite persistence accumulates every
  capture, which is how you see jitter and rare outliers as a band rather than a line.
- **Peak detect.** An acquisition mode that keeps the extreme sample in each interval, so narrow
  spikes are not missed between samples.
- **Averaging.** Overlaying many triggered captures to cancel random noise. Requires a repeating,
  trigger-stable signal.
- **High resolution mode.** Oversampling and filtering to gain effective bits. Good for small
  signals at slow timebases.
- **Bandwidth limit.** A filter that discards high-frequency content, usually above 20 MHz.
- **Rise time.** How long an edge takes to go from 10% to 90% of its final value.
- **Overshoot.** How far past its final value an edge goes, as a percentage of the step.
- **Time constant (tau).** For an RC network, `R x C`. The curve covers 63.2% of a step in one tau,
  86.5% in two, 95% in three, 99.3% in five.
- **Settling time.** How long until a signal stays within some tolerance of its final value.
- **PARD.** Periodic and random deviation: the power-supply industry's name for ripple plus noise.
- **PSRR.** Power supply rejection ratio: how well a regulator attenuates disturbance on its input.

# Appendix B: Troubleshooting

| Symptom | Likely cause |
|---|---|
| Voltages ten times too small or too large | Probe attenuation does not match the channel setting |
| Flat line, nothing at all | Wrong pin; or the signal is bursty and the trigger mode is `Normal` with no trigger arriving; or the board is not powered (the analog rails need the barrel jack, not just USB) |
| Trace smears horizontally | No stable trigger. Set an appropriate source and level, and use `Normal` |
| Trace jumps around vertically | Probably a genuine floating node, or a ground clip that is not on ground |
| Ringing on every fast edge | Ground lead too long. Shorten it before believing the ringing |
| Square wave has rounded or peaked corners | Probe not compensated (Part 3 step 3) |
| Rail ripple looks the same on every rail | You are measuring the scope's noise floor, not the board |
| 50 Hz sine riding on everything | Mains pickup. Shorten the ground loop, keep the probe cable away from the power supply, and note the documented 50 Hz hum figures |
| Two channels short something when both connected | Both ground clips are joined inside the scope. Both must be on GND |
| Everything reads about 0 V at a jack | The contact is floating in the current state, which is a valid state, not a fault |

# Appendix C: Things to get before you start

- A second probe, compensated, if you do not have two. M8, M4 and M5 all need two channels.
- A 0.1 inch pin header strip, soldered into TP5 to TP11, and optionally TP1 to TP4.
- A short ground wire soldered to a GND pad near the jacks (`U6` pin 8 is the closest to jack 1),
  looped so you can clip onto it.
- A plastic trimmer tool for probe compensation.
- The barrel jack power supply. The analog frontend derives from it, `VBUS` is unconnected, and a
  Schottky blocks the Pico from back-feeding the 5 V rail, so **USB alone will not power what you
  are measuring.** Confirm this on the bench once, at the start.
- A decade resistance box or a set of precision resistors with a TRS plug wired to them. This is
  worth more to the evaluation than any scope measurement here, since it is what M2, M3 and the
  quantitative half of M8 all need.

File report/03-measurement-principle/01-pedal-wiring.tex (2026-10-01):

% !TEX root = ../main.tex

\section{Expression Pedal Wiring}
\label{sec:pedal-wiring}

\scaffold{
  \textbf{Paragraph 1.} Link: \cref{ch:introduction} named the two common wirings. Show them in \cref{fig:pedal-wirings} and name each panel: wiper on the tip with ring as reference and sleeve as ground, wiper on the ring with tip as reference \cite{mission2014expression, nonlinearlabs2026pedals}, and the two-wire variants that connect only tip and sleeve. Point out that the sleeve is a track end in both common three-wire wirings; \cref{sec:following} builds the position convention on this.
}

\begin{figure}[htbp]
  \centering
  
  \titledcaption{Expression Pedal Wirings}{\scaffoldinline{Name the four panels (which contact carries the wiper, which end goes to the sleeve, which variant is two-wire) and say that the potentiometer symbol is the pedal and the plug drawing the TRS plug. Source: drawing from the final presentation; check whether the four panels match the four cases named in the text, otherwise redraw.}}
  \label{fig:pedal-wirings}
\end{figure}

\scaffold{
  \textbf{Paragraph 2, pedal types and plugs.} Besides potentiometer pedals, the interface accepts sustain switches and two-wire rheostats. Which contacts conduct depends on the plug: a mono (TS) plug shorts the jack's ring contact to its sleeve, a stereo (TRS) plug leaves it unconnected. \Cref{tab:pedal-networks} lists the resulting networks; it is the reference the classification in \cref{sec:following} checks against.
}

\begin{table}[htbp]
  \centering
  \titledcaption{Pedal Networks Behind Mono and Stereo Plugs}{\scaffoldinline{Explain that each cell names which jack contacts conduct; source: \code{docs/fast-tracking.md} of the project repository.}}
  \label{tab:pedal-networks}
  \begin{tabularx}{\linewidth}{@{}l>{\raggedright\arraybackslash}X>{\raggedright\arraybackslash}X@{}}
    \toprule
    \textbf{Pedal} & \textbf{Mono plug (TS)} & \textbf{Stereo plug (TRS)} \\
    \midrule
    Potentiometer & track halves in parallel (see text) & three arms, wiper near the star point \\
    Switch, released & tip open, ring and sleeve shorted & nothing conducts \\
    Switch, pressed & all contacts shorted & tip and sleeve shorted, ring open \\
    Rheostat & tip carries it, ring and sleeve shorted & tip and sleeve carry it, ring open \\
    Cable without pedal & as a released switch & nothing conducts \\
    \bottomrule
  \end{tabularx}
\end{table}

\scaffold{
  \textbf{Paragraph 3, the mono-cable limit.} Most pedals' own jacks short their ring terminal to the sleeve when a mono plug is inserted. For a potentiometer this puts the two track halves in parallel, which gives the resistance $R\,x(1-x)$ at travel $x$ for a track of $R$: zero at both ends and $R/4$ in the middle. Derive this in one line. Conclude that the position cannot be recovered from any measurement, so potentiometer pedals need a stereo cable; this is a property of the pedal, not of the interface.
}

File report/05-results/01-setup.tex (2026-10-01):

% !TEX root = ../main.tex

\section{Measurement Setup}
\label{sec:results-setup}

\scaffold{
  \textbf{Paragraph 1, equipment.} Oscilloscope Rigol MSO5104, laboratory supply Rigol DP932E, shown in \cref{fig:measurement-setup}; the ADCs of the board itself serve as the instrument for everything below the oscilloscope's resolution (noise, position), and the firmware logs over the debug probe for rates and state changes. Name the test points used per measurement (\cref{sec:pcb}). Give the supply voltage used for all measurements.
}

\scaffold{
  \textbf{Paragraph 2, a lesson on probes.} The first oscilloscope captures were taken with the probes on 1X. Three independent signs revealed it: floating contacts discharged with a time constant of about \qty{10}{\milli\second} (the \qty{1}{\mega\ohm} input against \qty{10}{\nano\farad}), a contact showed about \qty{150}{\pico\farad} of load, and SPI edges looked like they were driving 100 to \qty{130}{\pico\farad}. All timing and edge measurements were repeated at 10X, which loads the circuit far less \cite{tektronix2026probes}; the supply ripple measurements are taken at 1X on purpose, for the lower noise floor. State this in two sentences as part of the method, not as an apology.
}

\begin{figure}[htbp]
  \centering
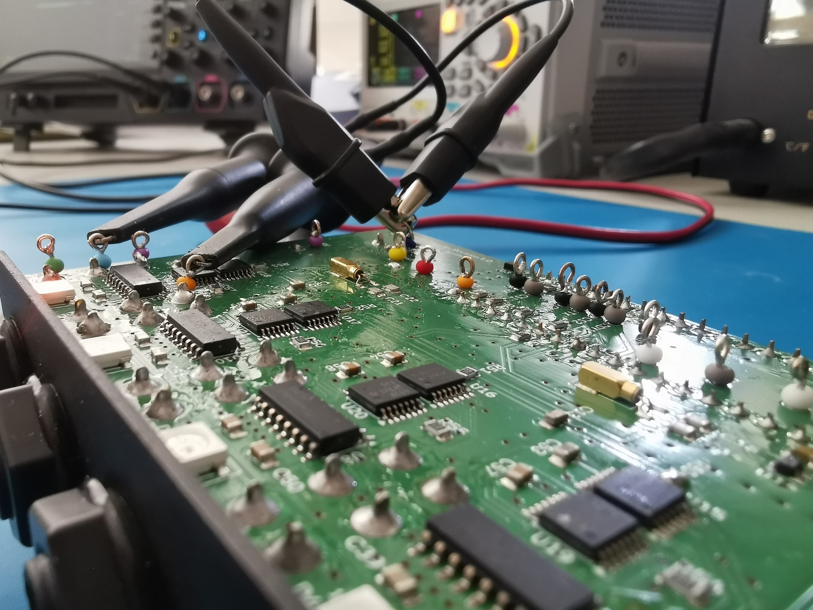
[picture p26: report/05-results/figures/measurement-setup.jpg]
  
  \titledcaption{Measurement Setup}{\scaffoldinline{Name the board, the probes and their test points, the pedal and the instruments visible in the photo.}}
  \label{fig:measurement-setup}
\end{figure}

\openquestion{Supply voltage of the measurements}{
  Give the input voltage set on the DP932E for the measurements and the probe model used.
}

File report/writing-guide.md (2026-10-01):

# Writing Guide for Course Reports

Content and language rules for a project report at TU Berlin, Chair of Sensor and Actuator Systems.
Derived from the accepted report *Simulation of a Percussive Synthesizer with Macro Controls*
(drumsynth-report). The rules are independent of the writing tool. Generic rules (a report has a title
page, a bibliography, page numbers) are omitted.

## 0. Index

| Looking for | Section |
|---|---|
| Meaning of the words used in this guide | [1. Terms](#1-terms) |
| Which parts the report has, in which order | [2. Document Order](#2-document-order) |
| What each chapter contains | [3. Chapters](#3-chapters) |
| How a section and a paragraph are built | [4. Sections and Paragraphs](#4-sections-and-paragraphs) |
| Person, voice, tense | [5. Voice and Tense](#5-voice-and-tense) |
| Sentence construction, punctuation | [6. Sentences](#6-sentences) |
| Technical terms, abbreviations, names of parts and signals | [7. Naming](#7-naming) |
| Figures, tables, equations | [8. Figures, Tables and Equations](#8-figures-tables-and-equations) |
| Citations | [9. Citations](#9-citations) |
| Numbers and units | [10. Numbers and Units](#10-numbers-and-units) |
| Tone | [11. Tone](#11-tone) |
| Final check | [12. Checklist](#12-checklist) |

## 1. Terms

| Term | Meaning in this guide |
|---|---|
| report | The whole document handed in. |
| project | The practical work the report documents. |
| chapter | A numbered top-level part (Introduction, Implementation, ...). |
| section | A numbered part inside a chapter. |
| float | A figure or a table. |
| caption | The text attached to a float: a short title and a description. |
| source | An external publication, datasheet, product page or repository listed in the bibliography. |
| citation | The numbered reference to a source in the text, e.g. [4]. |
| block | One functional unit of the project (a circuit, a module, a program part). |
| design value | A chosen quantity of the project (a resistance, a rate, a threshold). |

## 2. Document Order

1. Title page: university, faculty, institute, chair; document type (`Report`); title; `In the course` with
   course name and submission date; author with matriculation number; supervisor (professor) and
   `Assisted by` (assistant).
2. Statutory declaration (`Eidesstattliche Erklärung`): the institution's fixed German text, place, date,
   signature line. The fixed text requires that every AI tool is named in the report.
3. `Notice on the Use of AI Tools`: unnumbered chapter, one paragraph (see [3.1](#31-notice-on-the-use-of-ai-tools)).
4. `Abstract`: unnumbered chapter.
5. Table of contents.
6. Numbered chapters: Introduction, Related Work, (Theory), Implementation, (Results), Discussion,
   Conclusion and Outlook. Chapters in parentheses are optional; their content may live in Implementation.
7. Appendix: one chapter, sections per item (listings, tables of design values).
8. Bibliography, list of figures, list of tables.

## 3. Chapters

### 3.1 Notice on the Use of AI Tools

- One paragraph. One sentence per tool: product name, manufacturer, version, purpose, citation of the tool.
- Name the concrete work product the tool contributed to (e.g. "the Python script for extracting ...")
  and cite the repository holding it.
- Final sentence: all AI-generated content was reviewed and verified by the author, who takes full
  responsibility for the final content.

### 3.2 Abstract

- One paragraph, about 10 sentences, no citations, no abbreviations without their full form.
- Sentence order: context of the field -> problem -> what the project presents -> its parts (one sentence
  listing them with a dash-enclosed enumeration) -> how the central part is realized -> how the design was
  developed and verified -> results -> one concluding sentence on what the results show.
- The abstract states results; it does not announce that results will be shown.

### 3.3 Introduction

- Purpose: background, the niche the project occupies, motivation, the minimal fundamentals needed to
  follow the report.
- Paragraph order: (1) the field and why it matters, with sources; (2) the underlying structure or
  principle of the problem domain, with sources; (3) the concrete difficulty, with sources showing it is
  known; (4) "Concretely, ..." the project's approach in two to four sentences; (5) the development and
  verification tool or method, with a source showing it has worked before.
- No figures. No results. No chapter-by-chapter roadmap.

### 3.4 Related Work

- One section per group of existing work. Name the group in italics when it is defined
  (e.g. *Per-voice analog clones*), then give two or more examples with manufacturer and citation.
- Each section ends with one sentence that places the project against the group: what none of them
  combine, or how the project applies the same principle to a different target.
- Short: two to five sentences per section. No figures.

### 3.5 Implementation

- Opens with an overview paragraph and a block diagram: which blocks exist and how signals flow between
  them. One sentence per block.
- Then one sentence on how blocks were developed and tested individually.
- Then one section per block, in signal-flow order (see [4](#4-sections-and-paragraphs)).
- A development observation that changed the method (e.g. simulation too slow, so intermediate signals are
  cached) is reported where it occurred, with its consequence.
- Last section: `Results`. It describes the assembled system, the test that was run (conditions in the
  caption), and what the output shows. Results are statements about the figure, not interpretation.

### 3.6 Discussion

- No new results, no figures.
- Paragraph order: (1) what was shown, in one or two sentences, and its limit (e.g. linear only);
  (2) evaluation of the method or tool: what worked, what failed, how the failure was mitigated;
  (3) limitations of the current design, each with the known remedy and a source.
- Prose only, compact paragraphs.

### 3.7 Conclusion and Outlook

- Paragraph order: (1) one manual or limited step of the project and how it could be automated or
  extended, with sources for the methods; (2) a second extension; (3) one closing sentence beginning
  "Overall, this work demonstrates that ...".
- No new facts about the project.

### 3.8 Appendix

- Material referenced from the text but too long for it: listings, full tables of design values, scripts.
- Each item is a section with a label so the text can reference it.

## 4. Sections and Paragraphs

- A section about a block follows this order:
  1. Purpose in context: what gap the previous blocks leave and how this block fills it.
  2. Physical or algorithmic principle, with a source.
  3. Realization, walking through the figure: component by component, in the order the signal passes.
  4. Derivation of the governing equations, step by step.
  5. Design values: computed from the equations, given in a table if there are more than three.
  6. Floats.
- The first sentence of a section links to what the reader already knows
  (e.g. "While the two noise generators ..., the pitched oscillator ...";
  "The three presented signal sources generate continuous output. For an accurate ..., however, ...").
- One paragraph has one topic. A paragraph has three to eight sentences.
- Every design choice is followed in the same or the next sentence by its reason:
  "X is therefore preferred over Y, whose ... is not suited to ...".
- An intentional choice that looks unusual is marked as intentional and justified
  ("This comparatively high cutoff is chosen intentionally, as ...").
- A simulation or measurement artefact is named as such and separated from the property of the circuit
  ("... is a simulation artifact of ... rather than a property of the circuit").
- Body text contains no bullet lists. Enumerations are written as sentences.

## 5. Voice and Tense

- No first person (no "I", "we", "our"). The project or the report is the subject ("This project
  presents ...", "this work demonstrates ..."), or the sentence is passive.
- "The author" appears only in the AI notice.
- Present tense for the design and how it works ("The capacitor is charged ...", "The matrix is realized
  as ...").
- Present passive for the method as a procedure ("A dedicated test circuit is then used ...").
- Past tense for events of the project and for findings ("It was shown that ...", "LTspice proved ...",
  "During development, it became clear that ...", "the weights were determined by hand").
- Results chapter and captions describe the figure in present tense ("The first hit blends ...").

## 6. Sentences

- One sentence states one concept.
- Typical length 15 to 30 words. Split a sentence that needs two "and"-joined main clauses.
- A colon introduces the elaboration of a general statement
  ("... share a consistent base structure: a short broadband attack transient, followed by ...").
- A dash pair (en dash with spaces) encloses an inline enumeration or an aside
  ("three sound sources – an analog ..., a ..., and a ... – each shaped by ...").
- Connectives that carry logic, placed at the start or after the subject: "therefore", "however",
  "instead", "thus", "additionally", "concretely".
- Causal chains are explicit: "As X falls, Y decreases, producing Z."
- Quantitative statements carry a number: "around 10 V peak-to-peak", not "a large amplitude".
- Informal words in quotation marks only when meant figuratively ("listen" to a waveform).

## 7. Naming

- One term per concept for the whole report. Define it at first use; never switch to a synonym.
- Abbreviation: full form at first use, abbreviation in parentheses ("digital musical instrument (DMI)").
  Write out the full form again in the abstract.
- Category names are italic at the point of definition only.
- Components are named with their schematic designator in math italics ($R_5$, $C_2$, $Q_3$, $U_1$),
  identical to the figure.
- Signals and nodes are named exactly as in the tool output (e.g. `V(gate)` in monospace); the caption
  defines each one shown.
- Part numbers in upright text (TL072, OPA1678) with a datasheet citation at first mention.
- Commercial products: manufacturer and product name ("Mutable Instruments Plaits"), cited.
- Software and tools: product name, cited at first mention.
- Code identifiers in monospace, only when the reader needs them to find the code.

## 8. Figures, Tables and Equations

- Every float is referenced in the text before or at the position it appears, by its full name
  ("Figure 3.2", "Table 3.1"). The reference is part of the sentence ("shown in Figure 3.1") or a
  parenthesis after the claim ("(Figure 3.4)").
- Caption form: short title for the list of figures, then the caption itself:
  **Title in Title Case** – one to four sentences.
  The sentences say what the float shows, define every label, symbol and signal in it, and state the
  test conditions (input, duration, values). A caption is understandable without the body text.
- Sub-figures carry a Title Case sub-caption and are referenced as (a), (b), ... in the main caption.
- A schematic and its waveform are grouped as sub-figures of one figure.
- Tables: bold header row, units in the header or with each value, caption with the source of the values.
- Images from tools (schematics, plots) are used as produced; the caption explains what to look at.
- Equations: numbered when referenced or derived. Derivations show every step that changes the form; a
  condition is written as "set equal" (an exclamation mark over the equals sign) followed by the solved
  form. Subscripts that are words are upright (t_dis, V_DD).
- Every symbol is defined in the sentence before or directly after its first equation.
- A derived formula is immediately applied to a design value with units
  ("this yields a current of I_E = ... = 6 µA, which is realistic for that transistor model [12]").
- Vectors and matrices bold.

## 9. Citations

- Numeric style (IEEE), sorted by name, year, title.
- Every external fact carries a citation: physical effects, prior circuits, part properties, product
  features, historical claims.
- The citation stands at the end of the claim it supports, before the full stop; several sources share one
  bracket.
- An author-name citation ("As Werner et al. explain ...") when the text builds on one source's
  explanation.
- Datasheets, product pages and blog posts are valid sources; give manufacturer as author, document
  number, revision, URL and access date.
- The project's own repository is a source and is cited where its code or data is used.
- Physical-principle sources are textbooks or papers; component-behaviour sources are datasheets.

## 10. Numbers and Units

- SI units with a (thin) space between number and unit: 10 kΩ, 4.8 kHz.
- Ranges with the unit on both ends or a range form: -12 V to 12 V.
- Intermediate calculations shown with units, the result rounded to the precision that matters
  (≈ 4.8 kHz).
- Dimensionless values to three significant digits in tables.
- Equal precision within one table column.

## 11. Tone

- Documentation, not advertisement. No "novel", "innovative", "state-of-the-art", "powerful".
- Significance is stated once (Introduction, Related Work closing sentences, Discussion first paragraph),
  not in every chapter.
- Evaluative words ("valuable", "well suited") only with the reason in the same sentence.
- Limitations are stated as facts with their cause and remedy, not apologised for.
- No rhetorical questions, no exclamations, no addressing the reader.

## 12. Checklist

- [ ] Document order as in section 2; AI notice names product, manufacturer, version, purpose.
- [ ] Abstract one paragraph, ~10 sentences, no citations.
- [ ] No first person; tenses as in section 5.
- [ ] No bullet lists in body text.
- [ ] Each section opens with a link to known content and follows the order in section 4.
- [ ] Each design choice has its reason; each external fact has its citation.
- [ ] Each float referenced in text; each caption has title, description, label definitions, conditions.
- [ ] Each symbol defined; each formula applied to a value with units.
- [ ] One term per concept; abbreviations defined at first use.
- [ ] Discussion and Conclusion contain no new results.

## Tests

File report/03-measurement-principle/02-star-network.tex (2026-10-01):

% !TEX root = ../main.tex

\section{Star Network Model}
\label{sec:star-network}

\scaffold{
  \textbf{Paragraph 1, the model.} Every pedal of \cref{sec:pedal-wiring} is a passive network between three terminals. Any such network is externally equivalent to three resistors meeting in one inner node, the star point \cite{kennelly1899equivalence}, as drawn in \cref{fig:star-network}. Define the term \emph{arm}: the resistance between one contact and the star point, written $r_\mathrm{T}$, $r_\mathrm{R}$ and $r_\mathrm{S}$ for tip, ring and sleeve. Use \enquote{arm} throughout, never \enquote{branch} or \enquote{leg}. State that the internal topology cannot be recovered from the terminals, only this equivalent \cite{borcea2012resistor}; the star form is chosen over the triangle form because, with one terminal open, a pair resistance is simply the sum of two arms.
}

\begin{figure}[htbp]
  \centering
  
  \titledcaption{Star Network Model}{\scaffoldinline{Say that A, B and C are the three arms meeting in the star point and TAP1 to TAP3 the accessible contacts. Consider redrawing with the labels of the text ($r_\mathrm{T}$, $r_\mathrm{R}$, $r_\mathrm{S}$; tip, ring, sleeve), so that figure and text use one notation.}}
  \label{fig:star-network}
\end{figure}

\scaffold{
  \textbf{Paragraph 2, what the arms mean.} Translate the pedal types into arm values: a potentiometer is the case with exactly one arm near \qty{0}{\ohm}, the wiper, while the other two arms hold the two track sections; the ratio of these two is the position. A wiper resting on a track end additionally shorts that end to the star point (end stop). A two-wire pedal has an isolated arm. Conclude: identifying a pedal reduces to solving for three arm resistances and asking which are near zero or isolated.
}

\scaffold{
  \textbf{Paragraph 3, representation.} The solver reports the arms as relative values $q_i = r_i / R_\mathrm{tot}$ (summing to one) plus the total $R_\mathrm{tot} = \sum_i r_i$, because the ratios are measured far more precisely than the total (\cref{sec:pair-measurement}). Special values use the IEEE~754 encoding: $0$ for an arm shorted to the star point, $\infty$ for an isolated arm, NaN for an arm that is finite but cannot be separated from its partner, which happens when only two contacts are connected. Mention that this keeps the arithmetic closed, so no special cases propagate through the code.
}

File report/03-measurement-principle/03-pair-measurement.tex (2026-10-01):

% !TEX root = ../main.tex

\section{Pair Measurement}
\label{sec:pair-measurement}

\scaffold{
  \textbf{Paragraph 1, the drive states.} The star point is not accessible, so the arms have to be inferred from the contacts. Every contact can be connected to a pull-up resistor to the high rail, to a pull-down resistor to the low rail, or left floating, and every contact is read by the ADC (\cref{fig:pull-matrix}). Define the term \emph{reading}: one settled ADC result of one contact; its cost in time follows in \cref{sec:conversion}. Define the term \emph{drive} (high, low, floating) and the term \emph{pull resistance} $R_\mathrm{p}$; on this board $R_\mathrm{p} = \qty{1}{\kilo\ohm}$ for both rails. Define \emph{rail voltages} $V_{\mathrm{H},i}$ and $V_{\mathrm{L},i}$: what contact $i$ reads when it is driven high or low while no current flows. They are measured, not assumed, by driving all three arms to the same rail and averaging eight readings per arm; this cancels the offset of the ADC and the voltage drops of the switches.
}

\begin{figure}[htbp]
  \centering
  
  \titledcaption{Pull Matrix}{\scaffoldinline{Explain the three switch columns per contact (to the high rail, to the low rail, each controlled by the microcontroller), the series resistor at each contact and the ADC channel per contact. The highlighted example drives contact 2 high and contact 3 low while contact 1 floats. Note that the figure labels the rails AVCC and AVDD; in the text they are the high and low rail.}}
  \label{fig:pull-matrix}
\end{figure}

\scaffold{
  \textbf{Paragraph 2, one pair.} A \emph{pair measurement} drives one arm $h$ high and one arm $l$ low and leaves the third arm $f$ floating, then reads all three contacts. The floating contact carries no current, so it reads the star point voltage. Present \cref{eq:currents,eq:pair-resistance,eq:low-fraction} in this order and explain each in one sentence: the loop current seen on the high and on the low side, the resistance of the pair, and the share of the pair held by the low arm. Point out that \cref{eq:low-fraction} uses voltages only, which span most of the rail, while \cref{eq:currents} relies on the small drops across the pull resistors; this is why ratios are precise and the total is not.
}

\begin{align}
  I_\mathrm{H} &= \frac{V_{\mathrm{H},h} - V_h}{R_\mathrm{p}},
  \qquad
  I_\mathrm{L} = \frac{V_l - V_{\mathrm{L},l}}{R_\mathrm{p}},
  \qquad
  I = \frac{I_\mathrm{H} + I_\mathrm{L}}{2}
  \label{eq:currents} \\
  R_{hl} &= r_h + r_l = \frac{V_h - V_l}{I}
  \label{eq:pair-resistance} \\
  \rho_{hl} &= \frac{V_f - V_l}{V_h - V_l} = \frac{r_l}{r_h + r_l}
  \label{eq:low-fraction}
\end{align}

\scaffold{
  \textbf{Paragraph 3, consistency and conduction.} $I_\mathrm{H}$ and $I_\mathrm{L}$ are two readings of the same loop current, so their difference is a free consistency check: a pedal moved during the measurement, or an unsettled contact, shows up as disagreement. A pair conducts only if both driven arms are finite; an isolated arm leaves $I$ at zero within the noise. Refer forward to \cref{sec:tolerances} for the thresholds of both checks.
}

\scaffold{
  \textbf{Paragraph 4, worked example.} Walk through \cref{fig:topology-sim-pairs}: the simulator of milestone~2 \cite{benson2026topologysim} with arms of 100, 200 and \qty{300}{\kilo\ohm} and \qty{1}{\kilo\ohm} pulls. In (a), the first pair puts the floating contact at \qty{1.66}{\volt}, i.e. 67\,\% of the span; in (b) the second pair puts it at \qty{1.87}{\volt}, 75\,\%. Compute both ratios with \cref{eq:low-fraction} to show the reader the arithmetic once. Mention that the simulator assumes a \qty{2.5}{\volt} rail.
}

\begin{figure}[htbp]
  \centering
  \begin{subfigure}[t]{0.49\linewidth}
    \centering
    
    \caption{First Pair}
    \label{fig:topology-sim-first-pair}
  \end{subfigure}%
  \hfill%
  \begin{subfigure}[t]{0.49\linewidth}
    \centering
    
    \caption{Second Pair}
    \label{fig:topology-sim-second-pair}
  \end{subfigure}
  \titledcaption{Pair Measurements in the Simulator}{\scaffoldinline{State the network (R1 \qty{100}{\kilo\ohm}, R2 \qty{200}{\kilo\ohm}, R3 \qty{300}{\kilo\ohm}), mark which contact is pulled up (red) and down (blue) in (a) and (b), and read off the floating contact voltage in each. Screenshots of \cite{benson2026topologysim}; verify that the arm labels match the text before use.}}
  \label{fig:topology-sim-pairs}
\end{figure}

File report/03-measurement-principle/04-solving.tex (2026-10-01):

% !TEX root = ../main.tex

\section{Solving the Network}
\label{sec:solving}

\scaffold{
  \textbf{Paragraph 1, the sequence.} Define the term \emph{solve}: the sequence of pair measurements that determines all three arms, and its result. One pair yields two independent numbers (a ratio and a resistance), the network has three unknowns, so at least two pairs are needed. The solver measures the pairs (tip high, ring low), (tip high, sleeve low) and, only if needed, (ring high, sleeve low). The first two share the tip, so only the low side has to be switched between them. The third pair is needed when neither of the first two conducts (an isolated tip and an empty plug look the same to them) or when the shared arm is too close to \qty{0}{\ohm} (paragraph 3).
}

\scaffold{
  \textbf{Paragraph 2, ratios through a shared arm.} Two pairs that share arm $s$, one with arm $a$ and one with arm $b$, give the shares $\sigma_1 = r_s/(r_s + r_a)$ and $\sigma_2 = r_s/(r_s + r_b)$ from \cref{eq:low-fraction}. Present \cref{eq:ratios}: the three unnormalized ratios $x_i$ and the relative arms $q_i$. Derive in one step that each $x_i$ is proportional to $r_i$ with the common factor in \cref{eq:conditioning}, so the normalization recovers the arms exactly.
}

\begin{align}
  x_s &= \sigma_1 \sigma_2, \qquad
  x_a = (1 - \sigma_1)\,\sigma_2, \qquad
  x_b = (1 - \sigma_2)\,\sigma_1, \qquad
  q_i = \frac{x_i}{\sum_j x_j}
  \label{eq:ratios} \\
  c &= \sum_j x_j = \frac{r_s\,(r_s + r_a + r_b)}{(r_s + r_a)(r_s + r_b)}
  \label{eq:conditioning}
\end{align}

\scaffold{
  \textbf{Paragraph 3, conditioning.} Define the \emph{conditioning} $c$ of \cref{eq:conditioning}: it lies between 0 and 1 and approaches 0 as the shared arm approaches \qty{0}{\ohm}, because both pairs then only say \enquote{everything is in the other arm}. Noise in the ratios is amplified roughly by $1/c$. This is exactly the case of a potentiometer whose wiper is the tip: with a contact resistance $t$ of the wiper, $c \approx t/((t + r)(t + s))$ in relative terms. Below a minimum conditioning of 0.5 the solver measures the third pair and takes the better conditioned of its two combinations. Refer to \cref{sec:update-rate}, where a threshold of 0.05 let a pedal with a \qty{1.5}{\percent} wiper pass and its position jitter by \num{4880} instead of \num{274} parts per million.
}

\scaffold{
  \textbf{Paragraph 4, the total.} Each conducting pair $k$ implies a total $R_{\mathrm{tot},k} = R_{hl,k} / (q_h + q_l)$. The solver combines them weighted with their squared signal-to-noise ratio $I_k^2/\operatorname{Var}(I_k)$ (\cref{eq:total}). The pairs must agree on the total within their noise; a pedal moved between two pairs does not, and the solve is rejected and repeated.
}

\begin{equation}
  R_\mathrm{tot} = \frac{\sum_k w_k R_{\mathrm{tot},k}}{\sum_k w_k},
  \qquad
  w_k = \frac{I_k^2}{\operatorname{Var}(I_k)}
  \label{eq:total}
\end{equation}

\scaffold{
  \textbf{Paragraph 5, degenerate networks.} A pair whose resistance is below \qty{50}{\ohm} is a short: if both of the first pairs are shorts, every arm is 0; if one is, the remaining arm holds the whole resistance. If exactly one pair conducts, the third arm is isolated and the two conducting arms are either both shorted or only known as a sum (NaN, \cref{sec:star-network}). If no pair conducts, the network is disconnected. This covers every case of \cref{tab:pedal-networks}.
}

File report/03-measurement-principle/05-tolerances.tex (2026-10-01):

% !TEX root = ../main.tex

\section{Tolerances from the ADC Noise}
\label{sec:tolerances}

\scaffold{
  \textbf{Paragraph 1, the principle.} Every threshold of the solver is expressed in standard deviations of the noise of a single ADC reading, $\sigma_V$, propagated to the quantity that is checked: a current read across $R_\mathrm{p}$ has $\operatorname{Var}(I_\mathrm{H}) = (\sigma_V / R_\mathrm{p})^2$, the averaged current a quarter of the sum of both sides. Consequence: a high-value pedal, whose small currents are noisy, gets proportionally wider tolerances instead of being rejected, and adapting the solver to another front end only requires its $\sigma_V$. On this board $\sigma_V = \qty{0.5}{\milli\volt}$ at the chosen update rate (\cref{sec:update-rate}). Note the history: the first version used exact-arithmetic thresholds from the simulator ($10^{-9}$) that rejected every real measurement.
}

\scaffold{
  \textbf{Paragraph 2, the thresholds.} Present \cref{tab:solver-tolerances} and comment on the two that matter most: the conduction threshold of $3\sigma$ decides the largest pair resistance still distinguishable from an open circuit, and the minimum conditioning (\cref{sec:solving}) decides when a third pair is measured. Compute once what the conduction threshold means in resistance for $R_\mathrm{p} = \qty{1}{\kilo\ohm}$ and a \qty{2.5}{\volt} rail.
}

\begin{table}[htbp]
  \centering
  \titledcaption{Solver Tolerances}{\scaffoldinline{Say that $\sigma$ is the noise of the checked quantity derived from $\sigma_V$, that a check passes if either the noise criterion or the relative criterion holds, and give the source (\code{SolverConfig::from\_voltage\_noise} in \code{topology/src/config.rs}).}}
  \label{tab:solver-tolerances}
  \begin{tabular}{@{}lll@{}}
    \toprule
    \textbf{Check} & \textbf{Noise criterion} & \textbf{Relative criterion} \\
    \midrule
    Pair conducts & $I > 3\sigma_I$ & -- \\
    High and low current agree & $5\sigma$ & \qty{10}{\percent} of $I$ \\
    Pair totals agree & $4\sigma$ & \qty{10}{\percent} of $R_\mathrm{tot}$ \\
    Pair is a short & -- & $R_{hl} < \qty{50}{\ohm}$ \\
    Ratio is defined & $V_h - V_l > 10\sigma_V$ & -- \\
    Two pairs suffice & -- & conditioning $c \geq 0.5$ \\
    \bottomrule
  \end{tabular}
\end{table}

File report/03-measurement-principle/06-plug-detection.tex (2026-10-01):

% !TEX root = ../main.tex

\section{Plug Detection}
\label{sec:plug-detection}

\scaffold{
  \textbf{Paragraph 1, why a separate check.} A solve cannot tell an empty jack from a plugged cable with nothing conducting behind it, since both leave every pair open. The jacks have a fourth contact for this: the \emph{tip switch}, a normalling contact that touches the tip while no plug is inserted and is lifted by the plug \cite{neutrik2026nmj6hfd2}. Use the term \enquote{tip switch} throughout, never \enquote{normalling contact} after its definition.
}

\scaffold{
  \textbf{Paragraph 2, the check.} The \emph{plug check} drives the tip low and the tip switch high and leaves ring and sleeve floating. Without a plug the two pulls form a divider and the tip switch reads half the rail span, \qty{1.25}{\volt}; with a plug it is isolated and reads its own rail, \qty{2.5}{\volt}. A plug is assumed above three quarters of the span (\cref{eq:plug-threshold}). Explain why the check is independent of the pedal: ring and sleeve float, so no current flows through the pedal whatever its wiring, position or end stop, including a wiper on the tip. It costs one reading plus the re-settling of whatever the jack was driven with before.
}

\begin{equation}
  V_\mathrm{TS} > V_{\mathrm{L},\mathrm{TS}} + 0.75\,\bigl(V_{\mathrm{H},\mathrm{TS}} - V_{\mathrm{L},\mathrm{TS}}\bigr)
  \label{eq:plug-threshold}
\end{equation}

\scaffold{
  \textbf{Paragraph 3, origin of the fourth contact.} One sentence for the reader: the board switches four contacts per jack because the switch ICs have four channels, and the spare channel was put on the tip switch (author's statement in the final presentation); the use for plug detection followed from that. Refer to \cref{sec:design-history}.
}

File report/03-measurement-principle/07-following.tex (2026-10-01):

% !TEX root = ../main.tex

\section{Following an Identified Pedal}
\label{sec:following}

\scaffold{
  \textbf{Paragraph 1, why following.} A full solve takes two or three pairs of three readings each. For an identified potentiometer, a single reading suffices: once the wiper and the track ends are known, the track ends are driven and only the wiper is read. The wiper then carries no current, so its contact resistance does not enter the position. Present \cref{eq:position}, with $V_\mathrm{s}$ and $V_\mathrm{e}$ the readings of the track start and end. Leave the timing argument (why this is necessary) to \cref{sec:update-rate}.
}

\begin{equation}
  p = \frac{V_\mathrm{w} - V_\mathrm{s}}{V_\mathrm{e} - V_\mathrm{s}}, \qquad 0 \leq p \leq 1
  \label{eq:position}
\end{equation}

\scaffold{
  \textbf{Paragraph 2, position convention.} The track start is the sleeve whenever the sleeve is a track end, otherwise the lower-numbered end. With this, the position rises as the wiper moves away from the sleeve, which matches both common wirings of \cref{fig:pedal-wirings}. Mention that the first firmware counted from the lower-numbered end and read the tip-wiper test pedal backwards.
}

\scaffold{
  \textbf{Paragraph 3, classification.} After a solve, the arms decide what follows. Walk through the classes in the order they are checked, with their thresholds relative to $R_\mathrm{tot}$:
  \emph{potentiometer} (every arm resolved, exactly one within \qty{25}{\percent}: the wiper);
  \emph{end stop} (two arms within \qty{2}{\percent}: the wiper rests on a track end);
  \emph{near end} (the second-lowest arm also within \qty{25}{\percent});
  \emph{tip-sleeve element} (a switch or rheostat behind a mono or stereo plug, \cref{tab:pedal-networks});
  \emph{disconnected}; and \emph{other} for any remaining network, such as a dual footswitch.
  Explain the ambiguity of end stop and near end: a clean wiper a little way along the track and a wiper with resistance in its own lead resting on that end are the same network at opposite positions; only the ring-sleeve end stop changes the position. The wiper is then taken from, in this order, the per-jack wiper setting, the wiper remembered for the jack, and the arm nearer the star point unless that is the sleeve. Refer to \cref{sec:pedal-types} for the pedal that required the \qty{25}{\percent} limit.
}

\scaffold{
  \textbf{Paragraph 4, checks while following a potentiometer.} Every \qty{25}{\milli\second} one track end is read instead of the wiper, alternating. Its drop across the pull resistor must stay within $6\sigma$ or \qty{3}{\percent} of the reference (\qty{25}{\percent} on the very first reading, because solves of a pedal on an end stop were seen up to \qty{10}{\percent} off). The wiper must stay within the span of the ends, with $6\sigma$ plus \qty{0.5}{\percent} of the span as margin (a pedal read its wiper up to \qty{7}{\milli\volt} past the end it rested on). A violation means the pedal was unplugged, rewired, or its wiper guessed wrong, and the jack is identified again.
}

\scaffold{
  \textbf{Paragraph 5, switches and rheostats.} A tip-sleeve element is followed with one reading as well: tip high, sleeve low, tip read; the resistance follows from the tip's pull drop. At most \qty{0.2}{\kilo\ohm} reads as a closed switch (value 1), no current as open (value 0); three consecutive readings in between make it a rheostat, whose resistance is scaled to the smallest standard pedal value (1, 2.5, 5, 10, 25 \ldots\ \qty{1000}{\kilo\ohm}) it fits within \qty{25}{\percent}. A plug check every \qty{50}{\milli\second} and a ring check every \qty{100}{\milli\second} confirm the plug is still there and the ring still wired as identified; the ring check allows \qty{1}{\percent} of the sleeve's drop on top of $6\sigma$ because the two pull paths differ by a few ohms. State the two known limitations: a mono cable without a pedal reads as a released switch, and a rheostat behind a mono plug first reads as a potentiometer on its end stop until its resistance has changed by \qty{20}{\percent}.
}

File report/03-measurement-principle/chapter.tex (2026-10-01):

% !TEX root = ../main.tex

\chapter{Measurement Principle}
\label{ch:measurement-principle}

\scaffold{
  Chapter purpose: the theory the implementation rests on, independent of the concrete chips. The reader knows from \cref{ch:introduction} that the wiring of a pedal is unknown and from \cref{sec:related-component-identification} that component testers drive pins through resistors. By the end of the chapter the reader can compute the arm resistances of any pedal from three contact voltages per drive pair, knows why every tolerance is a multiple of the ADC noise, and knows how a plug is detected and an identified pedal is followed. Values of the board (\qty{1}{\kilo\ohm}, \qty{2.5}{\volt}) appear only as examples; the board itself follows in \cref{ch:implementation}.
}

\input{03-measurement-principle/01-pedal-wiring}
\input{03-measurement-principle/02-star-network}
\input{03-measurement-principle/03-pair-measurement}
\input{03-measurement-principle/04-solving}
\input{03-measurement-principle/05-tolerances}
\input{03-measurement-principle/06-plug-detection}
\input{03-measurement-principle/07-following}

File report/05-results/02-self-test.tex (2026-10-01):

% !TEX root = ../main.tex

\section{Board Self-Test}
\label{sec:results-self-test}

\scaffold{
  \textbf{Paragraph 1, procedure.} The self-test program reads the grounded input AIN6 and the reference input AIN10 of both ADCs, then pulls every contact of every jack up and down in turn with all jacks empty and checks that exactly the ADC input that \code{board.rs} assigns to that contact follows: 4 jacks $\times$ 4 contacts $\times$ 2 polarities = 32 checks, plus the check that the tip switch follows the tip while no plug is inserted. Both ADCs convert in parallel; the whole test takes \qty{1.26}{\second}.
}

\scaffold{
  \textbf{Paragraph 2, result.} On its first run on the assembled board, every contact read \qty{2.50}{\volt} pulled up and \qty{0.0}{\volt} pulled down on exactly the expected input, which confirms switch polarity, the order of the shift-register chain and the bit mapping; the grounded inputs read \qty{0.0}{\volt} and the reference inputs \qty{2.50}{\volt}. (At that time the jacks were not yet soldered, so the tip-switch check was repeated afterwards and passed.) Present the result as \cref{tab:self-test}. Conclude in one sentence that wiring, switches, shift registers and both ADCs work as designed, which every later measurement rests on.
}

\begin{table}[htbp]
  \centering
  \titledcaption{Self-Test Result}{\scaffoldinline{Explain rows and columns and that \enquote{pass} means only the expected input followed. Fill in from a fresh run of \code{cargo run --bin detect\_pin\_mapping} with the jacks unplugged; the numbers shown are from the log of the first run.}}
  \label{tab:self-test}
  \begin{tabular}{@{}lcccc@{}}
    \toprule
    & \textbf{Tip} & \textbf{Ring} & \textbf{Sleeve} & \textbf{Tip switch} \\
    \midrule
    Jack 1 (J5) & pass & pass & pass & pass \\
    Jack 2 (J4) & pass & pass & pass & pass \\
    Jack 3 (J3) & pass & pass & pass & pass \\
    Jack 4 (J2) & pass & pass & pass & pass \\
    \midrule
    \multicolumn{5}{@{}l}{Grounded input AIN6: \qty{0.0}{\volt} on both ADCs; reference input AIN10: \qty{2.50}{\volt}} \\
    \bottomrule
  \end{tabular}
\end{table}

\openquestion{Self-test log}{
  The table is reconstructed from a development session. Rerun the self-test on the final firmware and fill in the measured values (pulled-up and pulled-down voltage per contact, AIN6 and AIN10 per ADC).
}

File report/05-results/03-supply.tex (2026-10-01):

% !TEX root = ../main.tex

\section{Supply Rail Ripple}
\label{sec:results-supply}

\scaffold{
  \textbf{Paragraph 1, setup.} The ripple of the input (VEXT, TP15) and the three rails (TP12--TP14) was measured AC-coupled at 1X in four operating states: without microcontroller, idle or detecting, following a pedal, and following with WiFi active. Per rail and state, the RMS value averaged over 70 to 1000 acquisitions at \qty{10}{\milli\second}/div (high-resolution mode) is reported; captures at \qty{1}{\micro\second}/div reached the oscilloscope's own noise at every rail and are not shown. The noise floor of the oscilloscope, \qty{0.34}{\milli\volt} RMS, was taken under the same settings. The values were read from the oscilloscope's statistics by a script and checked by hand.
}

\scaffold{
  \textbf{Paragraph 2, the limit.} Derive the ripple that would just disturb a stable 7-bit value, drawn in \cref{fig:supply-ripple}: one MIDI step of the \qty{2.5}{\volt} reference is $\qty{2.5}{\volt}/128 = \qty{19.5}{\milli\volt}$, and requiring $\pm 3\sigma$ of Gaussian noise to fit into one step gives $\qty{19.5}{\milli\volt}/6 = \qty{3.26}{\milli\volt}$ RMS. Use the same step as \cref{sec:results-position} (1/127 of the span); the plot divides by 128, a difference below \qty{1}{\percent} that should still be made consistent in \code{create\_plots.py}. One sentence on why this is conservative: the reading is ratiometric, so ripple common to the pull rail and the reference cancels further.
}

\begin{figure}[htbp]
  \centering
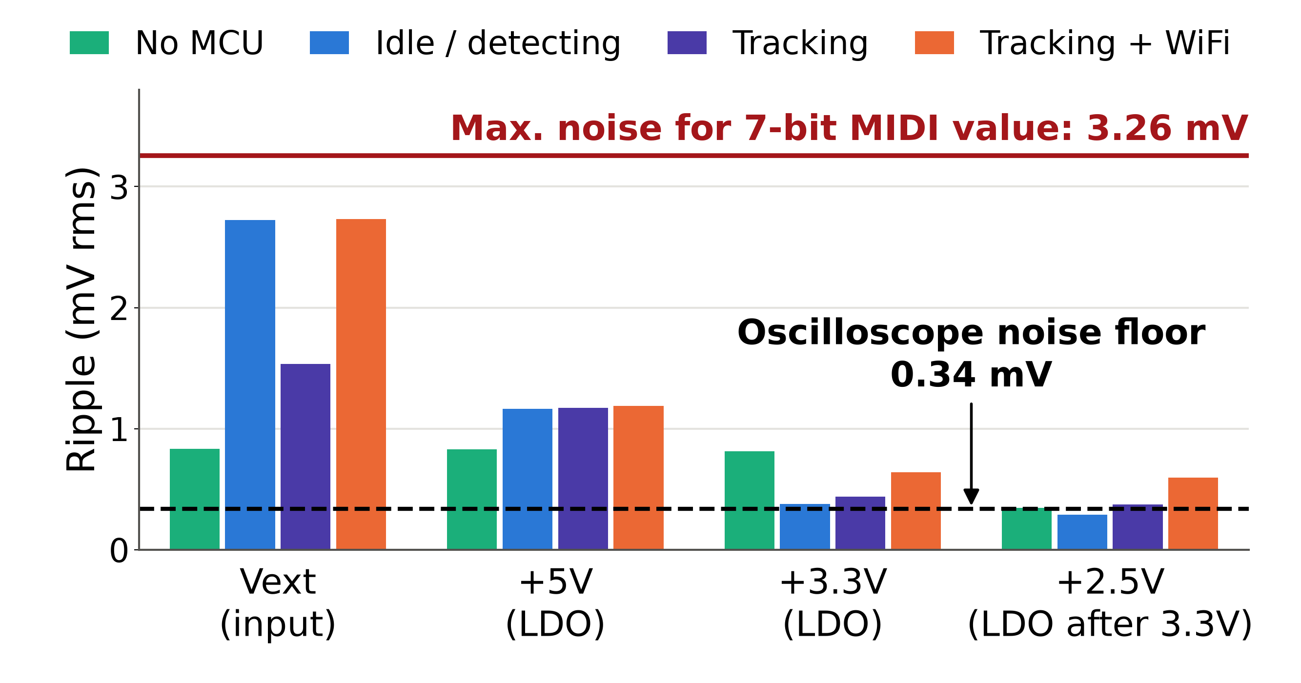
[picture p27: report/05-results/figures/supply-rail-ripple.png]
  
  \titledcaption{Supply Rail Ripple}{\scaffoldinline{State the conditions (AC coupling, 1X probe, \qty{10}{\milli\second}/div, RMS average), name the four operating states, the oscilloscope noise floor and the limit for a stable 7-bit value. Rails are ordered along the regulator chain. Source: \code{measurements/create\_plots.py}, data \code{measurements/supply\_rail\_measurement.xlsx}.}}
  \label{fig:supply-ripple}
\end{figure}

\scaffold{
  \textbf{Paragraph 3, what the data shows.} The input ripple rises from \qty{0.83}{\milli\volt} without microcontroller to about \qty{2.7}{\milli\volt} RMS once the microcontroller runs; read the exact values per state from the plot, which shows the state \enquote{idle / detecting} as high as \enquote{tracking + WiFi} and \enquote{tracking} lower, and explain or flag this. Every regulator stage lowers it, and the \qty{3.3}{\volt} and \qty{2.5}{\volt} rails stay between 0.3 and \qty{0.6}{\milli\volt}, at or just above the noise floor, so their exact values are not meaningful. WiFi is the only state that visibly raises them. The \qty{5}{\volt} rail shows about \qty{1.2}{\milli\volt} RMS but about \qty{16}{\milli\volt} peak-to-peak once the microcontroller runs, i.e. short spikes rather than broadband noise. Every rail stays below the \qty{3.26}{\milli\volt} limit; the \qty{2.5}{\volt} rail by a factor of about five even with WiFi.
}

\openquestion{Supply data quality}{
  Three readings without microcontroller (VEXT, \qty{5}{\volt}, \qty{3.3}{\volt}) were taken without resetting the oscilloscope statistics between rails, which makes the \qty{3.3}{\volt} rail look worse without the microcontroller than with it. Decide whether to remeasure, mark or drop them. Confirm that the noise floor capture (image~2) was taken with the probe tip on the ground pad, and give the cause of the spikes on the \qty{5}{\volt} rail if known (suspected: the switching regulator of the Pico module).
}

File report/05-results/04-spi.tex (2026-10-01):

% !TEX root = ../main.tex

\section{SPI Signal Integrity}
\label{sec:results-spi}

\scaffold{
  \textbf{Paragraph 1, timing and content.} Captures of SPI0 at TP5--TP9 show a clock of \qty{3.95}{\mega\hertz} (the system clock of \qty{150}{\mega\hertz} divided by 38 for the requested \qty{4}{\mega\hertz}), SPI mode~0, and chip-select guards of \qty{9.8}{\micro\second} and \qty{11.45}{\micro\second} for the configured \qty{10}{\micro\second}. One data-register read takes \qty{30.65}{\micro\second} with the chip selected, of which \qty{9.4}{\micro\second} is clocking; decoding the bits gives the read command \code{0x44} followed by a 24-bit result. State that the guards dominate a transaction but are negligible against the \qty{4}{\milli\second} conversion time of a reading.
}

\scaffold{
  \textbf{Paragraph 2, edges.} \Cref{fig:spi-edges} shows clock and data edges captured at 10X: rise times of \qty{10.2}{\nano\second} (clock) and \qty{11.2}{\nano\second} (data), fall time \qty{8.4}{\nano\second}, overshoot within one oscilloscope step (\qty{40}{\milli\volt}), no ringing. The data line changes on the falling clock edge and is sampled on the rising one, so it is stable for about \qty{127}{\nano\second} on either side; a \qty{10}{\nano\second} edge uses about \qty{8}{\percent} of the half period. The edges are slowed on purpose by the \qty{47}{\ohm} series resistors. Two notes for honesty: the first capture at 1X showed edges of 24 to \qty{27}{\nano\second}, which was the probe's load; and the 10X capture was averaged, which supports \enquote{no ringing} but says nothing about one-off glitches.
}

\begin{figure}[htbp]
  \centering
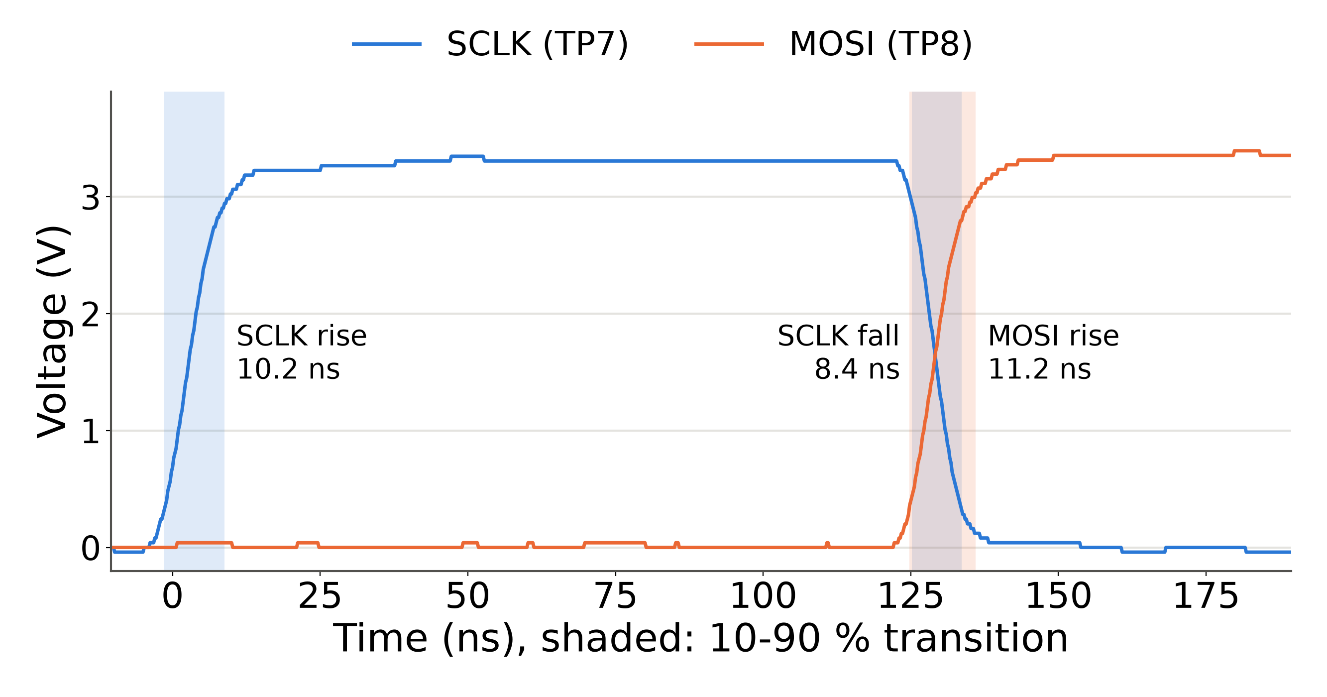
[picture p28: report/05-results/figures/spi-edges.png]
  
  \titledcaption{SPI Edges}{\scaffoldinline{State conditions (10X probes, SCLK at TP7, MOSI at TP8, averaged capture) and that the shaded bands are the 10 to \qty{90}{\percent} transitions with their durations. Source: \code{measurements/create\_plots.py}, data \code{spi\_edges\_rise.csv}.}}
  \label{fig:spi-edges}
\end{figure}

\scaffold{
  \textbf{Paragraph 3, error-free transfer.} Firmware-side check: at \qty{4}{\mega\hertz} with a \qty{10}{\micro\second} guard, 300 consecutive readings contained no outlying code (more than six robust standard deviations from the median), where the breadboard had produced flipped bits at \qty{4}{\mega\hertz} and needed \qty{50}{\micro\second}.
}

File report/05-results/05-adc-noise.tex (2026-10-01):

% !TEX root = ../main.tex

\section{ADC Noise on the PCB}
\label{sec:results-adc-noise}

\scaffold{
  \textbf{Paragraph 1, setup.} The capture program held every contact in one drive state (pulled low, pulled high, or floating) and recorded all inputs for \qty{30}{\second} at \qty{315}{\hertz}, bipolar coding; this was the first measurement on the assembled board, before the operating point of \cref{sec:update-rate} was chosen. Present \cref{tab:adc-noise}.
}

\begin{table}[htbp]
  \centering
  \titledcaption{ADC Noise on the Empty Board}{\scaffoldinline{State conditions (\qty{315}{\hertz}, \qty{30}{\second} per state, all jacks empty) and that ranges span the inputs of both ADCs.}}
  \label{tab:adc-noise}
  \begin{tabular}{@{}llll@{}}
    \toprule
    \textbf{Input} & \textbf{Mean} & \textbf{Noise ($\sigma$)} & \textbf{Drift in \qty{30}{\second}} \\
    \midrule
    Contacts pulled low & \qty{+1.3}{\milli\volt} / \qty{+1.5}{\milli\volt} & 15 to \qty{23}{\micro\volt} & $\leq \qty{0.04}{\milli\volt}$ \\
    Contacts pulled high & \qtyrange{2.4998}{2.5001}{\volt} & 50 to \qty{60}{\micro\volt} & $\leq \qty{0.16}{\milli\volt}$ \\
    Grounded input AIN6 & \qty{+1.3}{\milli\volt} / \qty{+1.5}{\milli\volt} & 15 to \qty{21}{\micro\volt} & none \\
    Reference input AIN10 & \qtyrange{2.4999}{2.5000}{\volt} & 55 to \qty{85}{\micro\volt} & $\leq \qty{0.17}{\milli\volt}$ \\
    \bottomrule
  \end{tabular}
\end{table}

\scaffold{
  \textbf{Paragraph 2, what it shows.} The noise is about \qty{20}{\micro\volt} near ground and about \qty{55}{\micro\volt} near the rail; the part that grows with the voltage most likely comes from the reference and cancels in the ratiometric reading. The constant offset of about \qty{1.4}{\milli\volt} appears on the grounded input as well, so it belongs to the ADC, not to the switches, and the measured rails of \cref{sec:pair-measurement} compensate it. Floating inputs drift by tenths of a volt, charged by about \qty{0.2}{\nano\ampere} to \qty{0.5}{\nano\ampere} of leakage into the filter capacitors, which through a pedal of \qty{100}{\kilo\ohm} or less amounts to less than \qty{50}{\micro\volt}. Compare with the breadboard (about \qty{1}{\milli\volt}) in half a sentence.
}

\scaffold{
  \textbf{Paragraph 3, with a pedal.} With the \qty{10.85}{\kilo\ohm} pedal reproducing the three solver pairs, driven contacts read 0.03 to \qty{0.12}{\milli\volt} and the floating contact up to \qty{0.36}{\milli\volt} where it reads the wiper directly, part of it slow wander attributed to the wiper contact. This set the solver's noise figure first to \qty{0.4}{\milli\volt} at \qty{315}{\hertz}, later to \qty{0.5}{\milli\volt} at \qty{819}{\hertz} (\cref{tab:adc-characterization}).
}

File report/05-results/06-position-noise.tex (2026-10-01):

% !TEX root = ../main.tex

\section{Position Noise and Accuracy}
\label{sec:results-position}

\scaffold{
  \textbf{Paragraph 1, position noise.} With the \qty{10.85}{\kilo\ohm} pedal held still, the position solved at \qty{819}{\hertz} has a standard deviation of \num{274} parts per million of travel (\cref{tab:conditioning-fix}). One MIDI step is $1/127$, \num{7874} parts per million, so the jitter is about 1/29 of a step, and the emitted 7-bit value does not change. In the following mode, where only the wiper is read, the single-reading noise of \num{203} parts per million (\cref{tab:adc-characterization}) applies. State the consequence plainly: the limit of the output resolution is the 7-bit MIDI value, not the measurement.
}

\begin{figure}[htbp]
  \centering
  \placeholderfigure{
    \textbf{Content.} (a) Histogram of a few thousand positions of a pedal held still in the following mode, x axis in parts per million of travel around the mean, with the width of one MIDI step (\num{7874} ppm) drawn on the same axis; (b) the emitted MIDI value over the same time, a flat line.
    \textbf{Focus.} The ratio between the width of the histogram and one MIDI step.
    \textbf{How to obtain.} Log the raw position of one jack over the debug probe (\code{defmt}) for about \qty{30}{\second} while the pedal is still, plot with \code{measurements/create\_plots.py}. This measurement (M3 of the measurement plan) has not been made yet.
  }
  \titledcaption{Position Noise}{\scaffoldinline{Conditions (pedal, position, rate, duration, number of samples) and the meaning of the drawn MIDI step.}}
  \label{fig:position-noise}
\end{figure}

\scaffold{
  \textbf{Paragraph 2, accuracy against known networks.} The milestone plan promised a sweep of precision resistors against the measured ratio and the identification of known static networks, including shorted and open arms. State what exists: the solver's arithmetic is verified against simulated networks by 25 host tests, including every short and open case; and the identified total of the test pedal was repeatable (\num{10.844} to \qty{10.850}{\kilo\ohm} over 300 solves); its agreement with an independent measurement, for example an ohmmeter across ring and sleeve, is not recorded. If the measurement with known resistors is made, present it here as measured against actual arm resistance with the relative error, and the error of the total against the total, with the prediction of \cref{tab:pull-resistance}.
}

\openquestion{Accuracy and linearity measurement}{
  No measurement with precision resistors or a decade box (identification of known networks, ratio sweep for linearity) is in the repository, although the milestone plan promised it. Was it made? If not, say so in the text and in \cref{sec:results-requirements}, with the reason. At least compare the identified totals of the real pedals with an ohmmeter reading.
}

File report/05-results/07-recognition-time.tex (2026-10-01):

% !TEX root = ../main.tex

\section{Recognition Time}
\label{sec:results-recognition}

\scaffold{
  \textbf{Paragraph 1, setup.} Channel~1 on the tip switch and channel~2 on the ring of one jack, 10X probes, trigger on the tip switch rising through \qty{1.9}{\volt} (the plug lifting it), \qty{500}{\milli\second} window, at least 1~million points. The drive pattern of the jack changes with every state, so the ring voltage shows the phases of the jack monitor directly: the latch edges of the shift register mark where one phase ends and the next begins. The switch into following is not visible, because following keeps the drives of the last pair; it is inferred as one pair length (\qty{14.6}{\milli\second}) after the last edge. Five plug-ins and three unplugs were captured.
}

\scaffold{
  \textbf{Paragraph 2, plug-in with fresh rails.} Walk through \cref{fig:plug-in-fresh} along its labelled phases: waiting for the next plug check, the three pairs (ring pulled low at \qty{0.28}{\volt}, floating at the star point, pulled high), then following. Present \cref{tab:plug-in}: the plug was noticed 4.9 to \qty{47.3}{\milli\second} after insertion, as expected from a check every \qty{50}{\milli\second}; identification took 44 to \qty{48}{\milli\second}; in total 65 to \qty{95}{\milli\second}. A pair sometimes takes \qty{18.8}{\milli\second} instead of \qty{14.7}{\milli\second}, one extra conversion for the plug check of the other jack on the same ADC. The first run is a useful edge case: the plug was noticed before it was fully seated, tip and ring were shorted, the first pair was rejected and repeated, and the result was still correct after \qty{65}{\milli\second}.
}

\begin{figure}[htbp]
  \centering
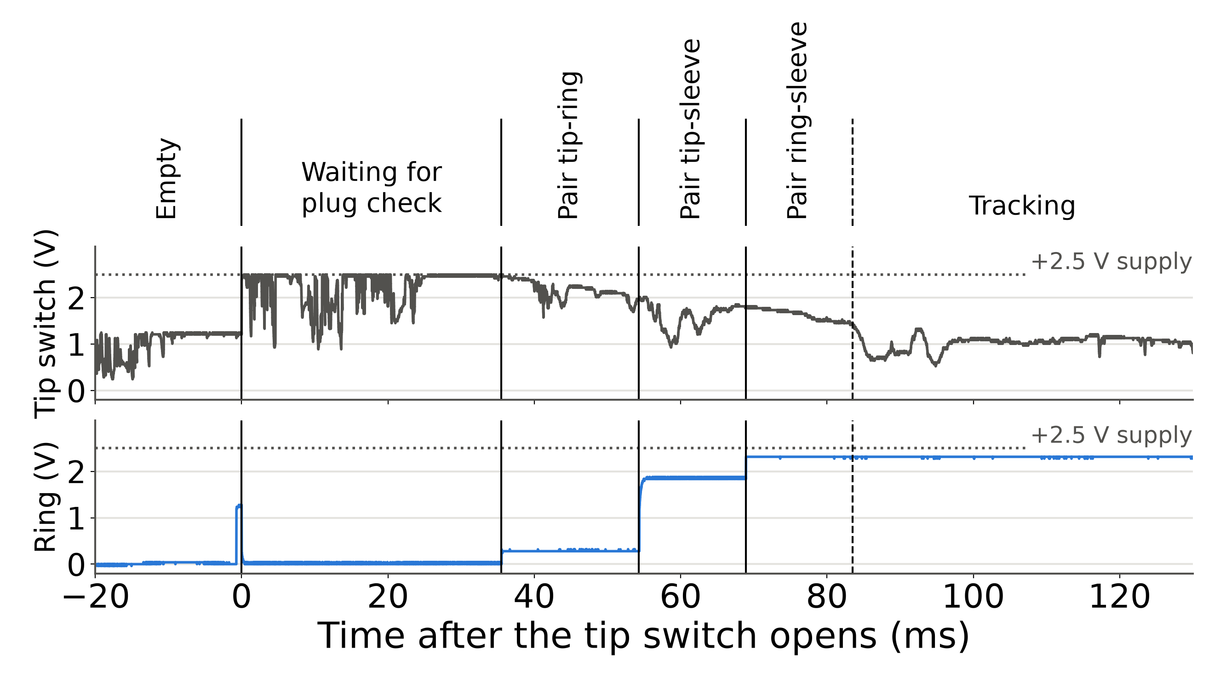
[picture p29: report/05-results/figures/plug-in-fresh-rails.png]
  
  \titledcaption{Plug-In with Fresh Rails}{\scaffoldinline{Conditions (tip switch and ring of jack~1, 10X, trigger on the tip switch at \qty{1.9}{\volt}, rails measured less than \qty{30}{\second} before); the vertical lines are latch edges, the dashed one is inferred. Capture \code{plugin5.csv}; source \code{measurements/create\_plots.py}.}}
  \label{fig:plug-in-fresh}
\end{figure}

\begin{table}[htbp]
  \centering
  \titledcaption{Plug-In Timing}{\scaffoldinline{Times in milliseconds after the tip switch opened, except the column \enquote{first pair}, which gives its duration; the start of following is inferred as the last latch plus one pair length.}}
  \label{tab:plug-in}
  \begin{tabular}{@{}lrrrr@{}}
    \toprule
    \textbf{Run} & \textbf{Plug noticed} & \textbf{First pair} & \textbf{Last latch} & \textbf{Following} \\
    \midrule
    1 & 4.9 & 31.2 (repeated) & 50.9 & $\approx$ 65 \\
    2 & 47.3 & 18.8 & 80.7 & $\approx$ 95 \\
    3 & 45.6 & 14.7 & 75.0 & $\approx$ 90 \\
    4 & 17.6 & 18.9 & 51.1 & $\approx$ 66 \\
    5 & 35.5 & 18.8 & 68.9 & $\approx$ 84 \\
    \midrule
    Rails older than \qty{30}{\second} & 49.4 & 14.7 & 292.7 & $\approx$ 300 \\
    \bottomrule
  \end{tabular}
\end{table}

\scaffold{
  \textbf{Paragraph 3, plug-in with a rail refresh.} The rails are re-measured before a solve if they are older than \qty{30}{\second}. \Cref{fig:plug-in-refresh} shows this worst case: the plug check came just before the insertion (\qty{49.4}{\milli\second} of waiting), the rails took \qty{213.8}{\milli\second} (48 readings of \qty{4.45}{\milli\second}, all arms high, then all low), and the pairs about \qty{30}{\milli\second} to \qty{44}{\milli\second}: about \qty{300}{\milli\second} in total. Mention that the pair voltages of this run differ from the other five because the wiper contact resistance changed between the pairs, and that the solver still accepted the result.
}

\begin{figure}[htbp]
  \centering
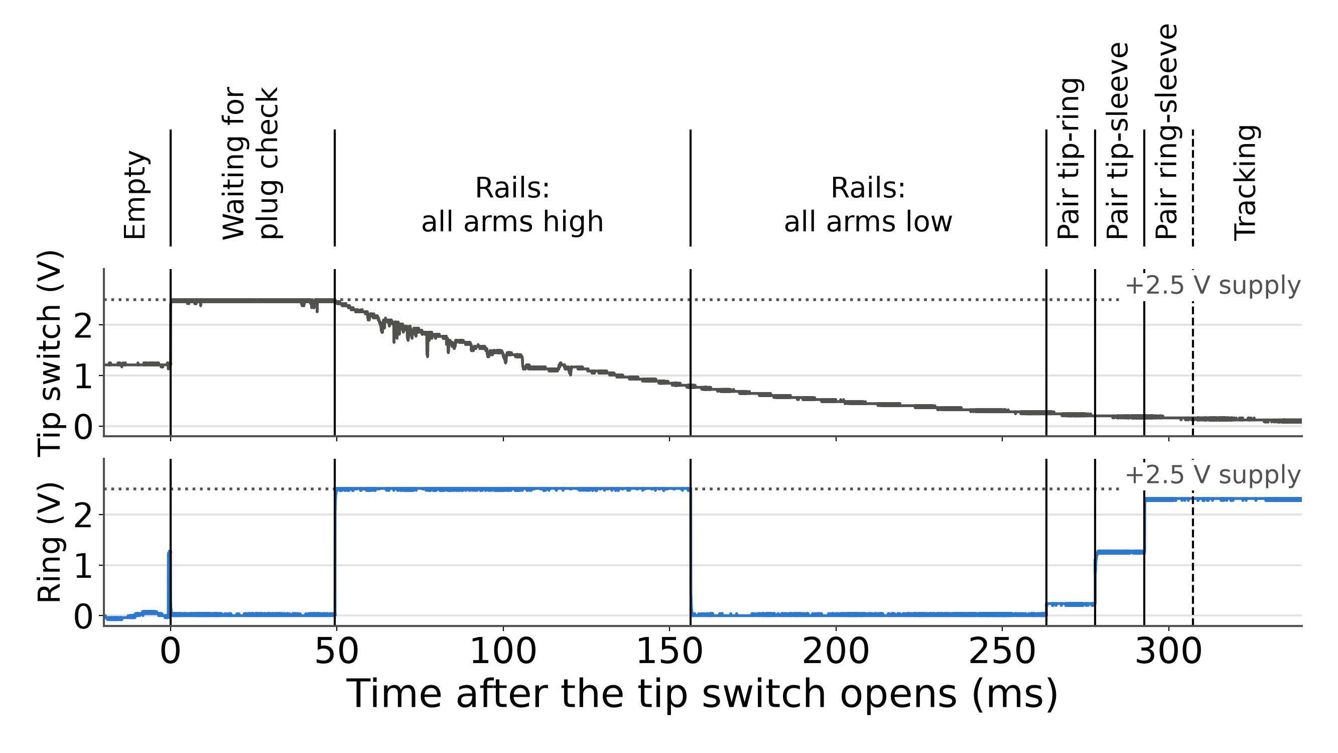
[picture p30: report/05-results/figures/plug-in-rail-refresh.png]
  
  \titledcaption{Plug-In with Rail Refresh}{\scaffoldinline{Same conditions as \cref{fig:plug-in-fresh}, but the rails were older than \qty{30}{\second}; name the two rail phases. Capture \code{plugin\_w\_rail\_meas.csv}.}}
  \label{fig:plug-in-refresh}
\end{figure}

\scaffold{
  \textbf{Paragraph 4, unplug.} \Cref{fig:unplug} (trigger on the tip switch closing): the ring loses the pedal's current about \qty{2}{\milli\second} before the tip switch closes; the firmware drops the pedal 2 to \qty{27}{\milli\second} later, re-measures the rails (about \qty{214}{\milli\second}, since the pedal had been followed for longer than \qty{30}{\second}), solves, finds no current, and the plug check reports the jack empty after 260, 330 and \qty{391}{\milli\second} in the three runs. In two of three runs a second solve was needed, because the first one saw a current just above the conduction threshold. Conclude that the rail refresh dominates both the worst-case plug-in and the unplug time.
}

\begin{figure}[htbp]
  \centering
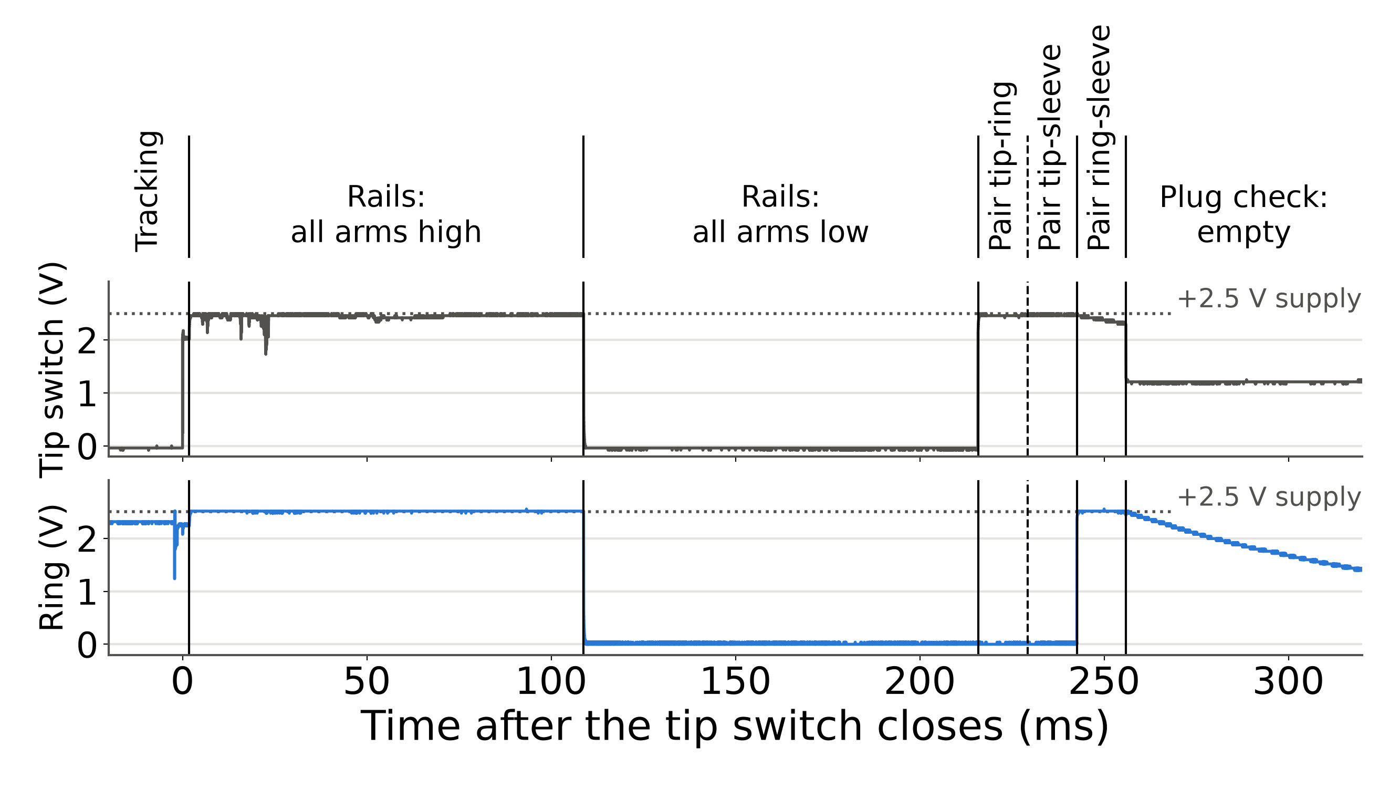
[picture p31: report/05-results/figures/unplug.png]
  
  \titledcaption{Unplug}{\scaffoldinline{Conditions (trigger on the tip switch closing); phases following, rails, three pairs, plug check; the dashed line is inferred. Capture \code{unplug1.csv}, the only run with a single solve.}}
  \label{fig:unplug}
\end{figure}

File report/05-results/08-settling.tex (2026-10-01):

% !TEX root = ../main.tex

\section{Settling of a Floating Contact}
\label{sec:results-settling}

\scaffold{
  \textbf{Paragraph 1, the model under test.} \Cref{eq:settling} predicts that a floating contact charges with $\tau = (R_\mathrm{net} + R_\mathrm{f})\,C_\mathrm{f}$ and the firmware waits $2\tau$, at least \qty{1}{\milli\second}. A plug-in capture at \qty{0.5}{\micro\second} resolution contains such a step: in the second pair the ring switches from driven low to floating and charges through a pedal of about \qty{9.4}{\kilo\ohm}. A least-squares fit gives $\tau = \qty{190.6}{\micro\second}$ against $(9.4 + 10)\,\unit{\kilo\ohm} \times \qty{10}{\nano\farad} = \qty{194}{\micro\second}$ predicted. Only \qty{0.61}{\volt} of the \qty{1.71}{\volt} step follow the RC curve; the rest happens instantly. After the \qty{1}{\milli\second} minimum wait ($5.2\,\tau$) \qty{3.2}{\milli\volt} are missing, and the floating contact is read last in its pair, about \qty{9}{\milli\second} after the latch, so the error is negligible.
}

\scaffold{
  \textbf{Paragraph 2, latch edges.} A driven contact jumps by about \qty{91}{\percent} at the latch edge and settles with $\tau \approx \qty{110}{\micro\second} = (\qty{10}{\kilo\ohm} + \qty{1}{\kilo\ohm}) \times \qty{10}{\nano\farad}$, because the filter capacitor sits behind the \qty{10}{\kilo\ohm} resistor; the minimum wait covers five to nine of these time constants.
}
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

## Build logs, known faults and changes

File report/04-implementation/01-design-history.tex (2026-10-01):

% !TEX root = ../main.tex

\section{Design History and Decisions}
\label{sec:design-history}

\scaffold{
  \textbf{Paragraph 1, purpose of the section.} The hardware went through four stages: the project proposal (April 2026) \cite{benson2026proposal}, the circuit of milestone~1, a breadboard prototype (August 2026) and the final PCB (designed late August to early September 2026, assembled end of September). \Cref{tab:design-history} compares them; the following paragraphs give the reason for every change. The reader should finish the section knowing why the final board looks as it does, so that \crefrange{sec:analog-front-end}{sec:pcb} can describe it without justifying it again. Write in the past tense (events of the project), as the writing guide prescribes for findings.
}

\begin{table}[htbp]
  \centering
  \small
  \titledcaption{Design Stages}{\scaffoldinline{Explain the four columns (proposal \cite{benson2026proposal}, milestone~1 circuit, breadboard prototype, final PCB) and that the text gives the reason for each change. Cells marked [?] are unconfirmed.}}
  \label{tab:design-history}
  \begin{tabularx}{\linewidth}{@{}>{\raggedright\arraybackslash}p{0.15\linewidth}*{4}{>{\raggedright\arraybackslash}X}@{}}
    \toprule
    & \textbf{Proposal} & \textbf{Milestone 1} & \textbf{Breadboard} & \textbf{Final PCB} \\
    \midrule
    Microcontroller & STM32G4 or RP2040 & Pico~2 module & Pico~2~W & Pico~2~W \\
    ADC & ADS8688, 16-bit SAR & AD7124-8, 24-bit $\Sigma\Delta$ & AD7718 [?] & 2$\times$ AD7718, 24-bit $\Sigma\Delta$ \\
    Pull switching & TS5A23157 SPDT switches & SN74LVC126A tristate buffers & tristate buffers [?] & TMUX1511 SPST switches \\
    Pull resistance & series resistor per contact & \qty{1}{\kilo\ohm} per contact & \qty{1}{\kilo\ohm} per contact & \qty{1}{\kilo\ohm} \qty{0.1}{\percent}, shared per rail and jack \\
    Input filter & RC & \qty{1}{\kilo\ohm}, \qty{100}{\nano\farad} & \qtyrange{68}{100}{\nano\farad} [?] & \qty{10}{\kilo\ohm}, \qty{10}{\nano\farad} \\
    Contacts per jack & 3 & 4 (one unused) & 3 & 4 (tip switch used) \\
    Analog rail, reference & separate analog rail & \qty{3.3}{\volt} analog rail & \qty{3.3}{\volt} & \qty{2.5}{\volt} LDO, pull-up rail and reference \\
    Ground & star point & star point & -- & one ground net \\
    Outputs & USB MIDI, optional DIN MIDI & USB MIDI & USB MIDI, WiFi & USB MIDI, WiFi, 4 LEDs \\
    \bottomrule
  \end{tabularx}
\end{table}

\begin{figure}[htbp]
  \centering
  \begin{subfigure}[t]{\linewidth}
    \centering
    
    \caption{Milestone 1: Tristate Buffers}
    \label{fig:frontend-milestone-1}
  \end{subfigure}

  \vspace{4mm}
  \begin{subfigure}[t]{\linewidth}
    \centering
    \placeholderfigure[0.85\linewidth]{
      \textbf{Content.} The pull stage of one jack of the final board, cropped from \cref{fig:frontend-final}: U6 (74HC595), U15 and U19 (TMUX1511) with the shared resistors R50 and R54, without the RC filters.
      \textbf{Focus.} Same scale and orientation as (a), so that buffer and switch versions can be compared directly.
      \textbf{How to obtain.} Crop \code{04-implementation/figures/frontend-final.png} or export the sheet \code{hardware/AnalogQuadChannel.kicad\_sch} with \code{kicad-cli sch export svg}.
    }
    \caption{Final PCB: Analog Switches}
    \label{fig:frontend-switches}
  \end{subfigure}
  \titledcaption{Pull Stage Before and After the Change}{\scaffoldinline{(a): each 74HC595 output pair drives data and output enable of one SN74LVC126A buffer, whose output reaches the contact through a \qty{1}{\kilo\ohm} resistor (R1--R4); R5--R8 and C1--C4 form the old filter. (b): one switch per contact and rail, all switches of a rail sharing one \qty{0.1}{\percent} resistor.}}
  \label{fig:pull-stage-history}
\end{figure}

\subsection*{Pull Switching}

\scaffold{
  Proposal: SPDT analog switches \cite{ti2026ts5a23157}. Milestone~1 and breadboard: tristate buffers (SN74LVC126A \cite{ti2026sn74lvc126a}) driven by a 74HC595 chain, two control bits per contact (data and output enable), with a \qty{1}{\kilo\ohm} resistor at each output (\cref{fig:frontend-milestone-1}). Reason for the change to TMUX1511 switches \cite{ti2025tmux1511} (author's statement in the final presentation): the buffers worked in most cases, but their output impedance is only specified as a range and changed with the applied voltage, while the current computation of \cref{eq:currents} needs a precisely known pull resistance. The on-resistance of the switches, about \qty{2}{\ohm}, is negligible against the \qty{1}{\kilo\ohm} resistor, and \qty{0.1}{\percent} resistors make the pull resistance a known quantity. Add the consequence that comes for free: because the switches of one rail share one resistor, only one contact per rail can be driven at a time, which is exactly the one-high-one-low pattern of \cref{sec:pair-measurement}. Date of the change: 30~August~2026, which required a new schematic and a new layout.
}

\openquestion{Breadboard parts}{
  Which ADC and which buffer IC did the breadboard prototype use? The firmware drove an AD7718 from 6~August~2026, the parts list of the prototype names an ADS1241 and SN74LVC126A, and one development session refers to \enquote{74HC125-type} buffers. Also confirm the capacitance at each contact of the breadboard (the firmware inferred \qtyrange{68}{100}{\nano\farad} from a measured time constant).
}

\subsection*{Analog-to-Digital Converter}

\scaffold{
  Proposal: ADS8688, a 16-bit SAR ADC with eight channels and input protection \cite{ti2026ads8688}. Milestone~1: AD7124-8, a 24-bit sigma-delta ADC that works from \qty{3.3}{\volt} and needs little external circuitry \cite{adi2026ad7124}. The prototype parts list then names the ADS1241 \cite{ti2026ads1241}, and the final board uses two AD7718 \cite{adi2001ad7718}. Reasons recorded in the concept notes: the AD7124-8 exists only in a \qtyproduct{5 x 5}{\milli\metre} 32-lead LFCSP, hard to solder by hand, and was not available in single quantities; the ADS1241 is available in SSOP but reaches only 15 samples per second (30 with a faster crystal) \cite{ti2026ads1241}, too slow once several contacts are multiplexed; the AD7718 comes in SOIC-28 and converts at up to \qty{1365}{\hertz} with chopping disabled \cite{adi2001ad7718}. Name the price paid: two ADCs, each with its own \qty{32.768}{\kilo\hertz} crystal, and an input range of \qty{2.56}{\volt} that forced the analog rail down to \qty{2.5}{\volt} (next paragraph).
}

\openquestion{Reason for the AD7718}{
  The reasons above come from an early concept chat, not from the author. Confirm them or state the actual reason (availability, package, price, speed) for leaving the AD7124-8, and whether the ADS1241 was ever built up.
}

\subsection*{Analog Rail and Reference}

\scaffold{
  Milestone~1 planned an analog \qty{3.3}{\volt} rail. The final board pulls up to a \qty{2.5}{\volt} LDO rail that is at the same time the reference input of both ADCs, which makes every reading ratiometric: a shift of the rail moves the measured voltages and the reference together. Reason: the input range of the AD7718 ends at \qty{2.56}{\volt} with a \qty{2.5}{\volt} reference \cite{adi2001ad7718}. Call the rail a rail, not a precision reference: it is an ADP7142 LDO \cite{adi2025adp7142}.
}

\subsection*{Supply Split and Grounding}

\scaffold{
  Proposal and milestone~1 planned a separate analog supply and an analog ground joined to the digital ground at a single star point near the ADC \cite{benson2026proposal, kester2009mt031}. The final board has one \qty{3.3}{\volt} rail (named \net{+3.3VA}) for the ADCs' analog and digital supply, the shift registers and the switches, and one ground net poured on both layers of the two-layer board. State the reason in one or two sentences.
}

\openquestion{Reason for one ground net}{
  The decision to drop the star point and the separate analog supply is described as deliberate, but its reason is not recorded. Give it (for example: a sigma-delta ADC with low input bandwidth, short distances, a continuous ground plane on a two-layer board being the safer choice).
}

\subsection*{Input Filter}

\scaffold{
  Milestone~1: \qty{1}{\kilo\ohm} and \qty{100}{\nano\farad} per input; final board: \qty{10}{\kilo\ohm} and \qty{10}{\nano\farad}, corner frequency \qty{1.6}{\kilo\hertz}. Give the reason. Arguments available from the development notes: the corner stays the same order of magnitude while the capacitor that floating contacts must charge is ten times smaller (settling, \cref{sec:analog-front-end}); the filter still attenuates the region around the \qty{32.768}{\kilo\hertz} modulator clock of the AD7718 by about a factor of 20 and protects against RF pickup on long cables and ESD.
}

\openquestion{Reason for the filter values}{
  Why did the input filter change from \qty{1}{\kilo\ohm}/\qty{100}{\nano\farad} to \qty{10}{\kilo\ohm}/\qty{10}{\nano\farad}? The arguments in the box above were written after the board was ordered.
}

\subsection*{Contacts per Jack}

\scaffold{
  Milestone~1 switched four contacts per jack with one unused. Reason (final presentation): the switch and buffer ICs have four channels, so the fourth channel was free; it was connected to the tip switch of the jack and became the plug detection of \cref{sec:plug-detection}.
}

\subsection*{Microcontroller}

\scaffold{
  Proposal: STM32G4 or RP2040, both with native USB. Milestone~1 and later: the Raspberry Pi Pico~2 module \cite{rpi2026pico2w}; arguments from the milestone notes and the final presentation: a bare chip would need USB, crystal and flash added by hand, while the module is tested hardware; an STM32 has a faster CPU but needs more external parts and a proprietary USB stack; the Pico offers simple debugging through a debug probe, USB MIDI, two SPI peripherals (one for the ADCs, one for the shift registers) and, in the W variant, WiFi for a test interface.
}

\subsection*{Input Protection}

\scaffold{
  Milestone~1 used an ideal-diode controller (LM74700) for reverse-polarity protection. It was replaced by a passive P-channel MOSFET because the controller targets battery and automotive rails rather than a DC input from a wall adapter, which the author called a mistake of the first design. The final chain is a resettable fuse, a bidirectional TVS diode and the P-MOSFET with a gate Zener (details in \cref{sec:microcontroller-power}).
}

\openquestion{Supply voltage and polarity}{
  Which input voltage is the board designed for (an early session assumed \qty{9}{\volt}, the \qty{15}{\volt} clamp parts suggest up to \qty{12}{\volt}), and is reverse polarity blocked or made to work? The final schematic has no rectifier bridge.
}

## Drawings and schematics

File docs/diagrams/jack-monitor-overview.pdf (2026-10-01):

## Plug detection

## Identification

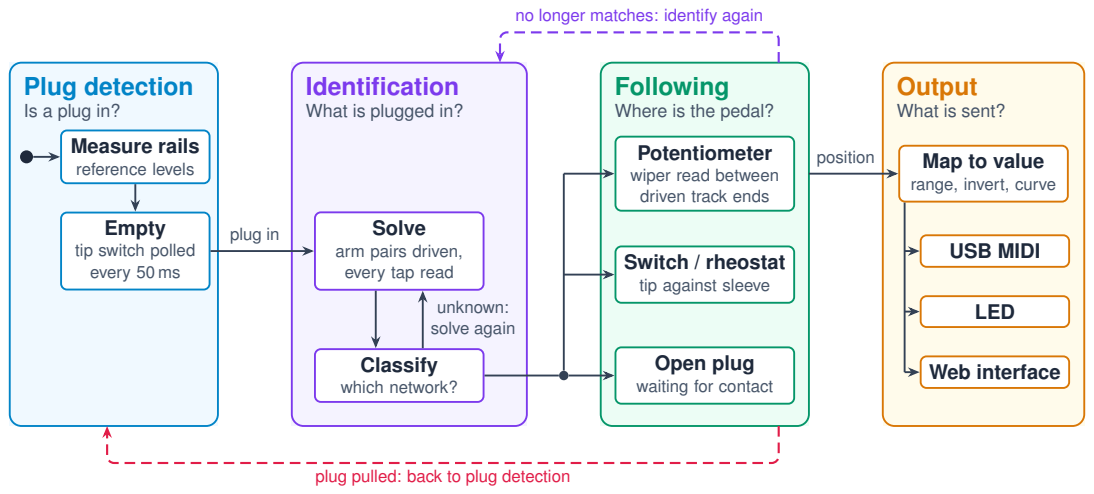
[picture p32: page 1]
plug in; Classify; which network?; unknown: solve again; position; USB MIDI; LED; Web interface

no longer matches: identify again

Following
Where is the pedal?

Output
What is sent?

Is a plug in?
Measure rails
reference levels

What is plugged in?

Potentiometer
wiper read between
driven track ends

Map to value
range, invert, curve

Empty
tip switch polled
every 50 ms

Solve
arm pairs driven,
every tap read

Switch / rheostat
tip against sleeve

Open plug
waiting for contact

plug pulled: back to plug detection

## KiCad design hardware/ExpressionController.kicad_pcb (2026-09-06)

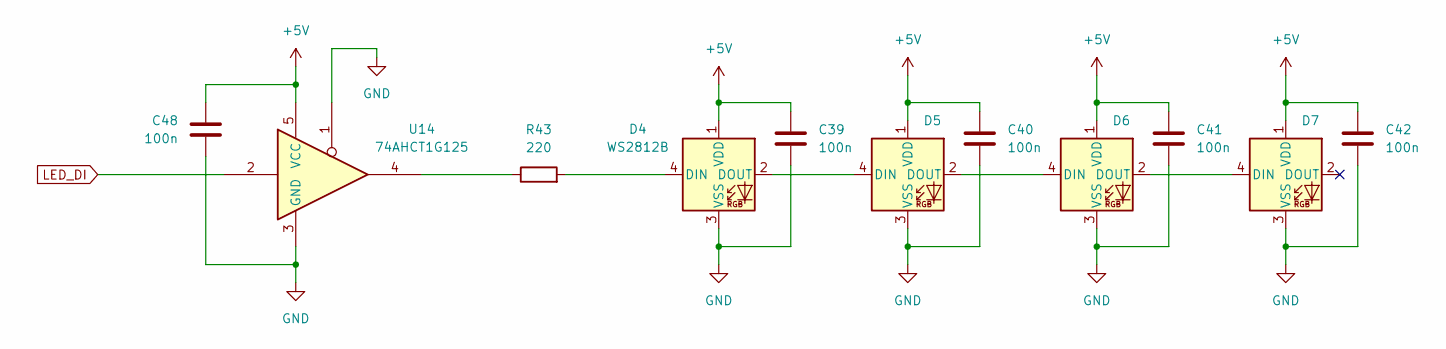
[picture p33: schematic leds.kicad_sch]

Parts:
C39, C40, C41, C42, C48: 100n; C_0805_2012Metric; Part Source Uni
D4, D5, D6, D7: WS2812B; LED_WS2812B_PLCC4_5.0x5.0mm_P3.2mm; Part Source Mouser; Mouser No 485-1655
R43: 220; R_0805_2012Metric; Part Source Uni
U14: 74AHCT1G125; SOT-353_SC-70-5; Part Source Mouser; Mouser No 595-74AHCT1G125DCKRG

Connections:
+5V: C39.1, C40.1, C41.1, C42.1, C48.1, D4.1 (VDD), D5.1 (VDD), D6.1 (VDD), D7.1 (VDD), U14.5 (VCC); also elsewhere on the board
GND: C39.2, C40.2, C41.2, C42.2, C48.2, D4.3 (VSS), D5.3 (VSS), D6.3 (VSS), D7.3 (VSS), U14.1, U14.3 (GND); also elsewhere on the board
LED_DI: U14.2; also elsewhere on the board
unnamed: D4.4 (DIN), R43.2
unnamed: D4.2 (DOUT), D5.4 (DIN)
unnamed: D5.2 (DOUT), D6.4 (DIN)
unnamed: D6.2 (DOUT), D7.4 (DIN)
unnamed: R43.1, U14.4

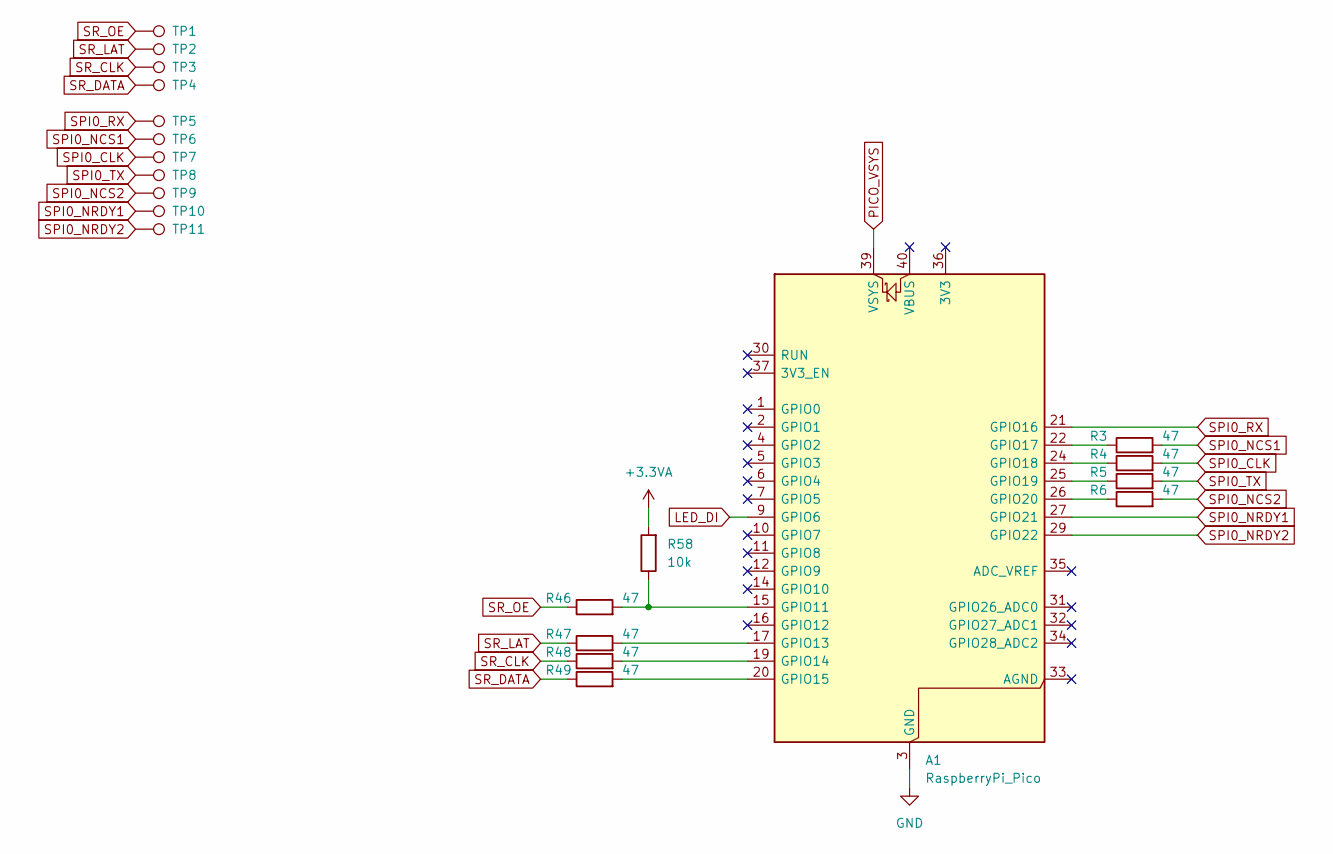
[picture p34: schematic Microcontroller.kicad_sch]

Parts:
A1: RaspberryPi_Pico; Pico_2W_with_Header; Part Source Uni
R3, R4, R5, R6, R46, R47, R48, R49: 47; R_0805_2012Metric; Part Source Uni
R58: 10k; R_0805_2012Metric; Part Source Uni
TP1, TP2, TP3, TP4, TP5, TP6, TP7, TP8, TP9, TP10, TP11: TestPoint; TestPoint_THTPad_D1.5mm_Drill0.7mm

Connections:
+3.3VA: R58.2; also elsewhere on the board
GND: A1.3 (GND), A1.8 (GND), A1.13 (GND), A1.18 (GND), A1.23 (GND), A1.28 (GND), A1.38 (GND); also elsewhere on the board
LED_DI: A1.9 (GPIO6); also elsewhere on the board
unnamed: A1.15 (GPIO11), R46.2, R58.1
unnamed: A1.17 (GPIO13), R47.2
unnamed: A1.19 (GPIO14), R48.2
unnamed: A1.20 (GPIO15), R49.2
unnamed: A1.22 (GPIO17), R3.1
unnamed: A1.24 (GPIO18), R4.1
unnamed: A1.25 (GPIO19), R5.1
unnamed: A1.26 (GPIO20), R6.1
PICO_VSYS: A1.39 (VSYS); also elsewhere on the board
SPI0_CLK: R4.2, TP7.1 (1_1); also elsewhere on the board
SPI0_NCS1: R3.2, TP6.1 (1_1); also elsewhere on the board
SPI0_NCS2: R6.2, TP9.1 (1_1); also elsewhere on the board
SPI0_NRDY1: A1.27 (GPIO21), TP10.1 (1_1); also elsewhere on the board
SPI0_NRDY2: A1.29 (GPIO22), TP11.1 (1_1); also elsewhere on the board
SPI0_RX: A1.21 (GPIO16), TP5.1 (1_1); also elsewhere on the board
SPI0_TX: R5.2, TP8.1 (1_1); also elsewhere on the board
SR_CLK: R48.1, TP3.1 (1_1); also elsewhere on the board
SR_DATA: R49.1, TP4.1 (1_1); also elsewhere on the board
SR_LAT: R47.1, TP2.1 (1_1); also elsewhere on the board
SR_OE: R46.1, TP1.1 (1_1); also elsewhere on the board

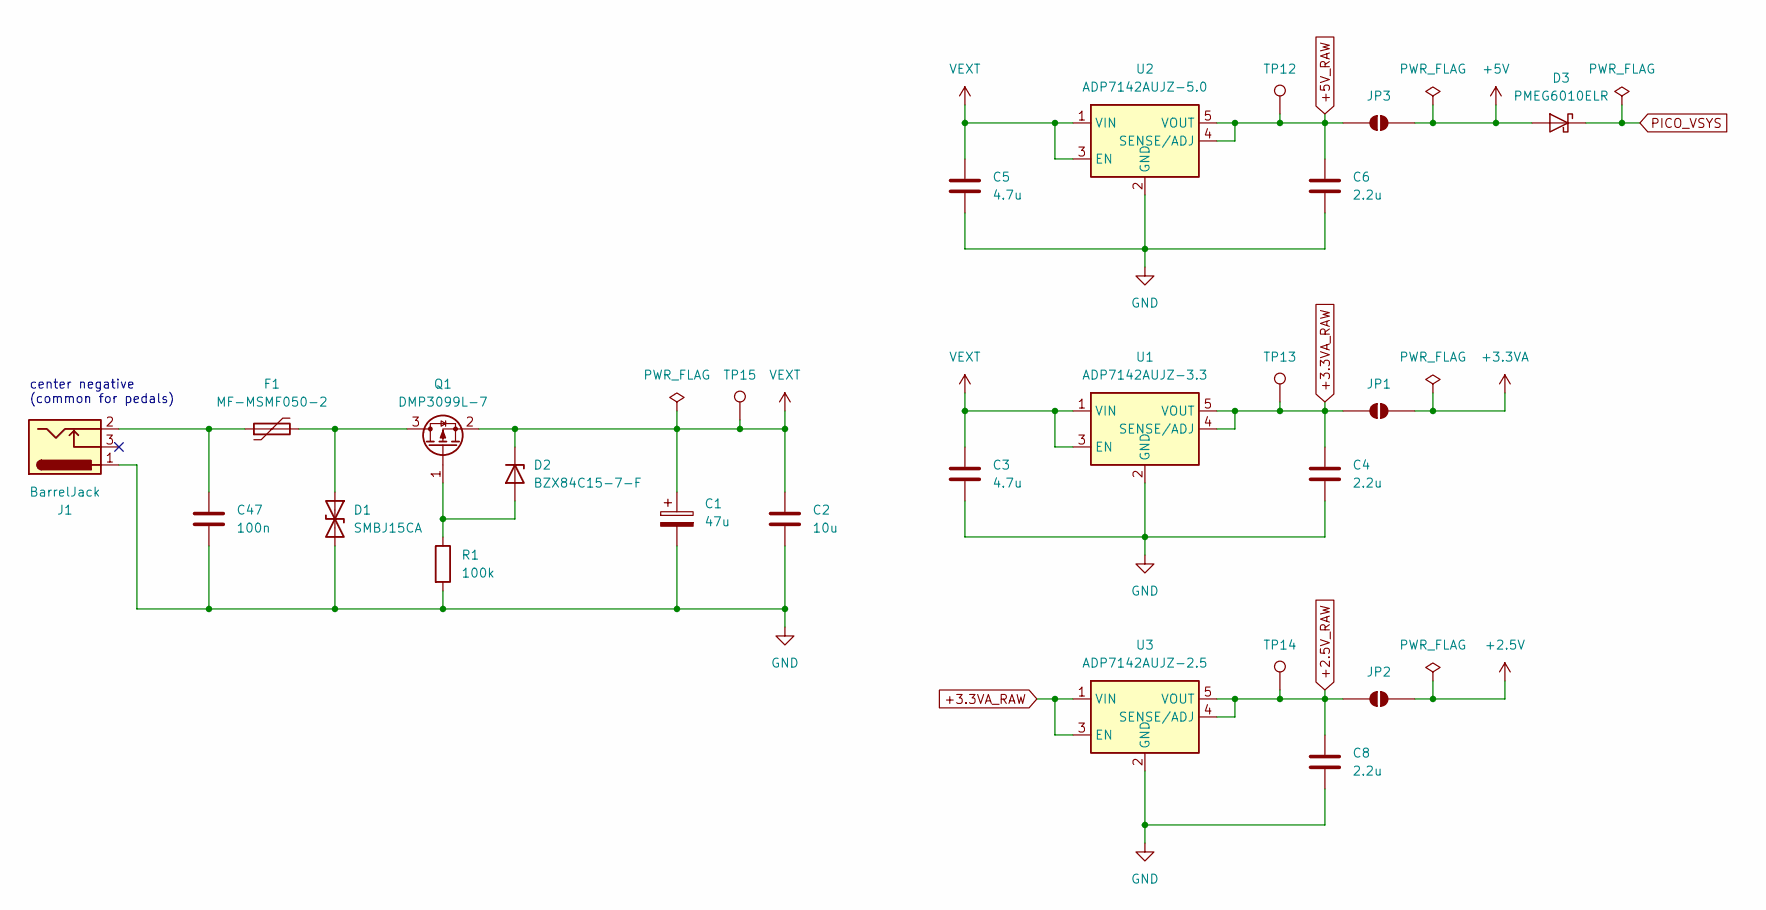
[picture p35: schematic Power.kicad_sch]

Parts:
C1: 47u; CP_Elec_6.3x5.8; Part Source Mouser; Mouser No 667-EEH-ZC1E470P
C2: 10u; C_0805_2012Metric; Part Source Uni
C3, C5: 4.7u; C_0805_2012Metric; Part Source Uni
C4, C6, C8: 2.2u; C_0805_2012Metric; Part Source Uni
C47: 100n; C_0805_2012Metric; Part Source Uni
D1: SMBJ15CA; D_SMB; Part Source Mouser; Mouser No 947-SMBJ15CA
D2: BZX84C15-7-F; SOT-23; Part Source Mouser; Mouser No 621-BZX84C15-F
D3: PMEG6010ELR; Nexperia_CFP3_SOD-123W; Part Source Mouser; Mouser No 771-PMEG6010ELRX
F1: MF-MSMF050-2; Fuse_1812_4532Metric; Part Source Mouser; Mouser No 652-MF-MSMF050-2
J1: BarrelJack; BarrelJack_CUI_PJ-102AH_Horizontal; Part Source Mouser; Mouser No 490-PJ-102AH
JP1, JP2, JP3: SolderJumper_2_Open; SolderJumper-2_P1.3mm_Open_RoundedPad1.0x1.5mm
Q1: DMP3099L-7; SOT-23; Part Source Mouser; Mouser No 621-DMP3099L-7
R1: 100k; R_0805_2012Metric; Part Source Uni
TP12, TP13, TP14, TP15: TestPoint; TestPoint_THTPad_D1.5mm_Drill0.7mm
U1: ADP7142AUJZ-3.3; TSOT-23-5; Part Source Mouser; Mouser No 584-ADP7142AUJZ3.3R7
U2: ADP7142AUJZ-5.0; TSOT-23-5; Part Source Mouser; Mouser No 584-ADP7142WAUJZ-50R
U3: ADP7142AUJZ-2.5; TSOT-23-5; Part Source Mouser; Mouser No 584-ADP7142AUJZ2.5R7

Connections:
+2.5V: JP2.2 (B); also elsewhere on the board
+2.5V_RAW: C8.1, JP2.1 (A), TP14.1 (1_1), U3.4 (SENSE/ADJ), U3.5 (VOUT)
+3.3VA: JP1.2 (B); also elsewhere on the board
+3.3VA_RAW: C4.1, JP1.1 (A), TP13.1 (1_1), U1.4 (SENSE/ADJ), U1.5 (VOUT), U3.1 (VIN), U3.3 (EN)
+5V: D3.2 (A), JP3.2 (B); also elsewhere on the board
+5V_RAW: C6.1, JP3.1 (A), TP12.1 (1_1), U2.4 (SENSE/ADJ), U2.5 (VOUT)
GND: C1.2, C2.2, C3.2, C4.2, C5.2, C6.2, C8.2, C47.2, D1.2 (A2), J1.1, R1.2, U1.2 (GND), U2.2 (GND), U3.2 (GND); also elsewhere on the board
unnamed: C47.1, F1.1, J1.2
unnamed: D1.1 (A1), F1.2, Q1.3 (D)
unnamed: D2.1 (A), Q1.1 (G), R1.1
PICO_VSYS: D3.1 (K); also elsewhere on the board
VEXT: C1.1, C2.1, C3.1, C5.1, D2.3 (K), Q1.2 (S), TP15.1 (1_1), U1.1 (VIN), U1.3 (EN), U2.1 (VIN), U2.3 (EN)

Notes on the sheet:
center negative (common for pedals)

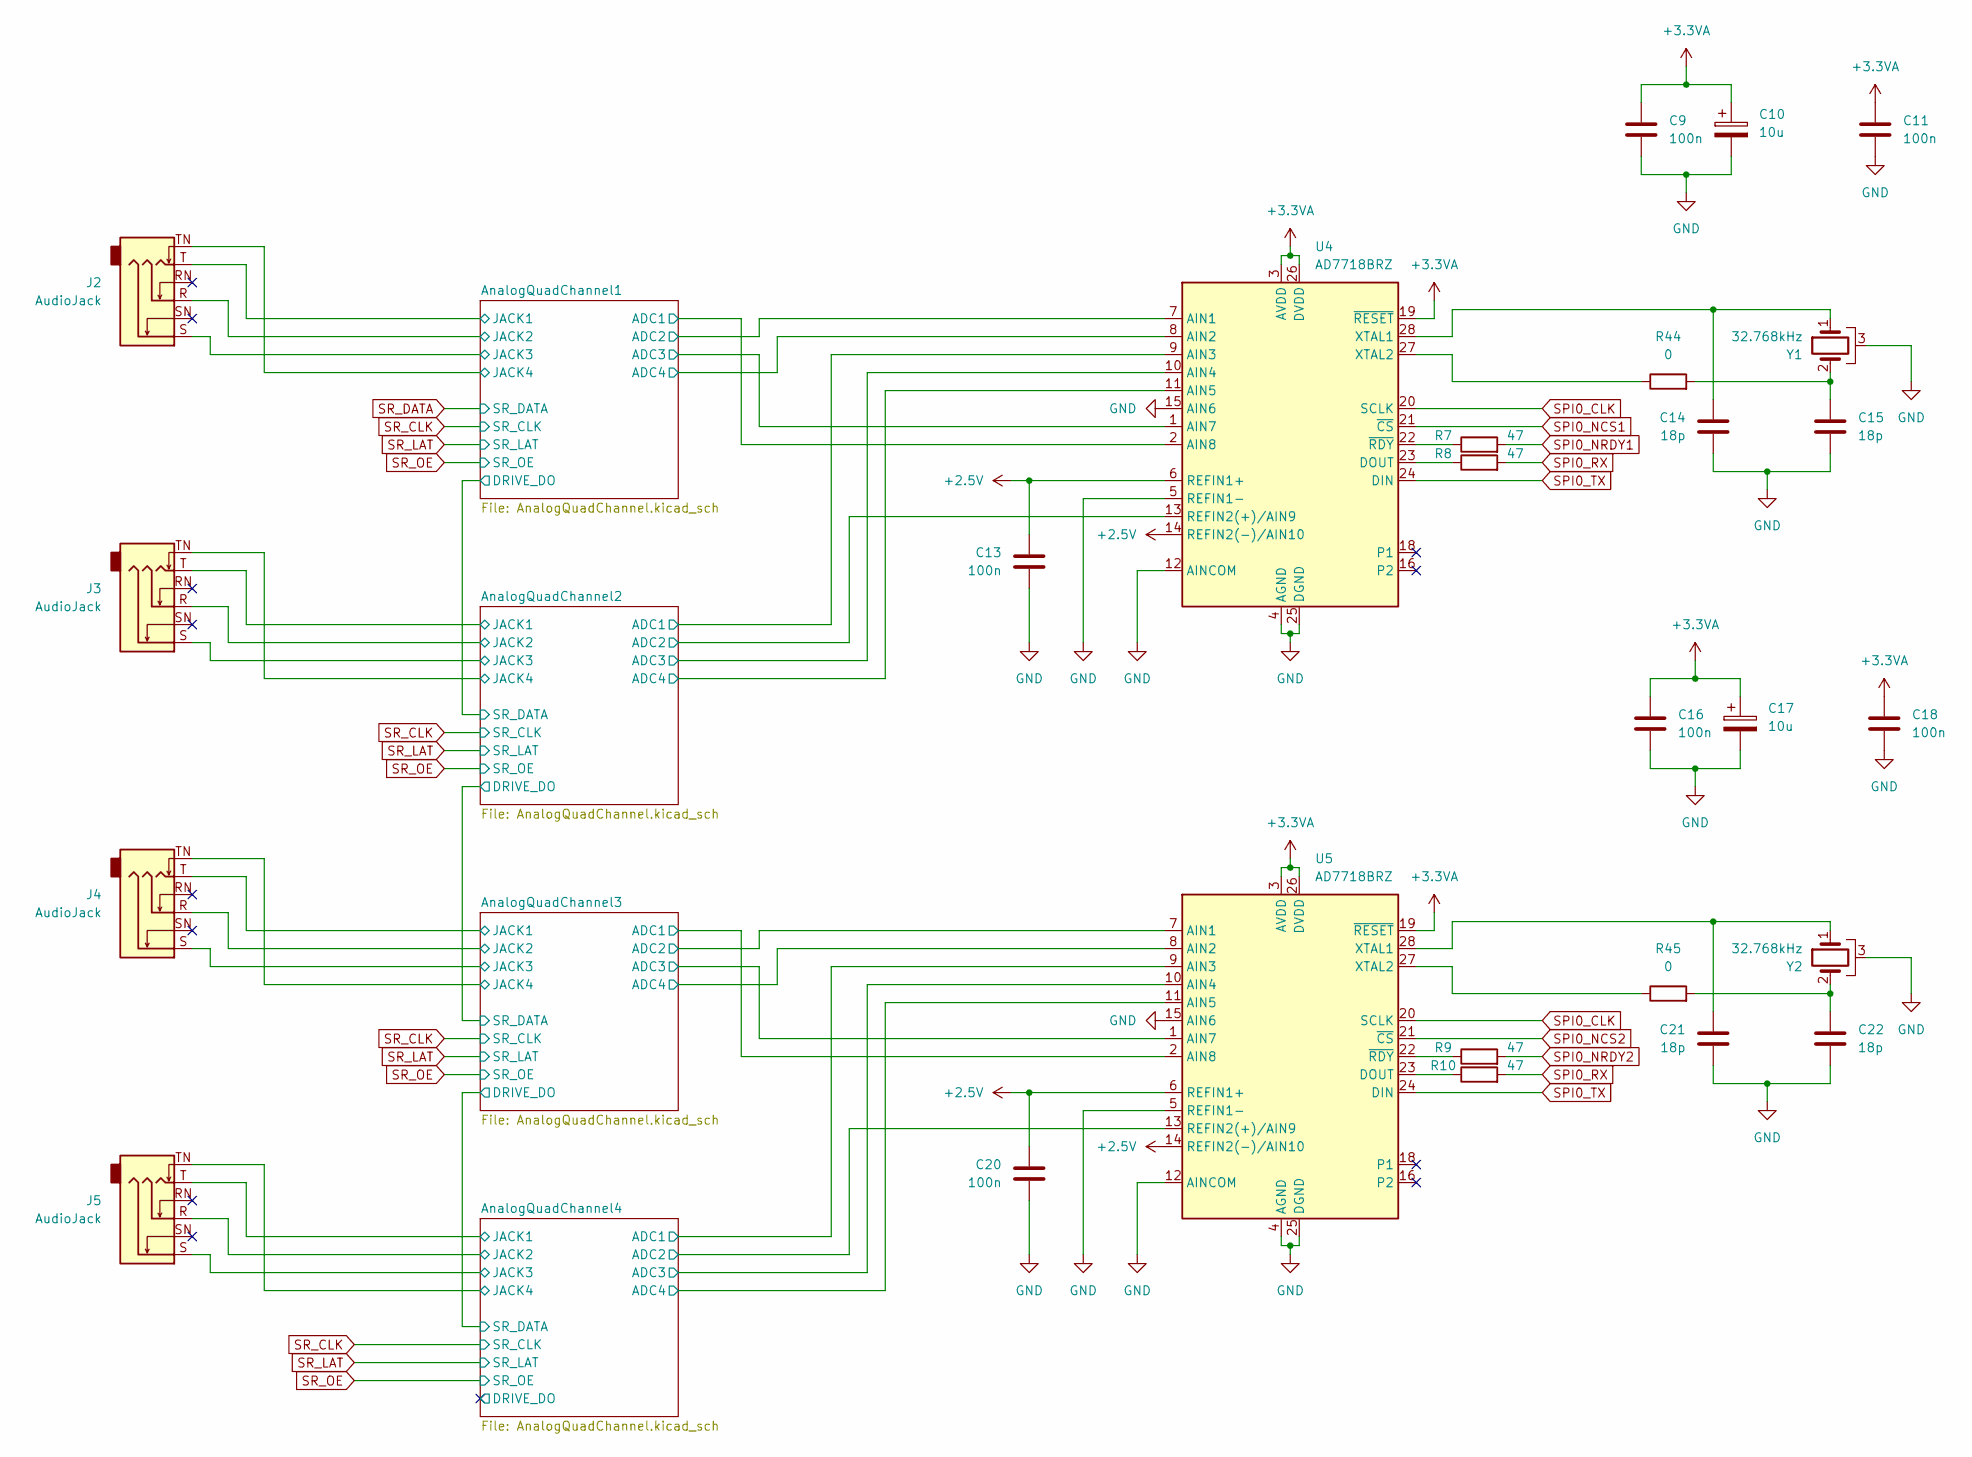
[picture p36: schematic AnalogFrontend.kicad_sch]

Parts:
C9, C11, C13, C16, C18, C20: 100n; C_0805_2012Metric; Part Source Uni
C10, C17: 10u; C_0805_2012Metric; Part Source Uni
C14, C15, C21, C22: 18p; C_0805_2012Metric; Part Source Uni
J2, J3, J4, J5: AudioJack; Jack_6.35mm_Neutrik_NMJ6HFD4_Horizontal; Part Source Mouser; Mouser No 568-NMJ6HFD2-AU
R7, R8, R9, R10: 47; R_0805_2012Metric; Part Source Uni
R44, R45: 0; R_0805_2012Metric; Part Source Uni
U4, U5: AD7718BRZ; SOIC-28W_7.5x17.9mm_P1.27mm; Part Source Mouser; Mouser No 584-AD7718BRZ
Y1, Y2: 32.768kHz; MS1V-T1K; Part Source Mouser; Mouser No 428-200120-ML02

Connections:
+2.5V: C13.1, C20.1, U4.6 (REFIN1+), U4.14 (REFIN2(-)/AIN10), U5.6 (REFIN1+), U5.14 (REFIN2(-)/AIN10); also elsewhere on the board
+3.3VA: C9.1, C10.1, C11.1, C16.1, C17.1, C18.1, U4.3 (AVDD), U4.19 (~RESET), U4.26 (DVDD), U5.3 (AVDD), U5.19 (~RESET), U5.26 (DVDD); also elsewhere on the board
/AnalogFrontend/AnalogQuadChannel1/ADC1: U4.2 (AIN8); also elsewhere on the board
/AnalogFrontend/AnalogQuadChannel1/ADC2: U4.7 (AIN1); also elsewhere on the board
/AnalogFrontend/AnalogQuadChannel1/ADC3: U4.1 (AIN7); also elsewhere on the board
/AnalogFrontend/AnalogQuadChannel1/ADC4: U4.8 (AIN2); also elsewhere on the board
/AnalogFrontend/AnalogQuadChannel1/JACK1: J2.T; also elsewhere on the board
/AnalogFrontend/AnalogQuadChannel1/JACK2: J2.R; also elsewhere on the board
/AnalogFrontend/AnalogQuadChannel1/JACK3: J2.S; also elsewhere on the board
/AnalogFrontend/AnalogQuadChannel1/JACK4: J2.TN; also elsewhere on the board
/AnalogFrontend/AnalogQuadChannel2/ADC1: U4.9 (AIN3); also elsewhere on the board
/AnalogFrontend/AnalogQuadChannel2/ADC2: U4.13 (REFIN2(+)/AIN9); also elsewhere on the board
/AnalogFrontend/AnalogQuadChannel2/ADC3: U4.10 (AIN4); also elsewhere on the board
/AnalogFrontend/AnalogQuadChannel2/ADC4: U4.11 (AIN5); also elsewhere on the board
/AnalogFrontend/AnalogQuadChannel2/JACK1: J3.T; also elsewhere on the board
/AnalogFrontend/AnalogQuadChannel2/JACK2: J3.R; also elsewhere on the board
/AnalogFrontend/AnalogQuadChannel2/JACK3: J3.S; also elsewhere on the board
/AnalogFrontend/AnalogQuadChannel2/JACK4: J3.TN; also elsewhere on the board
/AnalogFrontend/AnalogQuadChannel3/ADC1: U5.2 (AIN8); also elsewhere on the board
/AnalogFrontend/AnalogQuadChannel3/ADC2: U5.7 (AIN1); also elsewhere on the board
/AnalogFrontend/AnalogQuadChannel3/ADC3: U5.1 (AIN7); also elsewhere on the board
/AnalogFrontend/AnalogQuadChannel3/ADC4: U5.8 (AIN2); also elsewhere on the board
/AnalogFrontend/AnalogQuadChannel3/JACK1: J4.T; also elsewhere on the board
/AnalogFrontend/AnalogQuadChannel3/JACK2: J4.R; also elsewhere on the board
/AnalogFrontend/AnalogQuadChannel3/JACK3: J4.S; also elsewhere on the board
/AnalogFrontend/AnalogQuadChannel3/JACK4: J4.TN; also elsewhere on the board
/AnalogFrontend/AnalogQuadChannel4/ADC1: U5.9 (AIN3); also elsewhere on the board
/AnalogFrontend/AnalogQuadChannel4/ADC2: U5.13 (REFIN2(+)/AIN9); also elsewhere on the board
/AnalogFrontend/AnalogQuadChannel4/ADC3: U5.10 (AIN4); also elsewhere on the board
/AnalogFrontend/AnalogQuadChannel4/ADC4: U5.11 (AIN5); also elsewhere on the board
/AnalogFrontend/AnalogQuadChannel4/JACK1: J5.T; also elsewhere on the board
/AnalogFrontend/AnalogQuadChannel4/JACK2: J5.R; also elsewhere on the board
/AnalogFrontend/AnalogQuadChannel4/JACK3: J5.S; also elsewhere on the board
/AnalogFrontend/AnalogQuadChannel4/JACK4: J5.TN; also elsewhere on the board
GND: C9.2, C10.2, C11.2, C13.2, C14.2, C15.2, C16.2, C17.2, C18.2, C20.2, C21.2, C22.2, U4.4 (AGND), U4.5 (REFIN1-), U4.12 (AINCOM), U4.15 (AIN6), U4.17 (AGND), U4.25 (DGND), U5.4 (AGND), U5.5 (REFIN1-), U5.12 (AINCOM), U5.15 (AIN6), U5.17 (AGND), U5.25 (DGND), Y1.3, Y2.3; also elsewhere on the board
unnamed: C15.1, R44.2, Y1.2
unnamed: C22.1, R45.2, Y2.2
unnamed: R8.1, U4.23 (DOUT)
unnamed: C14.1, U4.28 (XTAL1), Y1.1
unnamed: R44.1, U4.27 (XTAL2)
unnamed: R7.1, U4.22 (~RDY)
unnamed: R10.1, U5.23 (DOUT)
unnamed: C21.1, U5.28 (XTAL1), Y2.1
unnamed: R45.1, U5.27 (XTAL2)
unnamed: R9.1, U5.22 (~RDY)
SPI0_CLK: U4.20 (SCLK), U5.20 (SCLK); also elsewhere on the board
SPI0_NCS1: U4.21 (~CS); also elsewhere on the board
SPI0_NCS2: U5.21 (~CS); also elsewhere on the board
SPI0_NRDY1: R7.2; also elsewhere on the board
SPI0_NRDY2: R9.2; also elsewhere on the board
SPI0_RX: R8.2, R10.2; also elsewhere on the board
SPI0_TX: U4.24 (DIN), U5.24 (DIN); also elsewhere on the board

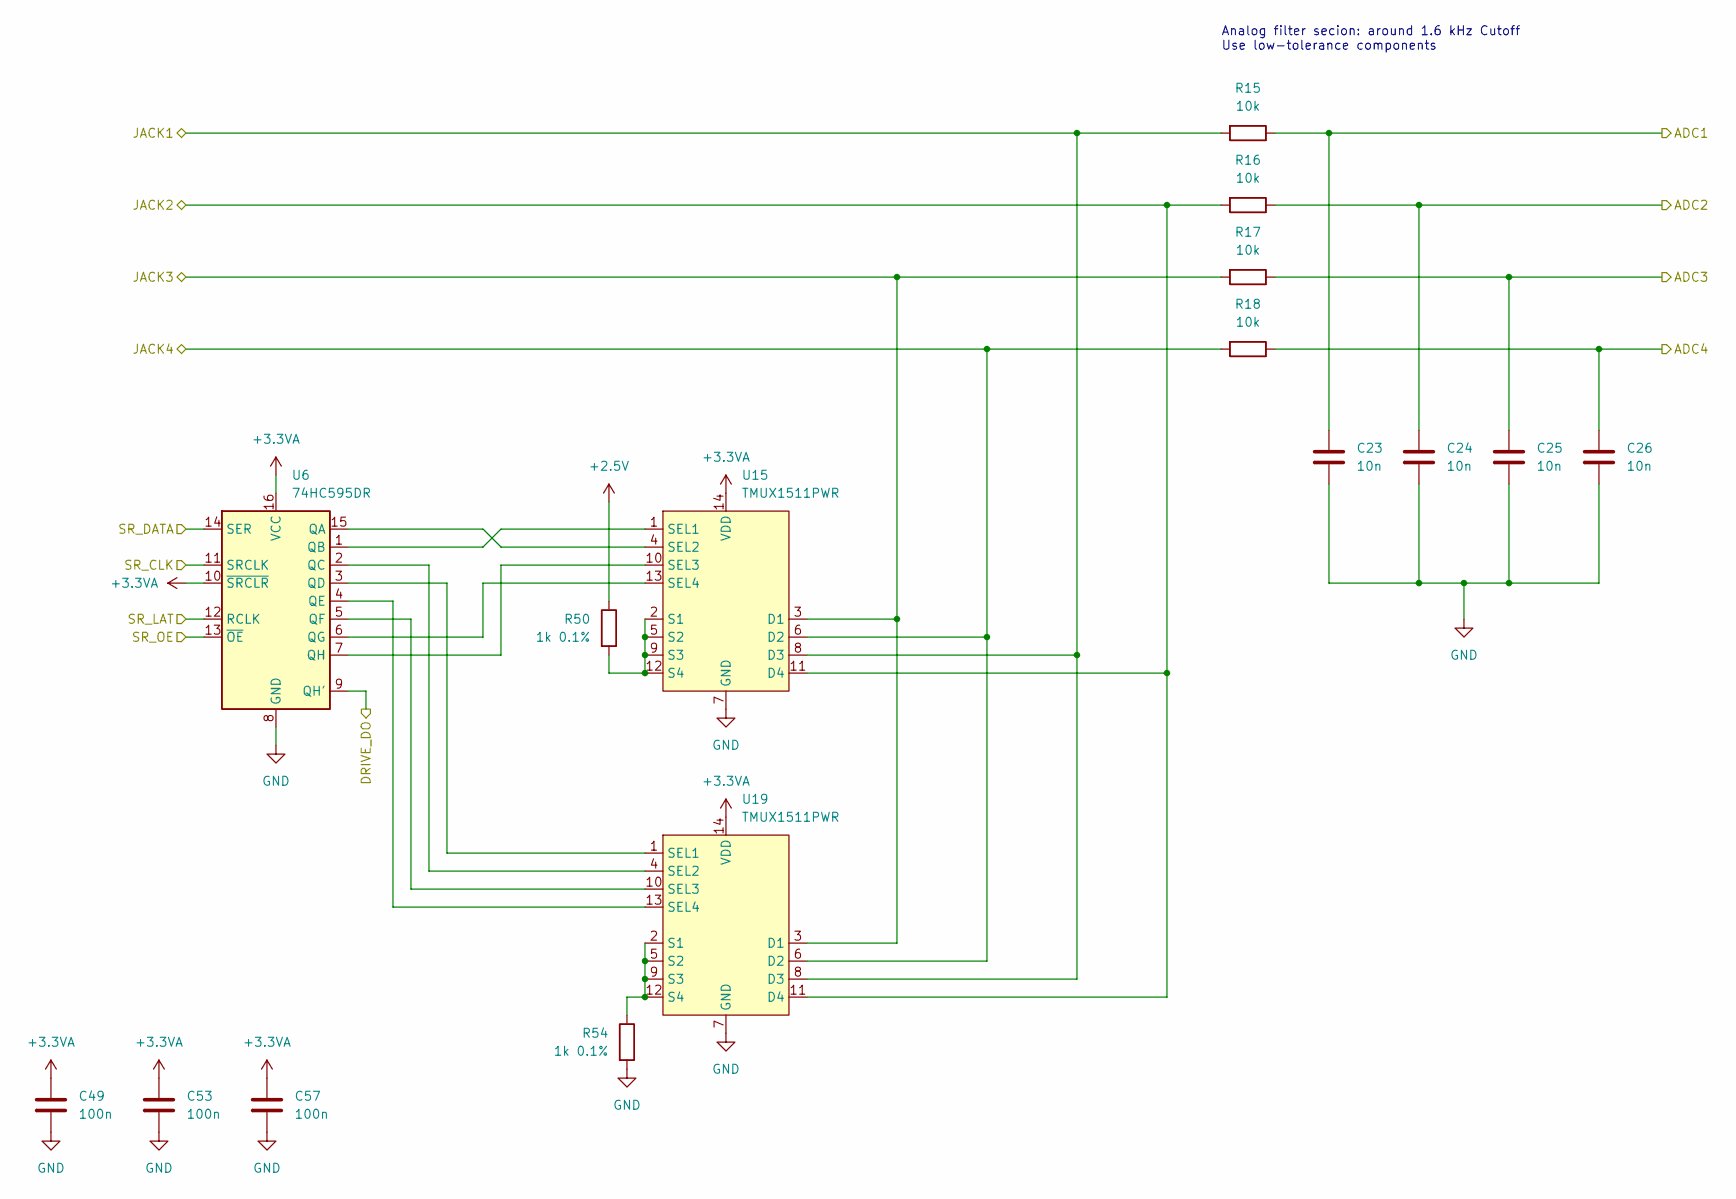
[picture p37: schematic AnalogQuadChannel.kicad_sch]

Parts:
C23, C24, C25, C26: 10n; C_0805_2012Metric; Part Source Uni
C49, C53, C57: 100n; C_0805_2012Metric; Part Source Uni
R15, R16, R17, R18: 10k; R_0805_2012Metric; Part Source Uni
R50, R54: 1k 0.1%; R_0805_2012Metric; Part Source Mouser; Mouser No ERA-6AEB102V
U6: 74HC595DR; SOIC-16_3.9x9.9mm_P1.27mm; Part Source Mouser; Mouser No 595-SN74HC595DR
U15, U19: TMUX1511PWR; TSSOP-14_4.4x5mm_P0.65mm; Part Source Mouser; Mouser No 595-TMUX1511PWR

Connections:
+2.5V: R50.1; also elsewhere on the board
+3.3VA: C49.1, C53.1, C57.1, U6.10 (~SRCLR), U6.16 (VCC), U15.14 (VDD), U19.14 (VDD); also elsewhere on the board
/AnalogFrontend/AnalogQuadChannel1/ADC1: C23.1, R15.1; also elsewhere on the board
/AnalogFrontend/AnalogQuadChannel1/ADC2: C24.1, R16.1; also elsewhere on the board
/AnalogFrontend/AnalogQuadChannel1/ADC3: C25.1, R17.1; also elsewhere on the board
/AnalogFrontend/AnalogQuadChannel1/ADC4: C26.1, R18.1; also elsewhere on the board
/AnalogFrontend/AnalogQuadChannel1/DRIVE_DO: U6.9 (QH'); also elsewhere on the board
/AnalogFrontend/AnalogQuadChannel1/JACK1: R15.2, U15.8 (D3), U19.8 (D3); also elsewhere on the board
/AnalogFrontend/AnalogQuadChannel1/JACK2: R16.2, U15.11 (D4), U19.11 (D4); also elsewhere on the board
/AnalogFrontend/AnalogQuadChannel1/JACK3: R17.2, U15.3 (D1), U19.3 (D1); also elsewhere on the board
/AnalogFrontend/AnalogQuadChannel1/JACK4: R18.2, U15.6 (D2), U19.6 (D2); also elsewhere on the board
GND: C23.2, C24.2, C25.2, C26.2, C49.2, C53.2, C57.2, R54.2, U6.8 (GND), U15.7 (GND), U19.7 (GND); also elsewhere on the board
unnamed: R50.2, U15.2 (S1), U15.5 (S2), U15.9 (S3), U15.12 (S4)
unnamed: U6.1 (QB), U15.1 (SEL1)
unnamed: U6.15 (QA), U15.4 (SEL2)
unnamed: U6.7 (QH), U15.10 (SEL3)
unnamed: U6.6 (QG), U15.13 (SEL4)
unnamed: R54.1, U19.2 (S1), U19.5 (S2), U19.9 (S3), U19.12 (S4)
unnamed: U6.3 (QD), U19.1 (SEL1)
unnamed: U6.2 (QC), U19.4 (SEL2)
unnamed: U6.5 (QF), U19.10 (SEL3)
unnamed: U6.4 (QE), U19.13 (SEL4)
SR_CLK: U6.11 (SRCLK); also elsewhere on the board
SR_DATA: U6.14 (SER); also elsewhere on the board
SR_LAT: U6.12 (RCLK); also elsewhere on the board
SR_OE: U6.13 (~OE); also elsewhere on the board

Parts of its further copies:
C27, C28, C29, C30, C31, C32, C33, C34, C35, C36, C37, C38: 10n; C_0805_2012Metric; Part Source Uni
C50, C51, C52, C54, C55, C56, C58, C59, C60: 100n; C_0805_2012Metric; Part Source Uni
R23, R24, R25, R26, R31, R32, R33, R34, R39, R40, R41, R42: 10k; R_0805_2012Metric; Part Source Uni
R51, R52, R53, R55, R56, R57: 1k 0.1%; R_0805_2012Metric; Part Source Mouser; Mouser No ERA-6AEB102V
U8, U10, U12: 74HC595DR; SOIC-16_3.9x9.9mm_P1.27mm; Part Source Mouser; Mouser No 595-SN74HC595DR
U16, U17, U18, U20, U21, U22: TMUX1511PWR; TSSOP-14_4.4x5mm_P0.65mm; Part Source Mouser; Mouser No 595-TMUX1511PWR

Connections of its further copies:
+2.5V: R51.1, R52.1, R53.1; also elsewhere on the board
+3.3VA: C50.1, C51.1, C52.1, C54.1, C55.1, C56.1, C58.1, C59.1, C60.1, U8.10 (~SRCLR), U8.16 (VCC), U10.10 (~SRCLR), U10.16 (VCC), U12.10 (~SRCLR), U12.16 (VCC), U16.14 (VDD), U17.14 (VDD), U18.14 (VDD), U20.14 (VDD), U21.14 (VDD), U22.14 (VDD); also elsewhere on the board
/AnalogFrontend/AnalogQuadChannel1/DRIVE_DO: U8.14 (SER); also elsewhere on the board
/AnalogFrontend/AnalogQuadChannel2/ADC1: C27.1, R23.1; also elsewhere on the board
/AnalogFrontend/AnalogQuadChannel2/ADC2: C28.1, R24.1; also elsewhere on the board
/AnalogFrontend/AnalogQuadChannel2/ADC3: C29.1, R25.1; also elsewhere on the board
/AnalogFrontend/AnalogQuadChannel2/ADC4: C30.1, R26.1; also elsewhere on the board
/AnalogFrontend/AnalogQuadChannel2/DRIVE_DO: U8.9 (QH'), U10.14 (SER)
/AnalogFrontend/AnalogQuadChannel2/JACK1: R23.2, U16.8 (D3), U20.8 (D3); also elsewhere on the board
/AnalogFrontend/AnalogQuadChannel2/JACK2: R24.2, U16.11 (D4), U20.11 (D4); also elsewhere on the board
/AnalogFrontend/AnalogQuadChannel2/JACK3: R25.2, U16.3 (D1), U20.3 (D1); also elsewhere on the board
/AnalogFrontend/AnalogQuadChannel2/JACK4: R26.2, U16.6 (D2), U20.6 (D2); also elsewhere on the board
/AnalogFrontend/AnalogQuadChannel3/ADC1: C31.1, R31.1; also elsewhere on the board
/AnalogFrontend/AnalogQuadChannel3/ADC2: C32.1, R32.1; also elsewhere on the board
/AnalogFrontend/AnalogQuadChannel3/ADC3: C33.1, R33.1; also elsewhere on the board
/AnalogFrontend/AnalogQuadChannel3/ADC4: C34.1, R34.1; also elsewhere on the board
/AnalogFrontend/AnalogQuadChannel3/DRIVE_DO: U10.9 (QH'), U12.14 (SER)
/AnalogFrontend/AnalogQuadChannel3/JACK1: R31.2, U17.8 (D3), U21.8 (D3); also elsewhere on the board
/AnalogFrontend/AnalogQuadChannel3/JACK2: R32.2, U17.11 (D4), U21.11 (D4); also elsewhere on the board
/AnalogFrontend/AnalogQuadChannel3/JACK3: R33.2, U17.3 (D1), U21.3 (D1); also elsewhere on the board
/AnalogFrontend/AnalogQuadChannel3/JACK4: R34.2, U17.6 (D2), U21.6 (D2); also elsewhere on the board
/AnalogFrontend/AnalogQuadChannel4/ADC1: C35.1, R39.1; also elsewhere on the board
/AnalogFrontend/AnalogQuadChannel4/ADC2: C36.1, R40.1; also elsewhere on the board
/AnalogFrontend/AnalogQuadChannel4/ADC3: C37.1, R41.1; also elsewhere on the board
/AnalogFrontend/AnalogQuadChannel4/ADC4: C38.1, R42.1; also elsewhere on the board
/AnalogFrontend/AnalogQuadChannel4/DRIVE_DO: U12.9 (QH')
/AnalogFrontend/AnalogQuadChannel4/JACK1: R39.2, U18.8 (D3), U22.8 (D3); also elsewhere on the board
/AnalogFrontend/AnalogQuadChannel4/JACK2: R40.2, U18.11 (D4), U22.11 (D4); also elsewhere on the board
/AnalogFrontend/AnalogQuadChannel4/JACK3: R41.2, U18.3 (D1), U22.3 (D1); also elsewhere on the board
/AnalogFrontend/AnalogQuadChannel4/JACK4: R42.2, U18.6 (D2), U22.6 (D2); also elsewhere on the board
GND: C27.2, C28.2, C29.2, C30.2, C31.2, C32.2, C33.2, C34.2, C35.2, C36.2, C37.2, C38.2, C50.2, C51.2, C52.2, C54.2, C55.2, C56.2, C58.2, C59.2, C60.2, R55.2, R56.2, R57.2, U8.8 (GND), U10.8 (GND), U12.8 (GND), U16.7 (GND), U17.7 (GND), U18.7 (GND), U20.7 (GND), U21.7 (GND), U22.7 (GND); also elsewhere on the board
unnamed: U10.15 (QA), U17.4 (SEL2)
unnamed: U10.1 (QB), U17.1 (SEL1)
unnamed: U10.2 (QC), U21.4 (SEL2)
unnamed: U10.3 (QD), U21.1 (SEL1)
unnamed: U10.4 (QE), U21.13 (SEL4)
unnamed: U10.5 (QF), U21.10 (SEL3)
unnamed: U10.6 (QG), U17.13 (SEL4)
unnamed: U10.7 (QH), U17.10 (SEL3)
unnamed: U12.15 (QA), U18.4 (SEL2)
unnamed: U12.1 (QB), U18.1 (SEL1)
unnamed: U12.2 (QC), U22.4 (SEL2)
unnamed: U12.3 (QD), U22.1 (SEL1)
unnamed: U12.4 (QE), U22.13 (SEL4)
unnamed: U12.5 (QF), U22.10 (SEL3)
unnamed: U12.6 (QG), U18.13 (SEL4)
unnamed: U12.7 (QH), U18.10 (SEL3)
unnamed: R51.2, U16.2 (S1), U16.5 (S2), U16.9 (S3), U16.12 (S4)
unnamed: U8.1 (QB), U16.1 (SEL1)
unnamed: U8.15 (QA), U16.4 (SEL2)
unnamed: U8.7 (QH), U16.10 (SEL3)
unnamed: U8.6 (QG), U16.13 (SEL4)
unnamed: R52.2, U17.2 (S1), U17.5 (S2), U17.9 (S3), U17.12 (S4)
unnamed: R53.2, U18.2 (S1), U18.5 (S2), U18.9 (S3), U18.12 (S4)
unnamed: R55.1, U20.2 (S1), U20.5 (S2), U20.9 (S3), U20.12 (S4)
unnamed: U8.3 (QD), U20.1 (SEL1)
unnamed: U8.2 (QC), U20.4 (SEL2)
unnamed: U8.5 (QF), U20.10 (SEL3)
unnamed: U8.4 (QE), U20.13 (SEL4)
unnamed: R56.1, U21.2 (S1), U21.5 (S2), U21.9 (S3), U21.12 (S4)
unnamed: R57.1, U22.2 (S1), U22.5 (S2), U22.9 (S3), U22.12 (S4)
SR_CLK: U8.11 (SRCLK), U10.11 (SRCLK), U12.11 (SRCLK); also elsewhere on the board
SR_LAT: U8.12 (RCLK), U10.12 (RCLK), U12.12 (RCLK); also elsewhere on the board
SR_OE: U8.13 (~OE), U10.13 (~OE), U12.13 (~OE); also elsewhere on the board

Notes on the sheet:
Analog filter secion: around 1.6 kHz Cutoff Use low-tolerance components

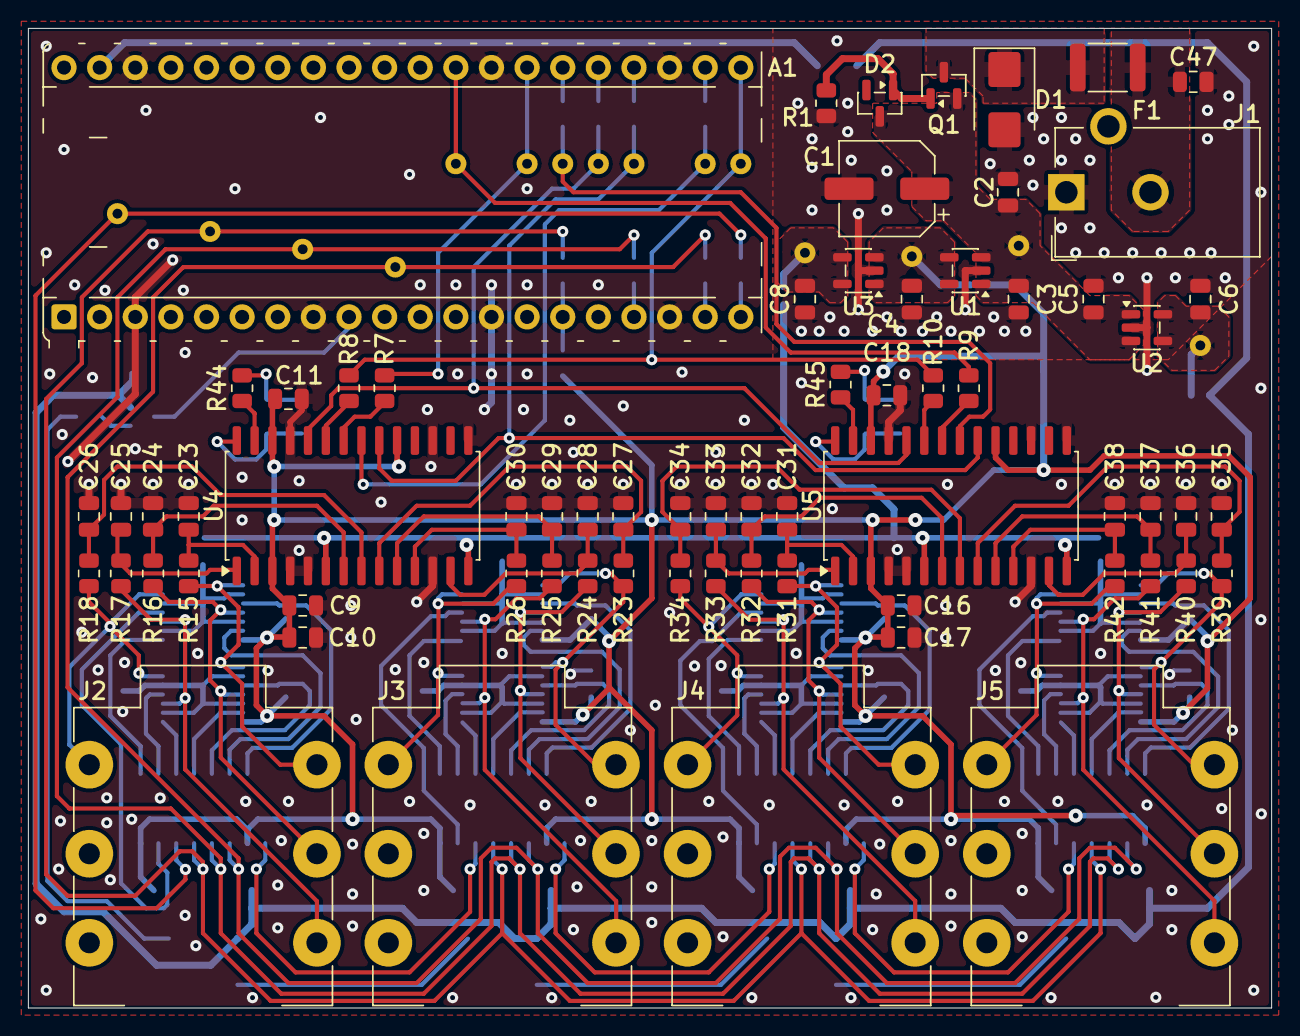
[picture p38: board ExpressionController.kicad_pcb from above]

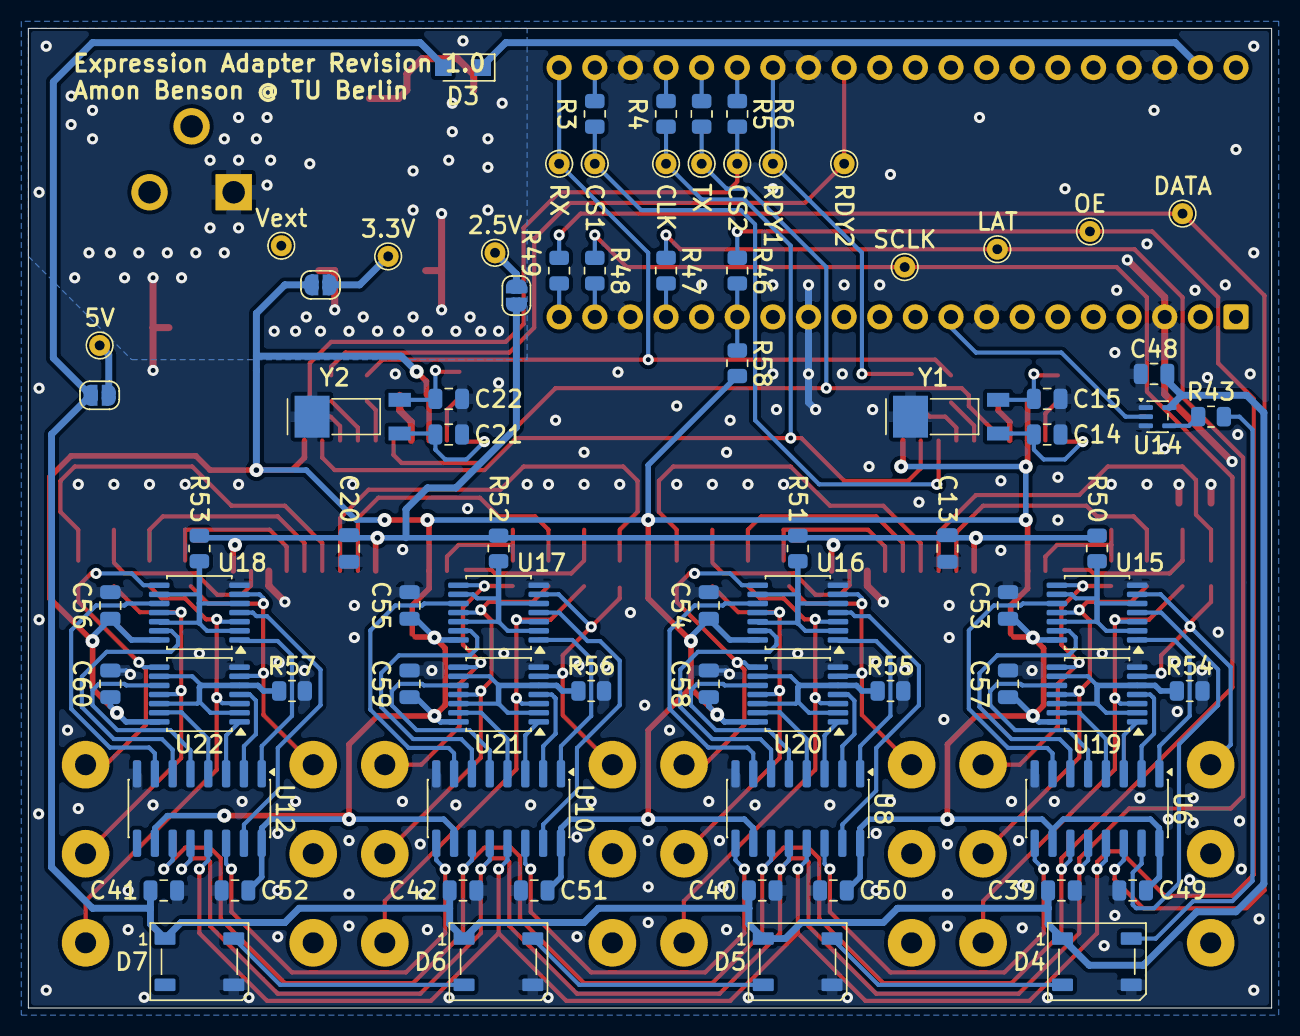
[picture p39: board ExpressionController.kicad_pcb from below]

Board: 2 copper layers, 88.6 x 69.8 mm, 147 parts (79 on the bottom side), 122 nets.

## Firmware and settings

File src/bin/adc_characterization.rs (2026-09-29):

#![no_std]
#![no_main]

use defmt::{info, unwrap};
use embassy_executor::Spawner;
use embassy_time::{Duration, Instant, Timer};
use expad::board::{self, ADC_CHIPS, Contact, JACKS};
use expad::hal::adc::{AdcChain, AdcChainConfig, Coding};
use expad::hal::buf::TriState;

use {defmt_rtt as _, panic_probe as _};

/// Jack the potentiometer pedal is plugged into, and how its contacts are driven: the two
/// track ends to the rails and the wiper left floating, as tracking it would.
const JACK: usize = 0;
const HIGH_CONTACT: Contact = Contact::Ring;
const LOW_CONTACT: Contact = Contact::Sleeve;
const WIPER_CONTACT: Contact = Contact::Tip;

/// Update rates to characterize, one per filter word from the fastest (3) to 6, and 13 (the
/// controller's former rate). Each lands on its filter word after the driver's rounding down
/// of 4096 / rate.
const UPDATE_RATES: [u32; 5] = [1365, 1024, 819, 682, 315];

/// SPI clock (Hz) and chip select guard (µs) compared at [`board::ADC_UPDATE_RATE`]: what the
/// breadboard needed, and the trimmed settings the driver now defaults to.
const SPI_SETTINGS: [(u32, u64); 2] = [(1_000_000, 50), (4_000_000, 10)];

/// Readings of the wiper taken per SPI setting, both switching channels and staying on one.
const COMPARISON_READINGS: usize = 300;

/// Distance from the median, in robust standard deviations, beyond which a reading counts as
/// an outlying code - what too short a chip select guard produced on the breadboard.
const OUTLIER_SIGMAS: f32 = 6.0;

/// Smallest robust standard deviation assumed, in V, so readings that barely move are not all
/// taken for outliers: about one output step at 819 Hz.
const MIN_OUTLIER_SIGMA: f32 = 0.0002;

/// Readings averaged for every rail and self-test value.
const AVERAGED_READINGS: usize = 16;

/// Rounds of tip, ring and sleeve single conversions, as a solver or a multi-jack tracker
/// switching channels would take them.
const SWITCHING_ROUNDS: usize = 150;

/// Consecutive results taken without leaving the wiper channel.
const CONTINUOUS_SAMPLES: usize = 1024;

/// Window of the moving average that notches out mains hum and its harmonics.
const MAINS_FREQUENCY: f32 = 50.0;

#[unsafe(link_section = ".bi_entries")]
#[used]
pub static PICOTOOL_ENTRIES: [embassy_rp::binary_info::EntryAddr; 4] = [
    embassy_rp::binary_info::rp_program_name!(c"ADC Characterization"),
    embassy_rp::binary_info::rp_program_description!(
        c"Measures noise, timing and calibration of the AD7718 at every filter setting on a pedal"
    ),
    embassy_rp::binary_info::rp_cargo_version!(),
    embassy_rp::binary_info::rp_program_build_attribute!(),
];

/// `core` has no floating point square root; Newton's method converges in a handful of
/// steps for the magnitudes seen here.
fn square_root(value: f32) -> f32 {
    if value <= 0.0 {
        return 0.0;
    }
    let mut root = if value > 1.0 { value } else { 1.0 };
    for _ in 0..40 {
        root = 0.5 * (root + value / root);
    }
    root
}

/// Cosine by its Taylor series, accurate for the angles below π this tool needs.
fn cosine(angle: f32) -> f32 {
    let squared = angle * angle;
    let mut term = 1.0;
    let mut sum = 1.0;
    for order in 1..12 {
        term *= -squared / ((2 * order - 1) * (2 * order)) as f32;
        sum += term;
    }
    sum
}

fn squared(value: f32) -> f32 {
    value * value
}

#[derive(defmt::Format)]
struct Statistics {
    /// Mean, in V.
    mean: f32,
    /// Standard deviation around the mean, in µV.
    deviation: f32,
    /// Standard deviation of successive differences over √2, in µV: the sample-to-sample
    /// noise, unaffected by slow drift.
    white: f32,
    /// Smallest nonzero step between two readings, in µV: the output's resolution.
    step: f32,
}

fn statistics(samples: &[f32]) -> Statistics {
    let count = samples.len() as f32;
    let mean = samples.iter().sum::<f32>() / count;
    let variance = samples
        .iter()
        .map(|sample| squared(sample - mean))
        .sum::<f32>()
        / count;

    let differences = samples.windows(2).map(|pair| pair[1] - pair[0]);
    let difference_variance = differences.clone().map(squared).sum::<f32>() / (count - 1.0);
    let step = differences
        .map(f32::abs)
        .filter(|&difference| difference > 0.0)
        .fold(f32::INFINITY, f32::min);

    Statistics {
        mean,
        deviation: square_root(variance) * 1e6,
        white: square_root(difference_variance / 2.0) * 1e6,
        step: step * 1e6,
    }
}

/// Standard deviation of the means of consecutive blocks of `size`, in µV - the noise left
/// after averaging that many results.
fn block_average_deviation(samples: &[f32], size: usize) -> f32 {
    let mut averages = [0.0; CONTINUOUS_SAMPLES];
    let count = samples.len() / size;
    for (average, block) in averages.iter_mut().zip(samples.chunks_exact(size)) {
        *average = block.iter().sum::<f32>() / size as f32;
    }
    statistics(&averages[..count]).deviation
}

/// Standard deviation of a moving average over `window` results, in µV.
fn moving_average_deviation(samples: &[f32], window: usize) -> f32 {
    let mut averages = [0.0; CONTINUOUS_SAMPLES];
    let count = samples.len() - window + 1;
    for (average, run) in averages.iter_mut().zip(samples.windows(window)) {
        *average = run.iter().sum::<f32>() / window as f32;
    }
    statistics(&averages[..count]).deviation
}

/// Amplitude of the `frequency` component of evenly spaced `samples`, in µV (Goertzel).
fn tone_amplitude(samples: &[f32], sample_rate: f32, frequency: f32) -> f32 {
    let mean = samples.iter().sum::<f32>() / samples.len() as f32;
    let coefficient = 2.0 * cosine(2.0 * core::f32::consts::PI * frequency / sample_rate);
    let (mut previous, mut before_previous) = (0.0f32, 0.0f32);
    for sample in samples {
        let current = sample - mean + coefficient * previous - before_previous;
        before_previous = previous;
        previous = current;
    }
    let power = previous * previous + before_previous * before_previous
        - coefficient * previous * before_previous;
    2.0 * square_root(power.max(0.0)) / samples.len() as f32 * 1e6
}

/// How many of `samples` are outlying codes, and how far the worst one lies from the median,
/// in µV.
fn outliers(samples: &[f32]) -> (usize, f32) {
    let count = samples.len();
    let mut sorted = [0.0f32; COMPARISON_READINGS];
    let sorted = &mut sorted[..count];
    sorted.copy_from_slice(samples);
    sorted.sort_unstable_by(f32::total_cmp);
    let median = sorted[count / 2];

    let mut deviations = [0.0f32; COMPARISON_READINGS];
    let deviations = &mut deviations[..count];
    for (deviation, sample) in deviations.iter_mut().zip(samples) {
        *deviation = (sample - median).abs();
    }
    deviations.sort_unstable_by(f32::total_cmp);
    // The median absolute deviation, scaled to a standard deviation for normal noise.
    let sigma = (1.4826 * deviations[count / 2]).max(MIN_OUTLIER_SIGMA);

    let outlying = deviations
        .iter()
        .filter(|&&deviation| deviation > OUTLIER_SIGMAS * sigma)
        .count();
    (outlying, deviations[count - 1] * 1e6)
}

/// Reading time, noise and outlying codes of the wiper under one SPI setting: switching
/// between the three taps as a solve does, then staying on the wiper as tracking one pedal
/// does, which also skips rewriting the control register.
async fn compare_spi(adcs: &mut AdcChain<'_, ADC_CHIPS>, chip: usize, channels: [u8; 3]) {
    let [wiper_channel, high_channel, low_channel] = channels;
    let mut wiper = [0.0f32; COMPARISON_READINGS];

    let started = Instant::now();
    for reading in wiper.iter_mut() {
        *reading = unwrap!(adcs.measure_channel(chip, wiper_channel).await);
        unwrap!(adcs.measure_channel(chip, high_channel).await);
        unwrap!(adcs.measure_channel(chip, low_channel).await);
    }
    let reading_micros = started.elapsed().as_micros() / (3 * COMPARISON_READINGS) as u64;
    let (outlying, worst) = outliers(&wiper);
    info!(
        "  switching: {} us per reading, wiper {}, {} outliers (worst {} uV)",
        reading_micros,
        statistics(&wiper),
        outlying,
        worst
    );

    let started = Instant::now();
    for reading in wiper.iter_mut() {
        *reading = unwrap!(adcs.measure_channel(chip, wiper_channel).await);
    }
    let reading_micros = started.elapsed().as_micros() / COMPARISON_READINGS as u64;
    let (outlying, worst) = outliers(&wiper);
    info!(
        "  same channel: {} us per reading, wiper {}, {} outliers (worst {} uV)",
        reading_micros,
        statistics(&wiper),
        outlying,
        worst
    );
}

async fn average(adcs: &mut AdcChain<'_, ADC_CHIPS>, chip: usize, channel: u8) -> f32 {
    let mut sum = 0.0;
    for _ in 0..AVERAGED_READINGS {
        sum += unwrap!(adcs.measure_channel(chip, channel).await);
    }
    sum / AVERAGED_READINGS as f32
}

/// Ground and reference inputs plus both driven track ends, averaged: the values offset
/// and gain errors show up in.
async fn report_levels(adcs: &mut AdcChain<'_, ADC_CHIPS>, label: &str) {
    let wiring = JACKS[JACK];
    let chip = wiring.adc_chip;
    let ground = average(adcs, chip, board::ADC_GROUND_CHANNEL).await;
    let reference = average(adcs, chip, board::ADC_REFERENCE_CHANNEL).await;
    let high = average(adcs, chip, wiring.adc_channel(HIGH_CONTACT)).await;
    let low = average(adcs, chip, wiring.adc_channel(LOW_CONTACT)).await;
    info!(
        "  {}: ground {}V, reference {}V, high end {}V, low end {}V",
        label, ground, reference, high, low
    );
}

#[embassy_executor::main]
async fn main(_spawner: Spawner) {
    let peripherals = embassy_rp::init(Default::default());
    let wiring = JACKS[JACK];
    let chip = wiring.adc_chip;
    let wiper_channel = wiring.adc_channel(WIPER_CONTACT);
    let high_channel = wiring.adc_channel(HIGH_CONTACT);
    let low_channel = wiring.adc_channel(LOW_CONTACT);

    let mut switches = board::pull_switches(
        peripherals.SPI1,
        peripherals.PIN_14,
        peripherals.PIN_15,
        peripherals.PIN_11,
        peripherals.PIN_13,
    );
    switches.set_output(wiring.switch_chip, HIGH_CONTACT.tap(), TriState::High);
    switches.set_output(wiring.switch_chip, LOW_CONTACT.tap(), TriState::Low);
    unwrap!(switches.update());

    let mut adcs = board::adcs(
        peripherals.SPI0,
        peripherals.PIN_18,
        peripherals.PIN_19,
        peripherals.PIN_16,
        peripherals.PIN_17,
        peripherals.PIN_20,
        peripherals.PIN_21,
        peripherals.PIN_22,
    );
    let base_config = AdcChainConfig::default()
        .with_channel_count(board::ADC_CHANNEL_COUNT)
        .with_reference_voltage(board::REFERENCE_VOLTAGE)
        .with_coding(Coding::Bipolar);

    info!(
        "Jack {}: {} high, {} low, {} as wiper - keep the pedal still",
        JACK, HIGH_CONTACT, LOW_CONTACT, WIPER_CONTACT
    );
    Timer::after_millis(100).await;

    for (spi_frequency, guard_micros) in SPI_SETTINGS {
        let config = base_config
            .with_update_rate(board::ADC_UPDATE_RATE)
            .with_spi_frequency(spi_frequency)
            .with_chip_select_guard(Duration::from_micros(guard_micros));
        unwrap!(adcs.init(config).await);
        info!(
            "=== {} Hz, SPI at {} kHz, chip select guard {} us",
            adcs.update_rate(),
            spi_frequency / 1000,
            guard_micros
        );
        report_levels(&mut adcs, "levels").await;
        compare_spi(&mut adcs, chip, [wiper_channel, high_channel, low_channel]).await;
    }

    let mut wiper = [0.0f32; SWITCHING_ROUNDS];
    let mut positions = [0.0f32; SWITCHING_ROUNDS];
    let mut continuous = [0.0f32; CONTINUOUS_SAMPLES];

    for update_rate in UPDATE_RATES {
        unwrap!(adcs.init(base_config.with_update_rate(update_rate)).await);
        info!("=== {} Hz (calibrated here)", adcs.update_rate());
        report_levels(&mut adcs, "levels").await;

        // Switching channel for every reading, as the solver does.
        let started = Instant::now();
        for round in 0..SWITCHING_ROUNDS {
            let tip = unwrap!(adcs.measure_channel(chip, wiper_channel).await);
            let high = unwrap!(adcs.measure_channel(chip, high_channel).await);
            let low = unwrap!(adcs.measure_channel(chip, low_channel).await);
            wiper[round] = tip;
            positions[round] = (tip - low) / (high - low);
        }
        let reading_micros = started.elapsed().as_micros() / (3 * SWITCHING_ROUNDS) as u64;
        let position = statistics(&positions);
        info!(
            "  switching: {} us per reading, wiper {}, position {} (deviation {} ppm)",
            reading_micros,
            statistics(&wiper),
            position.mean,
            position.deviation
        );

        // Staying on the wiper channel, as a single tracked pedal per ADC can.
        let started = Instant::now();
        unwrap!(
            adcs.measure_continuous(chip, wiper_channel, &mut continuous)
                .await
        );
        let period_micros = started.elapsed().as_micros() as f32 / CONTINUOUS_SAMPLES as f32;
        let sample_rate = 1e6 / period_micros;
        let mains_window = (sample_rate / MAINS_FREQUENCY + 0.5) as usize;
        info!(
            "  continuous: {} us per result, wiper {}",
            period_micros,
            statistics(&continuous)
        );
        info!(
            "  continuous averaged: 4 -> {} uV, 8 -> {} uV, {} (20 ms) -> {} uV; 50 Hz {} uV, 100 Hz {} uV, 150 Hz {} uV",
            block_average_deviation(&continuous, 4),
            block_average_deviation(&continuous, 8),
            mains_window,
            moving_average_deviation(&continuous, mains_window),
            tone_amplitude(&continuous, sample_rate, MAINS_FREQUENCY),
            tone_amplitude(&continuous, sample_rate, 2.0 * MAINS_FREQUENCY),
            tone_amplitude(&continuous, sample_rate, 3.0 * MAINS_FREQUENCY)
        );

        unwrap!(
            adcs.measure_continuous(chip, high_channel, &mut continuous[..256])
                .await
        );
        info!(
            "  continuous high end (1 kΩ source): {}",
            statistics(&continuous[..256])
        );
    }

    // Whether a calibration taken at one filter setting still holds at another.
    let slowest = UPDATE_RATES[UPDATE_RATES.len() - 1];
    let fastest = UPDATE_RATES[0];
    unwrap!(adcs.set_update_rate(fastest));
    info!(
        "=== {} Hz without recalibrating (calibrated at {} Hz)",
        adcs.update_rate(),
        slowest
    );
    report_levels(&mut adcs, "levels").await;

    unwrap!(switches.clear());
    info!("Done");
}

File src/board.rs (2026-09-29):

//! Wiring of the expression controller PCB (hardware/ExpressionController.kicad_pro): which
//! pins, chips and channels every jack's contacts are connected to. Every application builds
//! its drivers through here, so this module is the only place that knows the board.
//!
//! Each jack J2-J5 (left to right on the PCB) has its own analog channel block: a 74HC595 whose outputs
//! drive two TMUX1511 quad switches, one connecting each contact to a shared 1 kΩ pull-up to
//! the 2.5 V reference, the other to a shared 1 kΩ pull-down to ground. Every contact is also
//! read through a 10 kΩ / 10 nF filter by one of two AD7718s. The WS2812B LEDs D4-D7 sit
//! below the jacks in the same order, chained from D4.
//!
//! The PCB is mounted upside down in its case, so the jacks are numbered from J5: jack 1 is
//! J5, jack 4 is J2.

use embassy_rp::Peri;
use embassy_rp::dma::{self, ChannelInstance};
use embassy_rp::gpio::AnyPin;
use embassy_rp::interrupt::typelevel::Binding;
use embassy_rp::peripherals::{
    PIN_6, PIN_11, PIN_13, PIN_14, PIN_15, PIN_16, PIN_17, PIN_18, PIN_19, PIN_20, PIN_21, PIN_22,
    SPI0, SPI1,
};
use embassy_rp::pio::{self, Instance};

use crate::hal::adc::{AdcChain, ChannelCount};
use crate::hal::buf::{PullSwitchChain, ShiftRegisterChain};
use crate::hal::led::{LedStrip, Ws2812Chain};
use crate::topology::ARM_COUNT;
use crate::topology::scanner::JackConfig;

/// Expression pedal jacks on the board (J2-J5).
pub const JACK_COUNT: usize = 4;

/// 74HC595 shift registers in the pull switch chain, one per jack.
pub const SWITCH_CHIPS: usize = JACK_COUNT;

/// AD7718 converters, each reading two jacks.
pub const ADC_CHIPS: usize = 2;

/// WS2812B LEDs, one below each jack.
pub const LED_COUNT: usize = JACK_COUNT;

/// Input mode every AD7718 has to run in: the second jack on each chip uses AIN9.
pub const ADC_CHANNEL_COUNT: ChannelCount = ChannelCount::Ten;

/// ADC inputs tied to ground (AIN6) and to the reference (AIN10) on every chip, which make
/// a free self-test of the whole conversion path.
pub const ADC_GROUND_CHANNEL: u8 = 5;
pub const ADC_REFERENCE_CHANNEL: u8 = 9;

/// Voltage of the ADCs' reference (REFIN1), which is also the rail every pull-up switches to,
/// so every reading is ratiometric to the pull-ups.
pub const REFERENCE_VOLTAGE: f32 = 2.5;

/// Conversions per second the jacks are measured at (filter word 5). A reading takes three
/// conversion periods to settle after a channel change, 4.4 ms here against 10.2 ms at 315 Hz,
/// and still resolves 0.2 mV. Faster words turn much coarser - see docs/fast-tracking.md.
pub const ADC_UPDATE_RATE: u32 = 819;

/// Standard deviation of a single reading at [`ADC_UPDATE_RATE`], in V, measured on the PCB
/// with `adc_characterization` through a pedal (0.39 mV, 0.45 mV sample to sample). Every
/// tolerance the solver applies is derived from it.
pub const ADC_VOLTAGE_NOISE: f32 = 0.0005;

/// Shared pull-up and pull-down resistance of every jack (0.1%), in kΩ.
pub const PULL_RESISTANCE: f32 = 1.0;

/// Series resistance and capacitance of every ADC input's filter, in kΩ and nF.
pub const INPUT_FILTER_RESISTANCE: f32 = 10.0;
pub const INPUT_FILTER_CAPACITANCE: f32 = 10.0;

/// A contact of a jack. Its discriminant is the tap it is switched through on its jack's
/// 74HC595.
#[repr(u8)]
#[derive(Clone, Copy, Debug, PartialEq, Eq, defmt::Format)]
pub enum Contact {
    Tip = 0,
    Ring = 1,
    Sleeve = 2,
    /// The tip's normalling contact, which touches the tip while no plug is inserted.
    TipSwitch = 3,
}

impl Contact {
    pub const ALL: [Contact; 4] = [
        Contact::Tip,
        Contact::Ring,
        Contact::Sleeve,
        Contact::TipSwitch,
    ];

    /// The contacts the solver measures as a jack's arms, in arm order.
    pub const ARMS: [Contact; ARM_COUNT] = [Contact::Tip, Contact::Ring, Contact::Sleeve];

    pub const fn tap(self) -> u8 {
        self as u8
    }
}

/// Where one jack's contacts are wired.
#[derive(Clone, Copy, Debug)]
pub struct JackWiring {
    /// The jack's 74HC595, counted from the microcontroller along the chain.
    pub switch_chip: usize,
    pub adc_chip: usize,
    /// ADC input reading every contact, indexed by [`Contact`] (AIN number minus one).
    pub adc_channels: [u8; 4],
    /// The WS2812B below the jack, counted from the microcontroller along the LED chain.
    pub led: usize,
}
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

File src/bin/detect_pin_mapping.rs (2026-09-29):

#![no_std]
#![no_main]

use defmt::{error, info, unwrap, warn};
use embassy_executor::Spawner;
use embassy_time::{Duration, Instant, Timer};
use expad::board::{self, ADC_CHIPS, Contact, JACKS};
use expad::hal::adc::{AdcChain, AdcChainConfig};
use expad::hal::buf::TriState;

use {defmt_rtt as _, panic_probe as _};

/// Inputs every AD7718 converts in the board's channel mode.
const ADC_CHANNELS: usize = board::ADC_CHANNEL_COUNT.count() as usize;

/// How long a tap is left to settle after its switches change. The slowest node is the ADC
/// input filter charging through the pull resistor, 11 kΩ x 10 nF = 110 µs.
const SETTLE_DELAY: Duration = Duration::from_millis(5);

/// Swing between pulled up and pulled down above which an input counts as following a tap.
/// A directly switched tap swings the whole reference, so anything connected to it through
/// a pedal still clears this comfortably, while floating inputs merely drift.
const RESPONSE_THRESHOLD: f32 = 1.0;

/// Furthest a pulled tap, or a self-test input, may read from its rail.
const RAIL_TOLERANCE: f32 = 0.05;

type Readings = [[f32; ADC_CHANNELS]; ADC_CHIPS];

#[unsafe(link_section = ".bi_entries")]
#[used]
pub static PICOTOOL_ENTRIES: [embassy_rp::binary_info::EntryAddr; 4] = [
    embassy_rp::binary_info::rp_program_name!(c"Pin Mapping Detector"),
    embassy_rp::binary_info::rp_program_description!(
        c"Checks every jack contact's pull switches and ADC input against the board table"
    ),
    embassy_rp::binary_info::rp_cargo_version!(),
    embassy_rp::binary_info::rp_program_build_attribute!(),
];

async fn measure_all(adcs: &mut AdcChain<'_, ADC_CHIPS>) -> Readings {
    let mut readings = [[0.0; ADC_CHANNELS]; ADC_CHIPS];
    for channel in 0..ADC_CHANNELS {
        let voltages = unwrap!(
            adcs.measure_parallel([Some(channel as u8); ADC_CHIPS])
                .await
        );
        for (chip_readings, voltage) in readings.iter_mut().zip(voltages) {
            chip_readings[channel] = unwrap!(voltage);
        }
    }
    readings
}

/// The jack contact the board table puts on an ADC input, if any.
fn wired_to(chip: usize, channel: u8) -> Option<(usize, Contact)> {
    JACKS.iter().enumerate().find_map(|(jack, wiring)| {
        let contact = Contact::ALL
            .into_iter()
            .find(|&contact| wiring.adc_channel(contact) == channel)?;
        (wiring.adc_chip == chip).then_some((jack, contact))
    })
}

/// Whether two contacts are expected to follow each other: the tip and its normalling
/// contact touch while no plug is inserted.
fn normalled(first: Contact, second: Contact) -> bool {
    matches!(
        (first, second),
        (Contact::Tip, Contact::TipSwitch) | (Contact::TipSwitch, Contact::Tip)
    )
}

fn near(voltage: f32, rail: f32) -> bool {
    (voltage - rail).abs() <= RAIL_TOLERANCE
}

/// Reads every AD7718's grounded and reference-tied input, which checks the converters,
/// their reference and the voltage scaling before anything is switched. Returns how many
/// chips failed.
async fn self_test_adcs(adcs: &mut AdcChain<'_, ADC_CHIPS>) -> u32 {
    let mut failures = 0;

    for chip in 0..ADC_CHIPS {
        let ground = unwrap!(adcs.measure_channel(chip, board::ADC_GROUND_CHANNEL).await);
        let reference = unwrap!(
            adcs.measure_channel(chip, board::ADC_REFERENCE_CHANNEL)
                .await
        );

        if near(ground, 0.0) && near(reference, board::REFERENCE_VOLTAGE) {
            info!(
                "ADC {}: ground input {}V, reference input {}V - OK",
                chip, ground, reference
            );
        } else {
            error!(
                "ADC {}: ground input {}V (expected 0V), reference input {}V (expected {}V)",
                chip,
                ground,
                reference,
                board::REFERENCE_VOLTAGE
            );
            failures += 1;
        }
    }

    failures
}

#[embassy_executor::main]
async fn main(_spawner: Spawner) {
    let peripherals = embassy_rp::init(Default::default());

    info!("Initializing pull switches");
    let mut switches = board::pull_switches(
        peripherals.SPI1,
        peripherals.PIN_14,
        peripherals.PIN_15,
        peripherals.PIN_11,
        peripherals.PIN_13,
    );
    unwrap!(switches.clear());

    info!("Initializing ADCs");
    let mut adcs = board::adcs(
        peripherals.SPI0,
        peripherals.PIN_18,
        peripherals.PIN_19,
        peripherals.PIN_16,
        peripherals.PIN_17,
        peripherals.PIN_20,
        peripherals.PIN_21,
        peripherals.PIN_22,
    );
    let adc_config = AdcChainConfig::default()
        .with_channel_count(board::ADC_CHANNEL_COUNT)
        .with_reference_voltage(board::REFERENCE_VOLTAGE);
    unwrap!(adcs.init(adc_config).await);
    info!("ADC full scale: {}V", adcs.full_scale_voltage());

    let mut failures = self_test_adcs(&mut adcs).await;

    info!("Switching every contact to both rails - unplug all jacks for a clean result");
    let started = Instant::now();
    for (jack, wiring) in JACKS.iter().enumerate() {
        for contact in Contact::ALL {
            let tap = contact.tap();

            switches.set_output(wiring.switch_chip, tap, TriState::High);
            unwrap!(switches.update());
            Timer::after(SETTLE_DELAY).await;
            let high = measure_all(&mut adcs).await;

            switches.set_output(wiring.switch_chip, tap, TriState::Low);
            unwrap!(switches.update());
            Timer::after(SETTLE_DELAY).await;
            let low = measure_all(&mut adcs).await;

            switches.set_output(wiring.switch_chip, tap, TriState::HiZ);
            unwrap!(switches.update());

            let expected_chip = wiring.adc_chip;
            let expected_channel = wiring.adc_channel(contact);
            let expected_high = high[expected_chip][expected_channel as usize];
            let expected_low = low[expected_chip][expected_channel as usize];
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

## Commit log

2026-08-06 fixed rust analyzer errors
    [main.rs, quadbuf.rs]
2026-08-06 added ADC SPI interface and basic connection test
2026-08-07 added ADC register HAL
2026-08-07 added ADC configuration
2026-08-07 added filter register to increase update rate
2026-08-07 changed ADC channels to 0-based indexing to match buffer driver
2026-08-08 added resistive network topology resolver
    [main.rs, mod.rs, quadbuf.rs]
2026-08-08 added ADC soft reset
    [mod.rs]
2026-08-08 added calibration routine
2026-08-09 added old hardware directory
    [AnalogFrontend.kicad_sch, AnalogQuadChannel.kicad_sch, ExpressionController.kicad_pcb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]
2026-08-23 added basic WS2812B driver
2026-08-23 added higher-level LED Strip driver
2026-08-23 updated Power input on schematic
    [AnalogFrontend.kicad_sch, AnalogQuadChannel.kicad_sch, Microcontroller.kicad_sch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]
2026-08-23 reworked power protection circuit and fixed ERC errors
    [AnalogFrontend.kicad_sch, AnalogQuadChannel.kicad_sch, ExpressionController.kicad_pcb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]
2026-08-23 added basic PCB ordering
    [AnalogFrontend.kicad_sch, ExpressionController.kicad_pcb, Microcontroller.kicad_sch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]
2026-08-23 added power consumption measurements and board outline
    [Expad Power Consumption.xlsx, ExpressionController.kicad_pcb]
2026-08-24 fixed clamping issue with potentiometer script
    [potentiometer.rs]
2026-08-24 added all footprints, updated to 0805, added layout for Jacks
    [AnalogFrontend.kicad_sch, AnalogQuadChannel.kicad_sch, ExpressionController.kicad_pcb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]
2026-08-25 more progress in layout
    [AnalogQuadChannel.kicad_sch, ExpressionController.kicad_pcb, Microcontroller.kicad_sch]
2026-08-27 more routing changes
    [ExpressionController.kicad_pcb]
2026-08-27 very tight layout
    [AnalogFrontend.kicad_sch, ExpressionController.kicad_pcb]
2026-08-30 schematic updates
    [AnalogFrontend.kicad_sch, AnalogQuadChannel.kicad_sch, ExpressionController.kicad_pcb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]
2026-08-30 replaced buffer ICs with analog switches, schematic bugfixes, started new routing
    [AnalogFrontend.kicad_sch, AnalogQuadChannel.kicad_sch, ExpressionController.kicad_pcb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]
2026-09-02 new PCB updates
    [AnalogFrontend.kicad_sch, AnalogQuadChannel.kicad_sch, ExpressionController.kicad_pcb]
2026-09-04 added mouser part numbers
    [AnalogFrontend.kicad_sch, AnalogQuadChannel.kicad_sch, Expad Power Consumption.xlsx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]
2026-09-04 added all footprints and parts
    [AnalogFrontend.kicad_sch, AnalogQuadChannel.kicad_sch, ExpressionController.kicad_pcb]
2026-09-04 updated Pico footprint
    [ExpressionController.kicad_pcb]
2026-09-04 more routing
    [AnalogFrontend.kicad_sch, AnalogQuadChannel.kicad_sch, ExpressionController.kicad_pcb]
2026-09-04 more routing of input 3 and 4
    [ExpressionController.kicad_pcb]
2026-09-04 more routing progress
    [AnalogFrontend.kicad_sch, ExpressionController.kicad_pcb, Microcontroller.kicad_sch]
2026-09-04 everything except ground connected
    [ExpressionController.kicad_pcb]
2026-09-04 nightly progress
    [ExpressionController.kicad_pcb]
2026-09-05 started to fix DRC errors
    [ExpressionController.kicad_pcb]
2026-09-05 DRC passing, test-points missing
    [ExpressionController.kicad_pcb]
2026-09-05 added testpoints
    [ExpressionController.kicad_pcb, Microcontroller.kicad_sch, Power.kicad_sch]
2026-09-05 final board, pinouts unchecked
    [ExpressionController.kicad_pcb, Microcontroller.kicad_sch, Power.kicad_sch]
2026-09-06 generated final assembly files
    [AnalogQuadChannel.kicad_sch, ExpressionController.kicad_pcb, ExpressionController.xlsx]
2026-09-16 after final fab order
    [ExpressionController.xlsx]
2026-09-16 added midi via USB driver
2026-09-17 added huge web interface color redesign
    [mod.rs]
2026-09-18 tested on the board with wiper and everything
2026-09-25 added new analog switch driver
2026-09-25 added automatic switch between full topology detection and wiper measurement to drastically improve the speed.
2026-09-25 added support for switches and rheostats
2026-09-25 some rework on the UI behavior
    [expression_controller.rs, mod.rs]
2026-09-26 fixed USB overflow error on Mac OS
    [expression_controller.rs, mod.rs]
2026-09-28 added no-wifi feature to main firmware, updates to measurement plan
    [ExpressionController.xlsx]
2026-09-28 updated LED color behavior and small refactor of the related modules
    [ExpressionController.xlsx]
2026-09-28 added final presentation template, added supply rail measurements
    [ExpressionController.xlsx]
2026-09-28 added supply noise plots
    [ExpressionController.xlsx, supply_rail_measurement.xlsx]
2026-09-29 added web server and some bugfixes with specific Pedal models
    [access_point.rs, board.rs, expression_controller.rs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]
2026-09-29 added measurment with rail refresh
2026-09-29 added spi rising edge near capture
2026-09-29 added spi edges plot
2026-09-30 last minute fix, tracking maximum voltage range threshold increased to fix spurious dropouts/loss of tracking
2026-10-13 fixed schematic page rendering
2026-10-14 implementation updates and appendix PCB layers
2026-10-14 added signed declaration and updated schematic names
